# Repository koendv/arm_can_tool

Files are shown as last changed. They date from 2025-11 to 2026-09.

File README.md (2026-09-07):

# ARM CAN TOOL — Overview

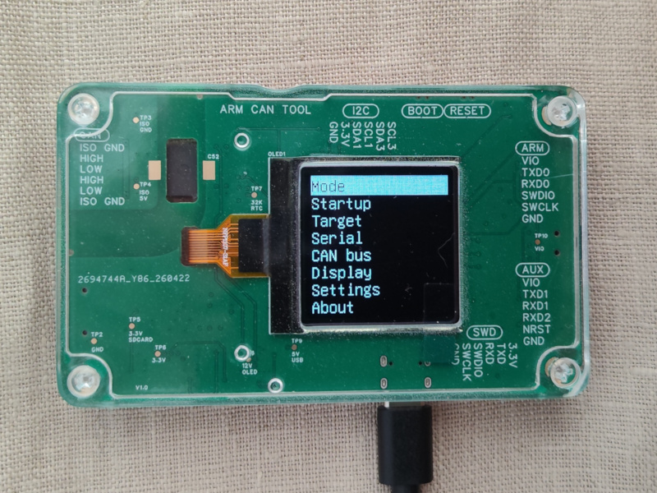
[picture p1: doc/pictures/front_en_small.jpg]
English
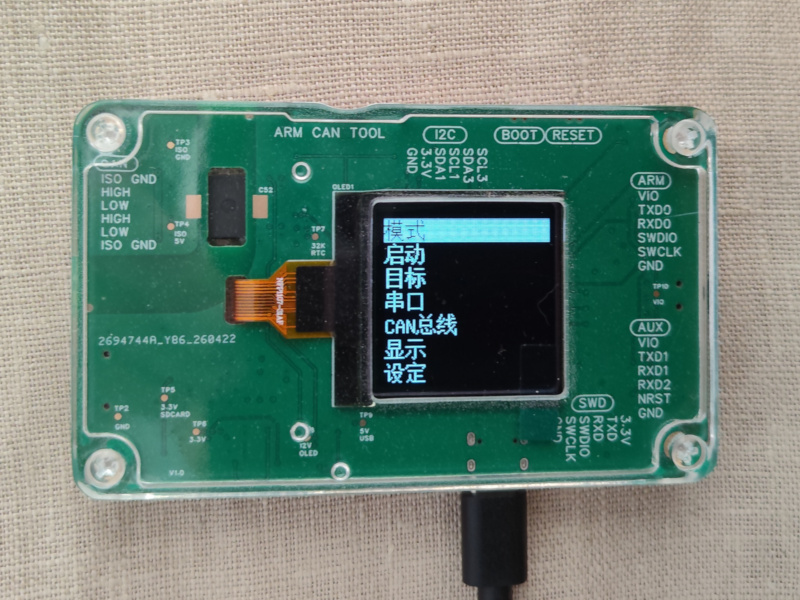
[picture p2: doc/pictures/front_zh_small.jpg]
Chinese
|||
|---|---|
|`English`|`Chinese`|

| Model | ARM CAN Tool |
|-|-|
| Hardware Version | V1.0 |
| Firmware Version | V1.4 |

- SWD/JTAG debug probe for ARM and RISC-V embedded systems
- Electrically isolated CAN 2.0A/B interface
- Debug output and CAN bus traffic merged into single USB serial log stream
- Standalone semihosting: target stdout, file I/O, and clock — no PC required
- ARM DWT program counter and exception trace
- Lua scripting for standalone use
- Automated logging to SD card
- User interface in English and simplified Chinese
- Documentation covers Linux host

---

## Quick Start

| Situation | Start here |
|---|---|
| Board has no firmware | [INSTALL](doc/INSTALL.md) |
| Board has firmware, want to use it | [TUTORIAL](doc/TUTORIAL.md) |
| Want to reproduce the board | [MANUFACTURING](doc/MANUFACTURING.md) |
| Want to sell the board | [COMMERCIAL](doc/COMMERCIAL.md) |
| Want to build or modify the firmware | [DEVELOPER](doc/DEVELOPER.md) |

---

## Document Map

This documentation is published as a set of Markdown files, and as an epub.

- [INSTALL](doc/INSTALL.md) — Install the UF2 bootloader and application firmware. Begin here if the board came from PCB assembly with no firmware.
- [TUTORIAL](doc/TUTORIAL.md) — A first session: wire a target, flash firmware, read the console, capture CAN frames, and log to SD card. Begin here if the board already has firmware installed.
- [OPERATION](doc/OPERATION.md) — How the device interface works: operating modes, OLED menu, serial ports, target power, and startup services.
- [DEBUG](doc/DEBUG.md) — Debug workflows using Black Magic Debug or CMSIS-DAP, plus memwatch, RTT, SWO, and MTB.
- [TARGETS](doc/TARGETS.md) — Supported targets.
- [CANBUS](doc/CANBUS.md) — The CAN bus interface: isolation, protocols, hardware filters, and logging.
- [SCRIPT](doc/SCRIPT.md) — Lua scripting: event model, deployment workflows, and flash sector layout.
- [LOGGING](doc/LOGGING.md) — SD card logging: file formats, retrieval, and combined log streams.
- [HARDWARE](doc/HARDWARE.md) — Hardware design, connectors, isolation, power, EMI, and repair.
- [SCHEMATIC](doc/SCHEMATIC.md) — PCB schematic.
- [AI](doc/AI.md) — How to use AI-assisted PCB design review and repair.
- [REMOTE](doc/REMOTE.md) — Console port use.
- [DEVELOPER](doc/DEVELOPER.md) — Build the firmware from source, software architecture, and internals.
- [MANUFACTURING](doc/MANUFACTURING.md) — Order PCBs, source components, assemble the enclosure, and install firmware.
- [LICENSE](LICENSE.md) — License terms for original work (CC0) and third-party components.
- [COMMERCIAL](doc/COMMERCIAL.md) — License terms, estimated cost, supply chain notes, and reseller information.
- [REFERENCE](doc/REFERENCE.md) — Static facts: connector pinouts, electrical parameters, and PCB parameters.
- [LUA REFERENCE](doc/LUA_REF.md) — Lua function reference.

---

## Specifications

| Parameter | Value |
|---|---|
| MCU | AT32F405, ARM Cortex-M4, 216 MHz |
| USB | USB 2.0 High Speed, 480 Mbit/s |
| Debug interfaces | SWD, JTAG |
| Target logic voltage range | 1.1 V – 3.6 V |
| Target power | 3.3 V, up to 100 mA |
| CAN interface | CAN 2.0A/B, up to 1,000,000 bit/s, electrically isolated |
| Storage | SD card, 16 MB SPI flash, 16 MB QSPI flash, EEPROM |
| Display | 1.5 inch OLED, 128×128, monochrome |
| Input | Multi-direction switch (up / down / press) |
| Firmware update | UF2 via USB mass storage |
| License | CC0 (Public Domain) |

---

## License

[CC0](https://creativecommons.org/publicdomain/zero/1.0/). Use, modify, and sell without restriction.

## Online Resources

| Resource | Location |
|---|---|
| Firmware source | [github arm_can_tool](https://github.com/koendv/arm_can_tool) |
| Bootloader source | [github at32f405-uf2boot](https://github.com/koendv/at32f405-uf2boot) |
| Hardware design | [oshwlab arm_can_tool](https://oshwlab.com/koendv/arm_can_tool) |

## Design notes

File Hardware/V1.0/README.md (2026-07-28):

# Manufacturing Instructions

## Quick Order Checklist

1. PCB: `Hardware/V1.0/4_GERBER/Gerber_PCB1_2026-04-13.zip`
2. BOM: `Hardware/V1.0/3_BOM/BOM_Board1_PCB1_2026-04-13.xlsx`
3. Pick & Place: `Hardware/V1.0/3_BOM/PickAndPlace_PCB1_2026-04-13.xlsx`
4. Enclosure STL: `Hardware/V1.0/5_3D/enclosure/`
5. Firmware: `Hardware/V1.0/7_FW/

## Assembly Notes

| component | note                                                   |
+-----------+--------------------------------------------------------|
| BT1       | No solder paste on middle pad of battery connector BT1 |
| OLED1     | DNS.                                                   |

## User responsibility

The PCB is shipped without pre-programmed firmware. The user is responsible for:

1. attaching OLED display (double-sided adhesive tape, FPC connector)
2. installing UF2 bootloader (one time, via DFU)
3. installing application firmware (routine, via USB copy)
4. 3D-printing the enclosure (SLA)

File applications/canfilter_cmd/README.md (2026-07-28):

# canfilter

**canfilter** is an RT-Thread MSH shell command for managing the bxCAN hardware acceptance filter. canfilter accepts human-readable CAN bus IDs and ID ranges and programs them into the canbus hardware filter configuration.

## Usage

```
canfilter [OPTIONS] [IDs/RANGES]
```

IDs: Single CAN IDs (0x100, 256)

RANGES: CAN ID ranges (0x100-0x1FF, 256-511)

| Option | Long form | Description |
| --- | --- | --- |
| -a | --allow-all | Allow all packets |
| -d | --dry-run | Print filter configuration without programming hardware |
| -v | --verbose | Enable verbose output (repeat up to three times) |
| -h | --help | Show help |

- Single IDs are interpreted as standard if <= 0x7FF, extended if <= 0x1FFFFFFF.
- Hex numbers are supported (prefix `0x`).
- Ranges are interpreted as extended if either bound is an extended ID.
- Repeating `-v` up to three times increases verbosity:
  - `-v` prints filter usage and programming result.
  - `-v -v` also prints a human-readable decode of each filter bank.
  - `-v -v -v` also dumps the raw hardware registers.

The filter takes effect on the next CAN bus start. To make the filter persistent across reboots, store settings using the menu or the rt-thread `settings` command.

## Examples

Allow a single standard ID:

```
canfilter 0x100
```

Program a standard ID range:

```
canfilter 0x100-0x1FF
```

Program mixed standard and extended IDs:

```
canfilter 0x100 0x200-0x2FF 0x1000 -v
```

Print filter configuration without programming hardware:

```
canfilter -d -v -v -v 0x101-0x1fe
```

Allow all traffic:

```
canfilter -a
```

## Source files

| File | Description |
| --- | --- |
| `canfilter_cmd.c` | MSH command, argument parsing, calls `can_set_filter()`  |
| `canfilter_bxcan_f0.c` | bxCAN filter builder: CIDR decomposition, bank packing  |
| `canfilter_bxcan_f0.h` | Public API for the filter builder |
| `canfilter.h` | Hardware filter struct definitions (`can_filter_t` etc.) |

## bxCAN filtering

bxCAN uses mask-based filtering. It has no native range support, so ranges are decomposed into a minimal set of (ID, mask) pairs using a CIDR aggregation algorithm — the same technique used for IP network prefix compression.

Each hardware filter bank holds either four standard IDs (16-bit list mode), two standard (ID, mask) pairs (16-bit mask mode), two extended IDs (32-bit list mode), or one extended (ID, mask) pair (32-bit mask mode). The builder packs entries as efficiently as possible.

The STM32F0/F1/F3 bxCAN peripheral has 14 filter banks. Filter usage is printed after every successful `canfilter` invocation. CIDR-aligned ranges use fewer banks:

```
canfilter -d 0x100-0x1FF
Filter usage: 1/14 (7%)

canfilter -d 0x101-0x1FE
Filter usage: 7/14 (50%)
```

The second range uses more banks because its boundaries are not aligned to a power-of-two block. If you run out of filter banks, consider adjusting your ranges to start and end on power-of-two boundaries.

## Notes

The core idea behind **canfilter** is that CAN bus hardware filters (ID + mask) are mathematically equivalent to IP network blocks (network + prefix). Because of this equivalence, CIDR aggregation — a mature algorithm for converting IP addresses and ranges into minimal sets of network blocks — can be applied directly to CAN identifiers.

The masks generated follow the same structure as IP network masks: a contiguous run of 1-bits from the most significant bit marking the portion of the CAN ID that must match, followed by 0-bits representing don't-care positions. A mask of all zeroes matches any CAN ID.

SEE ALSO

[canfilter](https://github.com/koendv/canfilter)

## License

Public domain — [CC0 1.0 Universal](https://creativecommons.org/publicdomain/zero/1.0/).

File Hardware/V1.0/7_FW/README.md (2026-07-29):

# Firmware for ARM CAN Tool V1.0

## Governing Principle

The AT32F405 processor uses two separate memory regions for firmware. The internal flash (256 kB) contains the UF2 bootloader, installed once via DFU. The QSPI flash (16 MB) contains the application firmware, updated by copying a UF2 file to a USB mass storage device.

## Prerequisites

- `dfu-util` installed (`sudo apt install dfu-util` on Debian-based systems)
- USB cable (data-capable)
- Ability to identify and press [RESET] and [BOOT0] buttons on the board

## File Overview

Download from [Releases](https://github.com/koendv/arm_can_tool/releases):

| File | Purpose |
|---|---|
| `cherryuf2_arm_can_tool.bin` | UF2 bootloader |
| `rtthread.uf2` | Application firmware |

---

## Installing the UF2 Bootloader (One Time Only)

**Governing Principle:**
The AT32F405 contains a factory DFU bootloader accessible by holding [BOOT0] during reset. The UF2 bootloader is written to internal flash using `dfu-util`.

**Prerequisites:**
- `dfu-util` installed
- Board connected via USB
- `cherryuf2_arm_can_tool.bin` downloaded from [at32f405-uf2boot Releases](https://github.com/koendv/at32f405-uf2boot/releases)

**Procedure:**
1. Press and hold [RESET] and [BOOT0] simultaneously.
2. Release [RESET] after one second.
3. Release [BOOT0] after one further second.

The board is now in DFU mode.

**Verification:**
```bash
$ lsusb | grep Artery
Bus 003 Device 012: ID 2e3c:df11 Artery-Tech DFU in FS Mode
```

**Procedure (continued):**
4. Write the bootloader binary:
```bash
dfu-util -a 0 -d 2e3c:df11 --dfuse-address 0x08000000 \
         -D cherryuf2_arm_can_tool.bin
```

**Expected output:**
```
Erase       [=========================] 100%        23692 bytes
Erase    done.
Download    [=========================] 100%        23692 bytes
Download done.
File downloaded successfully
```

**Verification:** The bootloader requires installation only once. Normal boot (without [BOOT0] held) starts the application.

⚠️ **Warning: Linux USB Access**

**If ignored:** `dfu-util` reports "No DFU capable USB device found"

**Correct practice:** Add udev rule:
```bash
echo 'SUBSYSTEMS=="usb", ATTRS{idVendor}=="2e3c", ATTRS{idProduct}=="df11", TAG+="uaccess", MODE="0664", GROUP="plugdev"' | sudo tee /etc/udev/rules.d/99-at32.rules
sudo udevadm control -R
```

**Complete precautions:** See [HARDWARE.md#usb-dfu-setup]

---

## Installing the Application Firmware (Routine)

**Governing Principle:**
The UF2 bootloader presents the QSPI flash as a USB mass storage device. The application firmware installs by copying a UF2 file to this device.

**Prerequisites:**
- UF2 bootloader installed (see previous section)
- Board connected via USB
- `rtthread.uf2` downloaded from [Releases](https://github.com/koendv/arm_can_tool/releases)

**Procedure:**
1. Press and hold [RESET] and the multi-direction switch simultaneously.
2. Release [RESET] after one second.
3. Release the multi-direction switch after one further second.

The green LED illuminates. A USB mass storage device named `CherryUF2` appears.

**Verification:**
```bash
$ ls /media/$USER/CherryUF2/
CURRENT.UF2
```

**Procedure (continued):**
4. Copy the application firmware:
```bash
cp rtthread.uf2 /media/$USER/CherryUF2/CURRENT.UF2
```

**Expected behavior:**
- LED blinks during programming
- Board resets automatically when complete
- OLED display shows the main menu

**Verification:** The serial console (SWD connector, 115200 baud) displays:
```
I/MAIN: ready
```

---

## Troubleshooting

| Observed Result | Possible Cause | Corrective Action |
|---|---|---|
| `CherryUF2` drive does not appear | UF2 bootloader not installed | Install bootloader (see previous section) |
| `dfu-util` reports no device | Missing udev rule or driver | Apply udev rule (Linux) or use Zadig (Windows) |
| Copy operation fails | Loose USB connection | Use different cable or USB port |
| OLED remains blank after reset | Application firmware corrupt | Re-enter UF2 mode and copy `rtthread.uf2` again |

---

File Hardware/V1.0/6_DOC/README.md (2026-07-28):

# PCB Analysis YAML — AI Assistant Guide

Upload `pcb_analysis.yaml` to an AI chatbot and have a technical conversation about your board — design review, signal integrity, power, EMC, BOM, firmware bring-up. The AI gets full context in one file.

Component datasheets are in `6_DOC/datasheets/`.

---

## Quick Start

1. Open [claude.ai](https://claude.ai) (or any capable AI chatbot)
2. Upload `pcb_analysis.yaml` as an attachment
3. Start broad: *"Assess this PCB. Project description is at https://github.com/koendv/arm_can_tool"*

The AI now has full context and you can drill down from there.

---

## Example Prompts

> *"What items in the design checklist still require action before I send to fab?"*

> *"What are the main functional blocks of this board and how are they connected?"*

> *"Which nets need controlled impedance routing, and what trace width should I use?"*

> *"Are there any assembly notes I need to communicate to the fab?"*

> *"I've attached the datasheets for U5 (SD8931) and its alternate (DS3231MZ). Compare and assess what would need to change to swap them."* (Note: the DS3231MZ datasheet is in English, the SD8931 in Chinese — the AI handles both.)

> *"I've attached the CA-IS2062VW datasheet. Check the schematic for U3 against the reference application circuit."*

> *"Assume CAN bus transceiver creepage is 9mm, clearance is 7mm, and PCB has CTI≥175V. Assess according to IEC 60664-1."*

---

## Tips for Better Conversations

**Be specific about the subsystem.** The AI can focus better when you name a block:
> *"Focus on the I2C bus. Which devices share I2C1, and are the pull-up resistors sized correctly?"*

**Ask for a checklist.**
> *"Create a pre-fab checklist based on the open items in this design."*

**Use the embedded datasheets.** Every component in the YAML includes a datasheet URL. Ask the AI to fetch and cross-reference them:
> *"Check the datasheet for U3 and verify the decoupling capacitors match the recommended application circuit."*

**Attach additional documents sparingly.** You can upload datasheets or reference manual sections alongside the YAML. Avoid uploading an entire MCU reference manual — extract and upload only the relevant section, for example the QSPI/XIP chapter when working on flash memory bring-up.

**Use alternate parts for cost reduction.** The YAML includes schematic-documented alternates with LCSC part numbers. Two levels of search:

Focused — uses only designer-validated alternates already in the schematic:
> *"Using the alternate parts listed in the schematic, consider replacing parts with Chinese domestic alternatives. Give BOM savings."*

Open — broader search for any cheaper compatible part on LCSC:
> *"Search LCSC for cheaper Chinese domestic alternatives to any part in the BOM. Include the schematic's documented alternates and any other compatible parts you find. Give BOM savings."*

The focused query is safer and faster. The open query may find additional savings but results need engineering review before production.

**Iterate.** The AI retains the YAML context for the whole conversation. You can ask follow-up questions without re-uploading.

---

## Generating pcb_analysis.yaml

To regenerate this file for this board, or create one for a different EasyEDA Pro project:

1. Export BOM, netlist, and pick & place files from EasyEDA Pro
2. Run [easyeda_parser](https://github.com/koendv/easyeda_parser)
3. Upload the schematic PDF and the parser output
4. Merge into `pcb_analysis.yaml`

---

*Project: `arm_can_tool` · Author: koendv · License: [CC0 Public Domain](https://creativecommons.org/publicdomain/zero/1.0/)*

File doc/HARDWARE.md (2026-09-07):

# ARM CAN TOOL — Hardware Reference

> Workflow is not: Given specifications, design hardware.

> Workflow is: Given product concept and manufacturing process, extract full performance.

> If the solution is complex, backtrack to when it was simple.

**Hardware Revision:** v1.0

**Intended Readers:** Electronics engineers evaluating the design, planning a board modification, or selecting components for production.

---

## Prerequisites

**Knowledge:**

- Basic electronics measurement (multimeter use)
- SMD soldering and rework
- I2C and SPI interfaces

**Equipment:**

- Multimeter
- USB-C cable
- Terminal emulator (Linux: minicom; Windows: PuTTY)
- Oscilloscope or frequency counter (crystal verification)

---

## Design Principles

### Hardware Policy

Hardware has to be right the first time. Software we can always update later.

### Second Source Components

Single-source components are a supply chain risk. Where possible, components have a second source.

| Component | Primary | Second Source |
| --- | --- | --- |
| AT32F405 MCU | Artery Technology | None ⚠️ |
| CA-IS2062VW CAN transceiver | Chipanalog | CA-IS3062VW (drop-in), NSIP9042V-DSWR (pin-compatible) |
| SH1107 128×128 OLED display | Zhongjingyuan (中景园) | None. Alternative requires connector and/or driver change. |

Monitor stock before committing to a production run.

### Economy Assembly

Design targets JLCPCB Economy PCBA throughout.

- All components are SMD. No through-hole parts, no headers, no press-fit connectors.
- Board leaves SMT assembly 100% soldered. Manual steps after assembly: attach OLED display (plug-in FPC), close enclosure.
- All connectors are JST GH 1.25 mm pitch, 6-pin.
- OLED uses a plug-in FPC connector. Reason: JLCPCB economy assembly does not include hot-bar soldering.
- All components are either stocked by JLCPCB, available for consignment or both.
- No conformal coating, no selective soldering, no unusual PCB finishes.
- PCB stackup JLC04161H-7628 (4-layer) is a standard JLCPCB offering. Standard stackup avoids surcharges and provides consistent impedance control across repeat orders.

### Simple Solutions Preferred

If a simple approach solves 90% of use cases, do not choose a complex approach to solve 95%.

### Accept Hardware Limitations

The cost and complexity of upgrading or supplementing a component are often underestimated. Accept the limitation instead, and extract full performance from what is fitted. Example: the AT32F405 supports CAN 2.0 but not CAN FD. Alternatives — a more capable MCU (STM32U595) or an external CAN FD controller (MCP2518FD) — increase cost or complexity. Instead, accept CAN 2.0 and use the controller to full capacity: use AT32 HAL instead of rt-thread, use hardware filtering instead of software filtering. No CPU load. Lean and cheap.

### PCB Layout

A well-routed board and a poorly-routed board cost the same to manufacture.

### Repairability

Component placement provides practical rework access — sufficient clearance to drag a soldering iron across the pins of every SOIC and LQFP package. The processor area accommodates an LQFP-64 10×10 mm body without moving other components, permitting a processor swap on a future board spin.

LQFP-64 package selection:

| Package | Assessment |
| --- | --- |
| LQFP-48 | Insufficient pin count |
| LQFP-64 | Sufficient pins, hand-solderable, hand-reworkable |
| LQFP-100 and above | Excess pins, higher cost, reduced reworkability |

### Debug Interface

The debug interface supports up to four bidirectional pins, each with individual level translation and direction control. This accommodates SWD, JTAG, and manufacturer-proprietary debug protocols without hardware changes.

A SWD-only design could connect SPI MOSI and MISO directly to the target SWDIO. This was considered and rejected. Four GPIOs are used, with voltage translation and individual direction control, to permit programming of devices using proprietary protocols.

All four signal pins and their four direction control pins are on GPIO port A (PA0–PA7). A single register write updates all eight pins simultaneously. See [bit-banging](DEVELOPER.md#gpio-and-bit-banging).

---

## Design Files

| Resource | Location |
| --- | --- |
| Schematics and Gerbers | [Design files](https://github.com/koendv/arm_can_tool/tree/main/Hardware) |
| EasyEDA / OSHWLab project | [oshwlab.com/koendv/arm_can_tool](https://oshwlab.com/koendv/arm_can_tool) |

Designed using [EasyEDA Pro](https://pro.easyeda.com/). All design files published under CC0.

---

## Block Diagram

Block diagram

*System block diagram.*

The board contains two SPI flash chips. The 16 MB QSPI flash stores firmware and is executed in place (XIP) at 108 MHz. The 16 MB SPI flash stores data such as log files and Lua scripts. The QSPI flash is written by the bootloader. The SPI flash is managed by the rt-thread filesystem.

---

## Processor

The [AT32F405](https://www.arterychip.com/en/product/AT32F405.jsp) is an ARM Cortex-M4 microcontroller manufactured by Artery Technology (雅特力).

| Parameter | Value |
| --- | ----- |
| Core | ARM Cortex-M4 |
| Clock | 216 MHz |
| RAM | 102 kB (parity check disabled) / 96 kB (parity check enabled) |
| Internal flash | 256 kB (6 wait states at 216 MHz; prefetch buffers enabled) |
| USB | High Speed (480 Mbit/s) and Full Speed, internal PHY |
| QSPI | Four-wire, up to 108 MHz |
| Package | LQFP-64, 7×7 mm body |

> The AT32F405 has 102 kB RAM when RAM parity check is disabled (the default). If the bootloader reports `96k ram`, the processor option bits require a reset.

### Processor Evaluation

The AT32F405 satisfies the combined ARM debug and CAN 2.0 probe use case: USB High-Speed with integrated PHY, Cortex-M4 at 216 MHz, and LQFP-64 package. CAN FD is not supported.

CAN FD support would require:

- Transceiver change to NSIP9042-DSWR
- Common mode choke change to ACT1210D-510-2P-TL00
- Processor with CAN FD capability

No current AT32 device offers both USB High-Speed and CAN FD. The AT32F456/F457 add CAN FD but revert to Full-Speed USB, making them unsuitable for this application. A pin-compatible AT32F405 variant with CAN FD would close this gap, but no such part currently exists.

### Processor Replacement

If the AT32F405 becomes unavailable or a CAN FD variant is required, the replacement must satisfy:

- USB High-Speed (not Full-Speed) with integrated PHY
- CAN FD
- LQFP-64 package preferred
- rt-thread BSP available (official or community)

Candidate devices include Nuvoton M3334SIGAE (community rt-thread BSP: [github.com/wosayttn/sdk-bsp-numaker-m3334ki](https://github.com/wosayttn/sdk-bsp-numaker-m3334ki)), STM32U595RJT6.

A PCB respin is required for a different processor. The current board layout has sufficient clearance around the processor footprint to accommodate an LQFP-64 10×10 mm body without moving other components. A 10×10 mm body increases pin pitch, which may permit HASL PCB finish in place of ENIG, reducing cost.

---

## Storage

| Device | Interface | Capacity | Purpose |
| --- | --- | --- | --- |
| W25Q128JVSIQ | QSPI, 108 MHz | 16 MB | Firmware storage, XIP execution |
| W25Q128JVSIQ | SPI | 16 MB | Filesystem (log files, scripts). May be partitioned for target firmware image storage. |
| SD card | SPI | User supplied | Removable log and script storage |
| 24C64 EEPROM | I2C | 64 kbit (8 kB) | Device settings |
| SD8931 | I2C | 70 bytes | Unused |

---

## Connectors and Pinouts

All connectors are JST GH 1.25 mm pitch, 6-pin.

For a quick-reference pinout table, see [REFERENCE.md](REFERENCE.md).

**ARM Connector**: Provides the debug interface to the target. In SWD mode, pins 2 and 3 carry serial0 (target console). In JTAG mode, pins 2 and 3 carry TDI and TDO.

⚠️ **Warning: serial0 and JTAG pin contention.**
In JTAG mode, the UART peripheral and the JTAG driver both attempt to drive pins 2 and 3 simultaneously. This causes electrical contention and possible damage. Disable serial0 before switching to JTAG mode: `Serial → Serial Enable → serial0 → Off`.

Pinout: see [REFERENCE.md](REFERENCE.md#arm-pinout).

**AUX Connector**: Provides serial1, serial2 (SWO), and the target reset signal.

Pinout: see [REFERENCE.md](REFERENCE.md#aux-pinout).

**SWD Connector (Probe Self-Debug)**: The debug interface of the AT32F405 itself — for debugging the probe firmware, not the target. Console: 115200 baud, 8N1.

Pinout: see [REFERENCE.md](REFERENCE.md#probe-swd-pinout).

**CAN Bus Connector**: Carries the isolated CAN signals. CAN_HIGH and CAN_LOW are duplicated on two pin pairs for daisy-chain wiring.

Pinout: see [REFERENCE.md](REFERENCE.md#can-bus-pinout).

> No internal terminating resistors. If the probe is the last device on the bus and termination is required, connect 120 Ω across CAN_HIGH and CAN_LOW at the connector.

### CAN Bus Adapter Cable

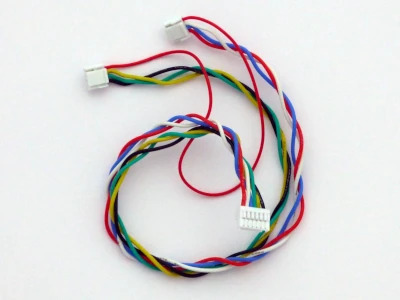
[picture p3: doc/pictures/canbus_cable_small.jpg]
CAN bus cable


*CAN bus adapter cable.*

The CAN bus connector is 6-pin GH1.25. An adapter cable is required to connect to a standard 4-Pin GH1.25 CAN bus.

| Option | Notes |
| --- | ----- |
| [LCSC custom cables](https://www.lcsc.com/customcables) | Suitable for production quantities. |
| AliExpress "GH1.25 Connectors and Pre-Crimped Silicone Cables" | Suitable for individual users. |

Wiring diagram: [canbus_cable.pdf](pictures/canbus_cable.pdf)

**I2C Connector.** May be used as two independent I2C buses, or as one I2C bus (I2C1) with two GPIO pins (PC0, PC1), e.g. as I2C ALERT and RESET inputs.

Pinout: see [REFERENCE.md](REFERENCE.md#i2c-pinout).

I2C1 is the internal bus, carrying the SD8931 RTC (0x68) and the 24C64 EEPROM (0x50). I2C1 is always active.

> **I2C1 caution:** External devices connected to I2C1 share the bus with the internal RTC and EEPROM. An address conflict or a device that stalls the bus will cause settings save and RTC operations to fail. Use I2C3 for external devices.

I2C3 is available for external devices. When I2C3 is not needed, PC0 and PC1 are available as general-purpose GPIO. PC1 (I2C3\_SDA) doubles as the external trigger input. When external trigger is enabled, I2C3 is not available. PC0 (I2C3\_SCL) is available as a general-purpose GPIO output; suggested use is a device RESET line.

The first four pins (GND, 3.3V, I2C1\_SDA, I2C1\_SCL) are in the same order as the SparkFun QWIIC connector standard. A QWIIC adapter cable connects straight through on pins 1–4 without rewiring.

---

## Voltage Translators and Target Power

The probe operates at 3.3V internally. ARM and AUX connector signals are translated to the target logic voltage by SN74AVC4T774 level translators. The VIO pin must be connected to the target logic supply for the translators to operate correctly.

The SN74AVC4T774 accepts logic voltages from 1.1V to 3.6V on the VIO side. 100 kΩ pull-ups to VIO are provided on the SWD and JTAG pins, as required by the ARM Debug Interface Architecture.

### VIO Connection Options

| Option | Condition | Method |
| --- | --- | --- |
| Connect VIO to target VCC | Always preferred | Wire VIO to target logic supply |
| Connect VIO to probe 3.3V | Only if target logic voltage is 3.3V | Enable **3.3V Power** in **Target** menu, or use `mon tpwr ena` in GDB |

⚠️ **Warning: VIO contention.**

**Consequence:** If **3.3V Power** is enabled and the target also drives VIO from its own supply, both sources contend on the VIO line. This may damage the target, the probe, or both.

**Correct practice:** Enable **3.3V Power** only when the target has no independent logic supply on VIO.

A load switch on the 3.3V power output limits inrush current when the target is connected. The probe can supply approximately 100 mA to the target. This is a guideline, not a guaranteed specification.

**Enabling target power from GDB:**

```
$ arm-none-eabi-gdb
(gdb) target extended-remote /dev/ttyACM1
(gdb) monitor tpwr ena
```

Expected output:

```
Enabling target power
```

```
(gdb) monitor tpwr dis
```

Expected output:

```
Disabling target power
```

**Enabling target power from menu:**

`Target → 3.3V Power → On`

### Level Translator Substitution

The SN74AVC4T774 is pin-compatible with several other level translator families and may be substituted to achieve a different target voltage range.

> **74AXC4T77 pull-down note.**
> The SN74AXC4T774 has internal weak pull-downs on its inputs. Together with the external pull-ups, these form a voltage divider. Avoid.

---

## Target Reset

The target reset circuit separates the reset output (driven by the probe) from the reset input (which may be driven by the target or its own reset button). The probe can detect whether the target is held in reset independently of whether the probe asserted it.

| Signal | Direction | Description |
| --- | --- | --- |
| T_RST_OUT | Output | Driven low by the probe to reset the target |
| T_RST_IN | Input | Low when the target is in reset, from any source |

Some processors require reset to be asserted during SWD or JTAG connection.

**Manual reset:** Press the target reset button briefly while initiating the debugger connection.

**Automated reset via NRST pin:** Connect AUX connector pin 5 (NRST) to the target reset line, then configure the debugger.

Black Magic Debug:
```
(gdb) monitor connect_rst enable
```

OpenOCD:
```
reset_config srst_only srst_push_pull connect_assert_srst
```

**Reset target at any time from GDB:**
```
(gdb) monitor reset
```

---

## Real-Time Clock

The fitted RTC is the [Wave](https://www.whwave.com.cn) SD8931, operated in DS3231-compatible mode. Register-compatible with the DS3231 at addresses 0x00–0x12. I2C address: 0x68.

**Battery:** CR1220. Without battery, RTC loses its setting when USB power is removed.

The SD8931 and DS3231M are pin-compatible if the RST pin is not used.

### SD8931 vs DS3231M

| Parameter | DS3231M | SD8931 |
| --- | --- | --- |
| Timekeeping accuracy | ±5 ppm, −45°C to +85°C | ±2 ppm (0–40°C) / ±3.5 ppm (−40–85°C) |
| Supply voltage (VDD) | 2.3V – 5.5V | 2.5V – 5.5V |
| Timekeeping voltage (VBAT min) | 2.3V | 1.5V |
| Operating temperature | −45°C to +85°C | −40°C to +105°C |
| I2C speed | 400 kHz | 400 kHz |
| Oscillator type | Internal MEMS resonator | Internal crystal + digital temp compensation |
| Temperature sensor | 10-bit, ±3°C | 9-bit, accuracy unspecified |
| VDD standby current | 130 µA typ | 0.5–0.6 µA typ |
| VBAT timekeeping current | 2–3 µA typ | 0.5 µA typ |
| User SRAM | No | 70 bytes (0x6C–0xB1) |
| Battery voltage ADC | No | Yes — 9-bit VBAT measurement |
| Sub-second register | No | Yes — 10-bit, 1/1024s resolution |
| Unique chip ID | No | Yes — 8 bytes, factory set |

On the same battery, a SD8931 lasts longer than a DS3231M.

---

## CAN Bus Isolation

The CAN bus interface is galvanically isolated from the probe ground using the CA-IS2062VW isolated CAN transceiver. This device integrates the isolation barrier and an isolated 5V power supply. No external isolated supply is required.

Clearance and creepage distances are given in good faith. This design is not certified for safety or regulatory compliance. Do not use for safety or regulatory compliance.

| Parameter | CA-IS2062VW | FR4 PCB |
| --- | --- | --- |
| CTI | ≥ 600 V | ≥ 175 V |
| Clearance | 8 mm | 7 mm |
| Creepage | 8 mm | 9 mm |

PCB clearance is 8.0 mm without the OLED flex cable installed. With the flex cable routed through the isolation barrier slot, effective clearance may be reduced to 7.0 mm.

⚠️ **Warning: isolation limitations.**

**Consequence:** Standard FR4 (CTI ≥ 175 V) is not rated for certified high-voltage isolation applications. Flux residue may create leakage paths in the presence of humidity or condensation. No conformal coating is applied.

**Correct practice:** Use this design only in clean, controlled environments. Do not use in the presence of moisture, condensation, dust, oils, salts, or airborne chemicals.

The isolated CAN bus interface is also available as a [dedicated separate board](https://oshwlab.com/koendv/canbus_module).

---

## CAN Bus Transceiver

The CA-IS2062VW and CA-IS3062VW are interchangeable for this design. Use whichever is available at time of ordering.

The NSIP9042V-DSWR (Novosense) is pin-compatible and adds CAN FD support at 5 Mbit/s. Noted here for engineers evaluating a CAN FD upgrade path.

All three devices share the SOW/SOIC-16 wide-body package (10.30 × 7.50 mm) and identical pinout.

### Electrical Comparison

| Parameter | CA-IS2062VW | CA-IS3062VW | NSIP9042V-DSWR |
| --- | --- | --- | --- |
| VCC/VDD range | 4.5–5.5 V | 4.5–5.5 V | 4.5–5.25 V |
| VCCL/VDDL range | 2.375–5.5 V | 2.375–5.5 V | 1.8–5.5 V |
| Max data rate | 1 Mbps | 1 Mbps | 5 Mbps (CAN FD) |
| Isolation voltage (UL1577) | 5000 VRMS | 5000 VRMS | 5000 VRMS |
| CMTI (typ) | ±150 kV/µs | ±150 kV/µs | ±150 kV/µs |
| Bus fault protection | ±58 V | ±58 V | ±58 V |
| Bus pin ESD (HBM) | ±6 kV | ±6 kV | ±8 kV |
| TXD dominant timeout | 2–8 ms | 2–8 ms | 0.8–5 ms |
| Operating temperature | −40 to 125 °C | −40 to 125 °C | −40 to 125 °C |

### CA-IS2062VW vs CA-IS3062VW

The CA-IS3062VW adds explicit under-voltage lockout (UVLO) with documented behaviour for the dual-supply case (VCC powered, VCCL unpowered → CANH/CANL normal, RXD high-Z). The CA-IS2062VW datasheet does not define this behaviour. All other specifications are identical. Both are acceptable for this design.

---

## CAN Bus Y-Capacitor

The PCB provides unpopulated pads for a Y-rated capacitor across the CAN bus isolation boundary. A Y-capacitor provides a low-impedance path for high-frequency common-mode noise, which can restore CAN signal integrity when EMI is the root cause of communication problems.

⚠️ **Warning: Y-capacitor reduces isolation.**

**Consequence:** With the Y-capacitor populated, the two ground domains are coupled at high frequencies. DC and low-frequency isolation remain intact. High-frequency isolation is no longer complete.

**Correct practice:** The Y-capacitor is a diagnostic tool only. Remove before returning to normal isolated operation.

**Suitable parts:**

| Part | Value | LCSC |
| ---- | ----- | ---- |
| TRX TMY1102M | 1 nF, 400 VAC | C2685703 |
| TRX TMY1222M | 2.2 nF, 400 VAC | C2685704 |

**Diagnostic procedure:**

1. If the CAN bus exhibits bit errors, frame loss, or instability, solder a 1 nF Y-capacitor.
2. If the problem resolves, EMI is confirmed as the root cause.
3. If 1 nF is insufficient, try 2.2 nF. Larger values increasingly compromise high-frequency isolation.
4. Investigate and implement a permanent EMI mitigation strategy.
5. Remove the Y-capacitor.

---

## Power Supply

The ARM CAN Tool is powered from the USB-C connector. The USB power rail connects directly to the CAN bus transceiver and the switching power supply.

⚠️ **Warning: absolute maximum input voltage.**
Both the CAN bus transceiver and the switching power supply have an absolute maximum rating of 6.0 V. Exceeding this will permanently damage both components. Nominal supply: 5.0 V. Do not exceed 6.0 V under any condition.

| Parameter | Value |
| --- | ----- |
| Nominal input voltage | 5.0 V |
| Operating range | 4.5 V – 5.5 V |
| Absolute maximum | 6.0 V |
| Connector | USB-C |

### Internal Power Rails

| Rail | Nominal | Reference | Description |
| ---- | --- | --- | --- |
| 5V USB | 5.0 V | GND | From USB connector |
| 3.3V | 3.3 V | GND | Main probe supply |
| 12V OLED | 12.1 V typical | GND | OLED panel supply |
| 3.3V SD | 3.3 V | GND | SD card supply. Switched by firmware. |
| VIO | 1.1 V – 3.6 V | GND | Target logic voltage |
| ISO 5V | 5.1 V | ISO GND | Isolated CAN transceiver supply |

---

## PCB Design Notes

### Component Placement

All components are on the component side of the board. The display side carries only the OLED display and silkscreen legends — connector pin names and labels.

All connectors, switches, the LED, and the SD card slot are placed at PCB edges, accessible through the enclosure walls without disassembly.

Connector legends are printed on the PCB silkscreen. The display-side enclosure is 3D-printed in transparent SLA resin so the silkscreen is readable through the enclosure wall.

### High-Speed Signal Integrity

**USB 2.0 High Speed (480 Mbit/s):** USB-C connector pins are centered on the MCU USB pins. Traces between MCU and USB-C connector are straight, 17 mm long, 10 mil trace, 6 mil space, no vias, no bends.

**QSPI Flash (108 MHz):** All four QSPI data lines, clock, and chip select are length-matched and impedance-controlled.

**Return current paths:** For SPI2_MISO and AUX_SWO traces on the bottom layer, the VCC plane beneath the traces is replaced with a ground plane to provide a low-impedance return current path.

Check trace/space with JLC [impedance calculator](https://jlcpcb.com/pcb-impedance-calculator).

Check Gerbers with JLC [DFM Design for Manufacturing](https://jlcdfm.com/).

### SD Card Hot Insertion

The SD card connector supports hot insertion. SD cards may present up to 10 µF of bulk capacitance at insertion. A load switch limits inrush current.

### JLCPCB Order Number Placement

The JLCPCB order number position is specified in the design to prevent placement within the CAN bus isolation barrier. Silkscreen ink within the barrier reduces the maximum allowable isolation voltage. See [COMMERCIAL.md](COMMERCIAL.md) for ordering instructions.

### Stackup

PCB stackup: JLC04161H-7628 (4-layer).

---

## OLED Display Selection

The SH1107 controller driving a 128×128 monochrome OLED was selected on the following criteria, in order:

1. Monochrome 1bpp — small frame buffer (2 kB); color requires too much RAM.
2. SPI interface — more reliable than I2C: does not stall, even when display is unplugged
3. Fastest available controller for the frame size

| Parameter | Value |
| --- | ----- |
| Driver | SH1107 |
| Resolution | 128×128 |
| Interface | 4-wire SPI |
| Logic supply (VDD) | 3.3 V |
| Display supply (VCC) | 12 V |
| VCC current | 32 mA max |
| Connector | 12-pin FPC, plug-in type |
| Manufacturer | Zhongjingyuan (中景园) |
| Taobao (item) | [item.taobao.com/item.htm?id=676644812043](https://item.taobao.com/item.htm?id=676644812043) |
| Taobao (store) | [oled-zjy.taobao.com](https://oled-zjy.taobao.com) |

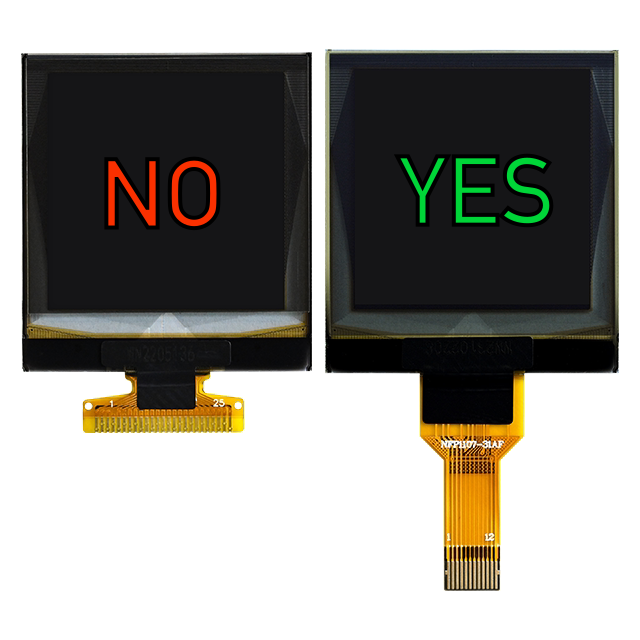
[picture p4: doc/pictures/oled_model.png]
OLED FPC


⚠️ **Two variants exist with different connectors.** The correct variant uses a 12-pin plug-in FPC connector (插接式裸屏). A second variant uses a 25-pin soldering FPC connector and is not compatible with this PCB.

### Alternative OLED: SH1108 160×128

A SH1108 controller driving a 160×128 display is a possible alternative.

SH1108 160×128 OLED:

- [swicn](https://swicn.com/products/1-92-inch-pmoled-display-128x160-resolution-sh1108-driver-parallel-serial-i2c-interface)
- [alibaba](https://www.alibaba.com/product-detail/1-92-Inch-PMOLED-Display-128x160_1601765833765.html)

**Software change required** (`mui_app.c`):

```c
// Current:
u8g2_Setup_sh1107_128x128_f(...)

// Alternative:
u8g2_Setup_sh1108_128x160_f(...)
```

Menu layouts would need to be reviewed and adapted for the additional space.

**Hardware change required:** The SH1108 uses a 31-pin, 0.3 mm pitch FPC connector.

---

## EMI Considerations

The QSPI flash interface operates at 108 MHz, which falls at the upper end of the FM radio band. Radiated emissions from the QSPI traces are the primary EMI source.

Placing an FM radio antenna 1–2 cm above the component side of the board, tuned to 108 MHz, will detect interference when the probe is connected to USB. At a distance of 10–30 cm the effect is not detectable. In most applications EMI shielding is not required.

### Shielding Options

Three approaches in order of increasing complexity.

**Option 1 — Copper foil inside the enclosure:**
Line the inside of the component-side enclosure with 3M 1181 adhesive copper foil (0.066 mm thick, conductive adhesive). Strips have to overlap. The foil must make electrical contact with the PCB ground plane.

**Option 2 — Conductive paint inside the enclosure:**
Apply conductive spray paint to the inside of the component-side enclosure. Suitable products: Kontakt Chemie EMI 35, MG Chemicals 842AR.

**Option 3 — PCB shield cans:**
Solder EMI shielding clips to the PCB (e.g. LCSC C238199, ICSRC6508SFR) and attach shield cans.

⚠️ **Warning: shield grounding and isolation.**
Three of the four screw mounting pads are connected to probe GND; one is connected to isolated CAN GND. Shielding that contacts both ground domains will short-circuit the isolation barrier. Shielding must contact only probe GND pads.

### Verified Shielding Configuration

- Material: 0.06 mm adhesive copper foil
- Position: 5 mm above the PCB ground plane
- Insulation: Kapton sheet between foil and components

> Adding this shielding reduces the CAN bus isolation clearance from 7 mm to 5 mm.

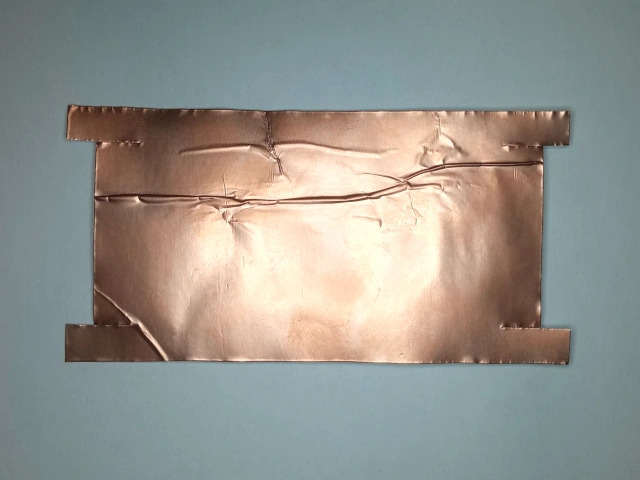
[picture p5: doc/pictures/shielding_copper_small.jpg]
Copper foil
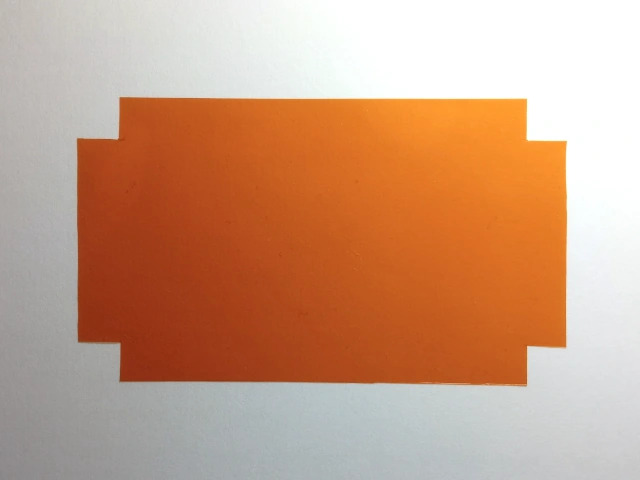
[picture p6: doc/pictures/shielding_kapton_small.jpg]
Kapton layer
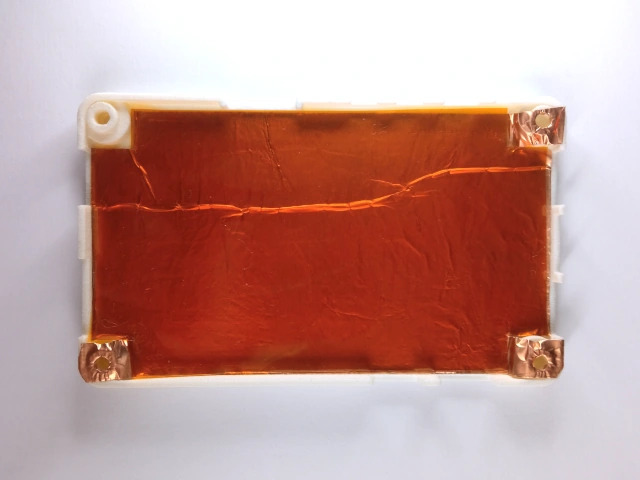
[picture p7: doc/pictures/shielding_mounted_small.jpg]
Assembled
|  |  |  |
|---|---|---|
| Copper foil | Kapton insulation | Assembled shielding |

---

## Hardware Extension

The I2C connector is the recommended interface for adding external hardware. It provides both I2C buses and, optionally, two GPIO pins (PC0, PC1).

| Resource | Description |
| --- | --- |
| I2C1 | Internal bus carrying RTC and EEPROM. Available for external devices — see I2C1 caution above. |
| I2C3 | Independent I2C bus with no internal devices. Preferred for external peripherals. |
| PC1 | I2C3_SDA. Available as GPIO when I2C3 not in use. Doubles as external trigger input. |
| PC0 | I2C3_SCL. Available as GPIO when I2C3 not in use. Suggested use: device RESET output. |
| PCB area | Space between the USB connector and the switching power supply is available for a battery charger IC. |
| GPIO PB1 | One free GPIO pin, available as a SPI chip select for an additional SPI device. |

---

## Designed for Repair

Component placement provides practical rework access — sufficient clearance to drag a soldering iron across the pins of every SOIC and LQFP package. The processor area accommodates an LQFP-64 10×10 mm body without moving other components.

### Rework Procedure — SOIC and LQFP Components

Applies to voltage level translators, the CAN bus transceiver, and the processor.

**Prerequisites:**

- Soldering iron with fine tip
- Soldering microscope
- Scalpel or sharp cutter
- Copper braid (solder wick)
- Flux
- Isopropyl alcohol
- Kapton tape

**Procedure:**

1. Cover adjacent components with Kapton tape, leaving only the component to be replaced exposed.
2. Under the microscope, use a scalpel to cut through each pin between the component body and the pad.
3. Remove the component body.
4. Apply flux. Unsolder the remaining pin stubs one by one.
5. Remove excess solder with copper braid.
6. Clean with isopropyl alcohol.
7. Apply flux and solder the replacement component in place.

**Verification:** Inspect all joints under the microscope. No solder bridges between adjacent pins.

### Rework Procedure — QFN and Small Components

For components without accessible pins — such as the 4×33 Ω resistor arrays and the H5VU25U ESD protection devices — hot air rework is required.

### OLED Removal

Apply heat to adhesive before removing OLED from PCB. Hot air gun or hair dryer.

---

## Hardware Tests

Post-assembly verification procedure for a newly assembled board.

### Power Supplies

All power rails must be within specification before firmware installation or target connection.

**Prerequisites:** Board assembled and connected to USB. Multimeter.

Measure each rail at the test pads. The test pads are on the side of the board that has no components.

| Rail | Test Points | Expected Range | Notes |
| ---- | --- | --- | ----- |
| 5V USB | TP (5V), GND | 4.75 – 5.25 V | From USB |
| 3.3V | TP (3.3V), GND | 3.3 V | Main supply |
| 12V OLED | TP (12V), GND | 11.7 – 12.4 V | 12.1 V typical |
| 3.3V SD | TP (VSD), GND | 3.3 V | Active only when SD card is inserted |
| VIO | TP (VIO), GND | 1.1 – 3.6 V | Target voltage or 3.3V from probe |
| ISO 5V | TP (ISO 5V), ISO GND | 4.5 – 5.5 V | Measure relative to ISO GND, not GND |
| ISO GND | GND | open circuit | Measure resistance |

⚠️ **Warning: ISO 5V measurement reference.**
The ISO 5V rail is referenced to isolated CAN GND. Connect the multimeter negative lead to the ISO GND test pad. Measuring with reference to probe GND will give an incorrect reading.

**Verification:** All rails within expected ranges. If any rail is out of range, do not proceed to firmware installation.

### CAN Bus Isolation

**Procedure:**

1. Ensure the board is disconnected from USB with no cables attached.
2. Measure resistance between the GND test pad and the ISO GND test pad.

**Verification:** Open circuit (infinite resistance). Any measurable resistance indicates a solder bridge or contamination across the isolation barrier.

### Console

**Procedure:**

1. Install firmware. See [INSTALL.md](INSTALL.md).
2. Connect a terminal emulator to SWD connector pins 2 (CONSOLE TXD) and 3 (CONSOLE RXD) at 115200 baud, 8N1.
3. Power the board.

Expected boot output with SD card inserted: See [boot log](REFERENCE.md#boot-log)

**Verification:** When typing "Enter", the `msh />` prompt appears. No error messages in the boot log.

### Crystals

Do not measure oscillator frequency by placing an oscilloscope probe directly on the crystal pins — probe capacitance alters the oscillator frequency. Firmware commands route the clock to an output pin for measurement.

**12 MHz crystal (HSE):**

```
msh />clkout_12m
```

A 1 MHz square wave appears on pin PB13 (system clock divided by 12). Measure at the resistor connected to PB13.

**Verification:** Frequency is 1.000 MHz ± tolerance.

**32.768 kHz crystal (LSE):**

```
msh />clkout_32k
```

**Verification:** Frequency is 32.768 kHz ± tolerance.

### Real-Time Clock

**Procedure:**

1. Insert a CR1220 battery.
2. Set the time:

```
msh />ds3231 date 2025 07 14 12 07 00
```

3. Reboot.
4. Verify:

```
msh />date
```

Expected output:

```
local time: Mon Jul 14 12:08:49 2025
timestamps: 1752466129
timezone: UTC+08:00:00
```

**Verification:** Displayed time matches the time set, accounting for elapsed seconds.

### I2C Bus

```
msh />i2c_scan
```

Expected output:

```
    00 01 02 03 04 05 06 07 08 09 0A 0B 0C 0D 0E 0F
00:                         -- -- -- -- -- -- -- --
10: -- -- -- -- -- -- -- -- -- -- -- -- -- -- -- --
20: -- -- -- -- -- -- -- -- -- -- -- -- -- -- -- --
30: -- -- -- -- -- -- -- -- -- -- -- -- -- -- -- --
40: -- -- -- -- -- -- -- -- -- -- -- -- -- -- -- --
50: 50 -- -- -- -- -- -- -- -- -- -- -- -- -- -- --
60: -- -- -- -- -- -- -- -- 68 -- -- -- -- -- -- --
70: -- -- -- -- -- -- -- -- -- -- -- -- -- -- --
```

**Verification:** Address 0x50 (24C64 EEPROM) and 0x68 (SD8931 RTC) present. No other addresses.

To verify I2C3:

```
msh />i2c_scan i2c3
```

**Verification:** Connected device appears at its expected address.

### SPI Flash

⚠️ **Warning: flash benchmark erases all data.**
The `fal bench` command erases the entire 16 MB SPI flash. Run only on a newly assembled board before any data is stored.

```
msh />fal bench 4096 yes
```

Expected output:

```
Erasing 16777216 bytes data, waiting...
Erase benchmark success, total time: 39.097S.
Writing 16777216 bytes data, waiting...
Write benchmark success, total time: 157.395S.
Reading 16777216 bytes data, waiting...
Read benchmark success, total time: 17.782S.
```

**Verification:** All three operations complete without error. Read ~1 MB/s. Write ~0.1 MB/s.

### SD Card

**Procedure:**

1. Insert an SD card, FAT32 or exFAT format.

Expected console output:

```
I/SD: sdcard mount
I/SD: sd card mounted on /sdcard
```

2. Remove the SD card.

Expected console output:

```
I/SD: sdcard unmount
```

**Verification:** Mount and unmount events logged correctly.

### Target Reset

```
msh />trst high
```

Expected output:

```
trst_out high
trst_in low
```

```
msh />trst low
```

Expected output:

```
trst_out low
trst_in high
```

**Verification:** `trst_in` is the inverse of `trst_out` in both states.

### CAN Bus

Without power applied, measure resistance between CAN_HIGH and CAN_LOW.
Resistance between CAN_HIGH and CAN_LOW should be 60 ohms.

With power applied, but without traffic, CAN_HIGH and CAN_LOW should be about the same voltage (2.5V).

With traffic, CAN_HIGH should be above 2.5V (towards 3.5V) while CAN_LOW should be below 2.5V (towards 1.5V).

---

## Drop Test

An enclosure was printed in SLA 8100 hard transparent resin. The OLED was attached with double-sided adhesive tape. The tool was intentionally dropped from a table to a hard tile floor.

Tested: all corners (body diagonal) and display face down.

**Results:** No visible damage. The device remained fully functional throughout. The transparent enclosure was used to inspect for internal damage without disassembly.

When using plain double-sided adhesive tape, the OLED may detach on a face-down impact.

When using 3M VHB (Very High Bond) sticker, 30 mm × 30 mm: No issues.

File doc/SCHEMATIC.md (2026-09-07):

# ARM CAN TOOL — Schematic

<!--
Schematic bitmaps documented in tools/mkepub.sh
-->

Hardware revision v1.0. CC0 Public Domain.

Full hardware project: [oshwlab.com/koendv/arm_can_tool](https://oshwlab.com/koendv/arm_can_tool)

## Processor and Power

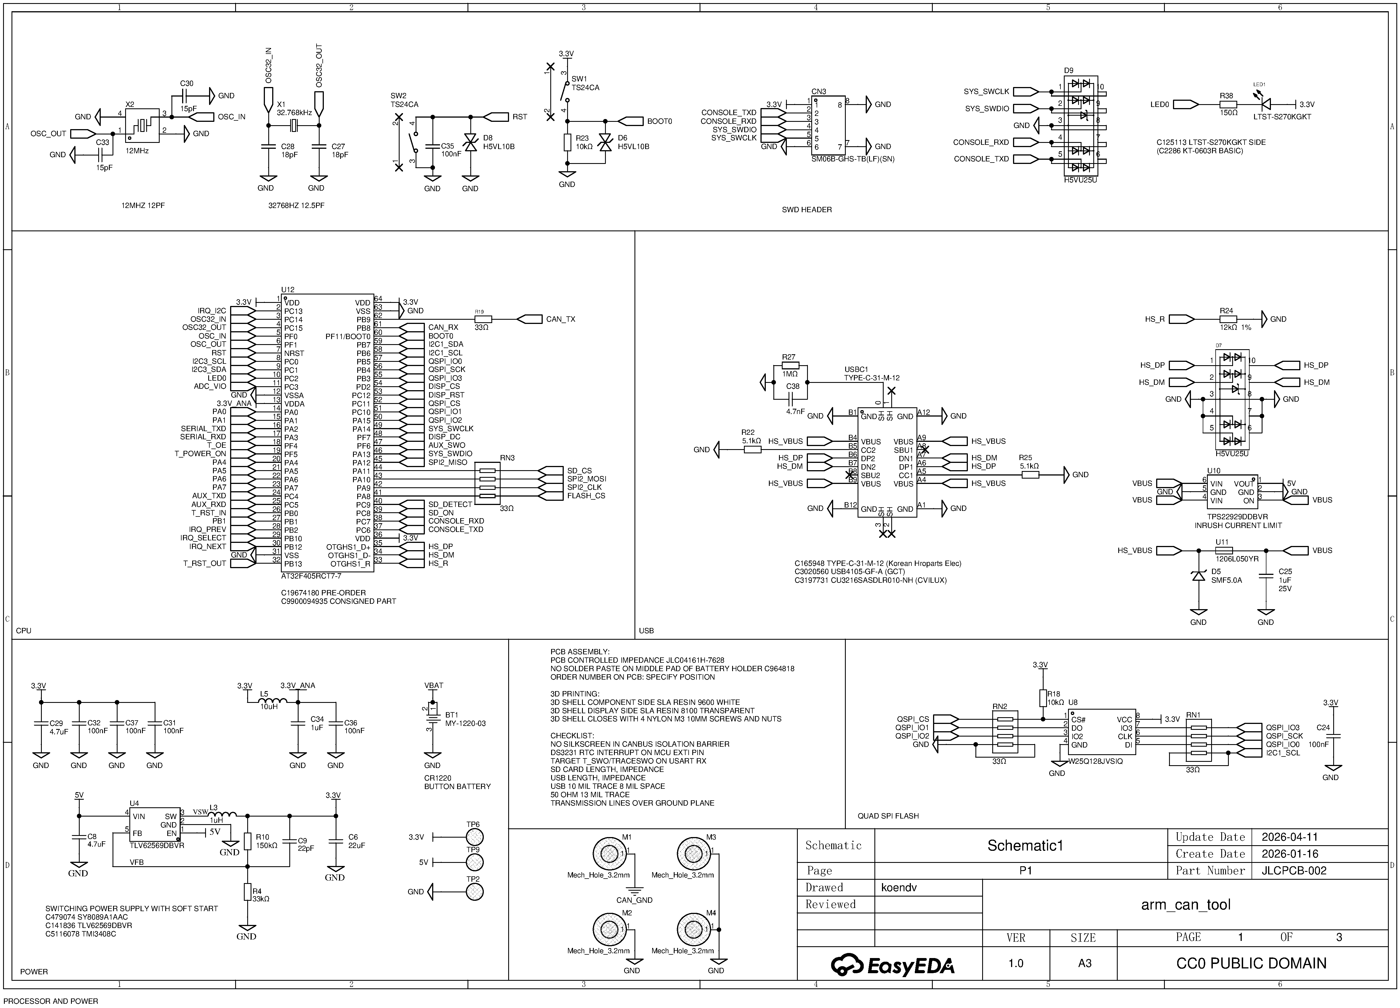
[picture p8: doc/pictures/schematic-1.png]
Processor and Power


## I2C and SPI

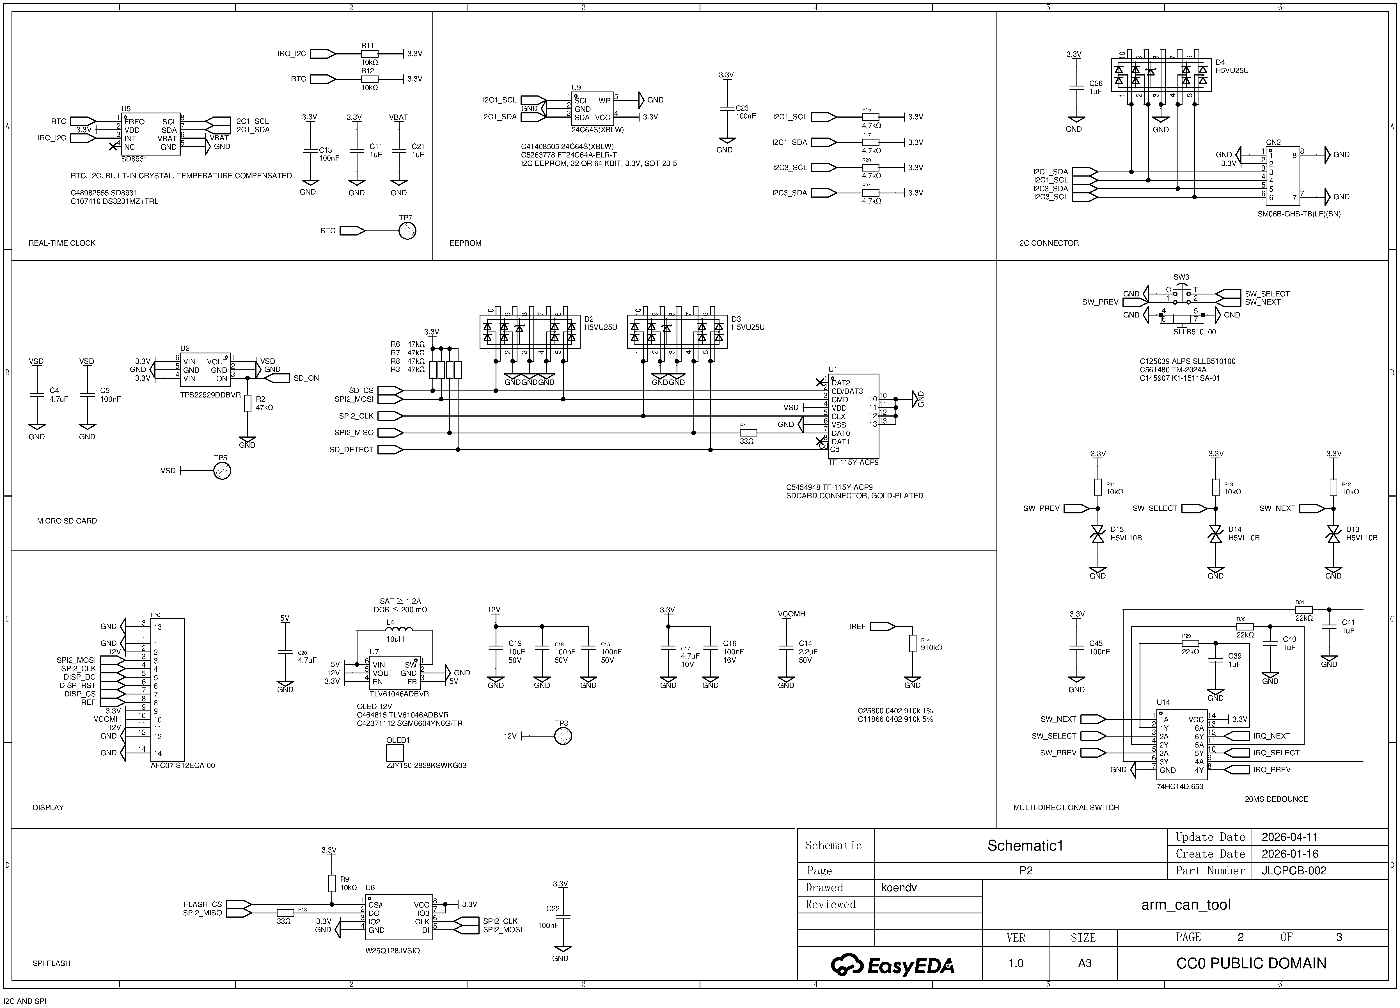
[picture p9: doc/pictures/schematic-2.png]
I2C and SPI


## Target and CAN Bus

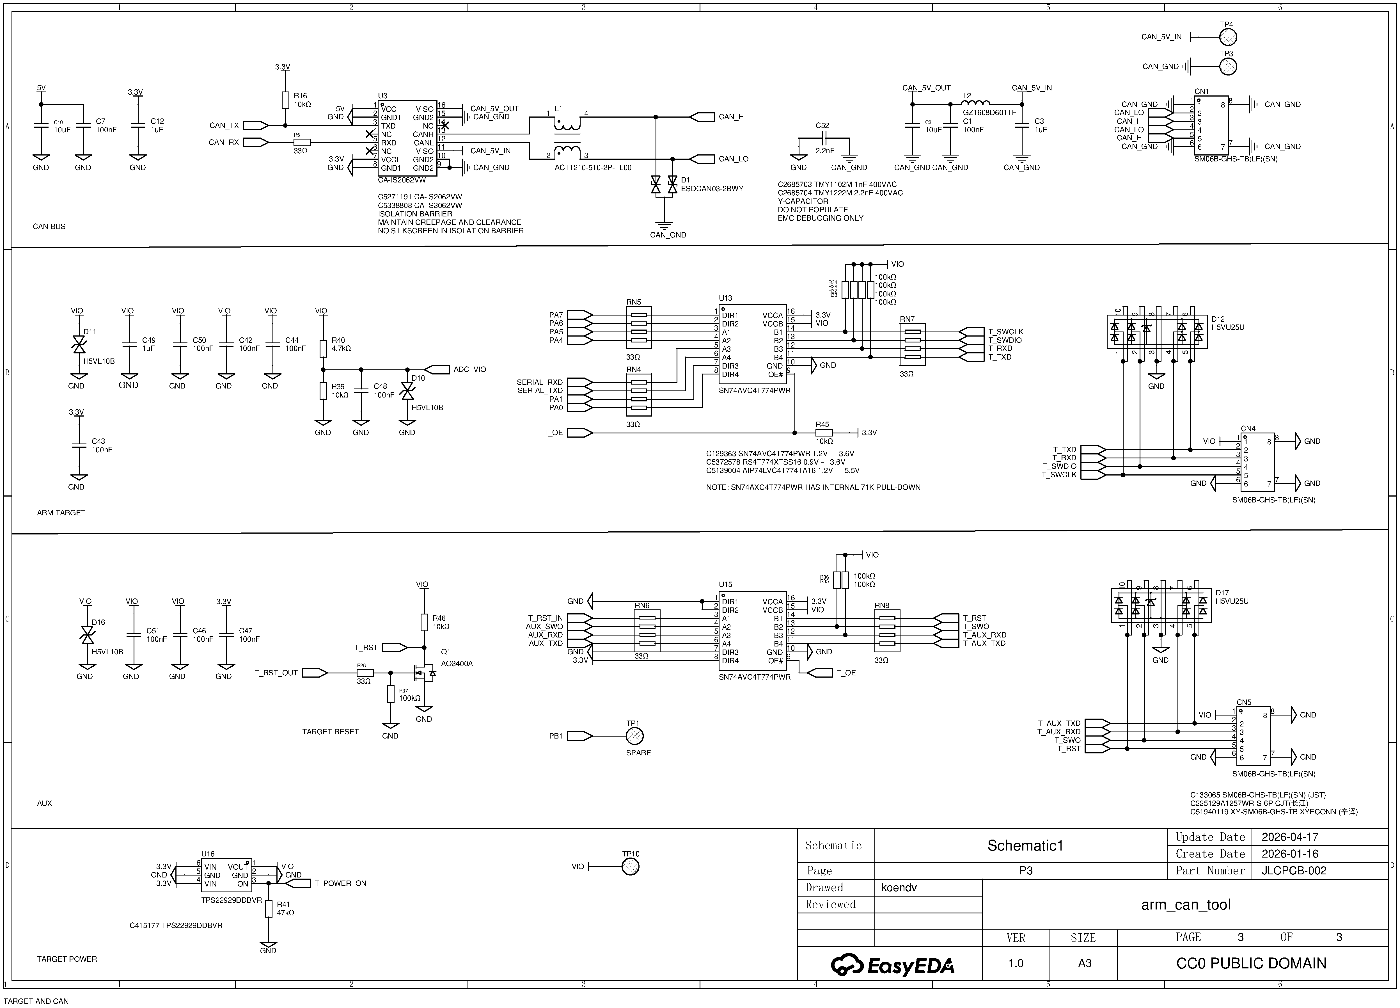
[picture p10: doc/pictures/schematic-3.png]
Target and CAN Bus


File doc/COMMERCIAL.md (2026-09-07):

# ARM CAN TOOL — Commercial Information

**Hardware revision:** v1.0

---

## Product Summary

|English|Chinese|
|---|---|
|English|简体中文|

ARM CAN Tool is a debug probe for ARM and RISC-V embedded systems. Combines SWD/JTAG debugging with electrically isolated CAN 2.0 interface. Targets firmware developers working with STM32 and other embedded processors on CAN bus systems — see [TARGETS](TARGETS.md) for the full list.

- Combines isolated CAN bus monitoring with full debug probe in one device.
- Hardware design is CC0. No IP risk on hardware. No upstream licensor for hardware.
- Ship bootloader preloaded (MIT, permissive). Do not ship firmware preloaded (GPLv3, license obligation).
- Firmware updates via USB mass storage. No tools required. Reduces support burden.
- OLED display with menu. No host software required to configure device.
- Supports unattended remote deployment.
- Manufactured via JLCPCB and standard Chinese supply chain.

---

## Unit Cost

Costs based on orders placed in 2025. Excludes shipping and taxes.

| Item | Qty 2 (USD) | Qty 5 (USD) |
| ---- | --- | --- |
| PCB assembly (board only) | 57.50 | 30.60 |
| Processor (AT32F405) | 1.75 | 1.75 |
| OLED display | 3.50 | 3.50 |
| Enclosure (3D printed) | 4.50 | 4.50 |
| 3M VHB sticker | 0.10 | 0.10 |
| Screws and nuts | 0.10 | 0.10 |
| **Total per unit** | **67.45** | **40.55** |

PCB assembly cost as of 07/2025: USD 115 for 2 units, USD 153 for 5 units. JLCPCB Economy assembly. Excludes shipping and tax.

At quantity 5, unit cost is approximately USD 40 (2025).

---

## Supply Chain

⚠️ **Warning — single-source components:** Processor (AT32F405) and OLED display have single sources. Monitor availability before committing to production run.

See MANUFACTURING for component sourcing details.

---

## License

Hardware design is CC0. Manufacture, modify, and sell without restriction.

Bootloader is MIT, permissive. Preload bootloader.

Firmware includes GPLv3 components. Do not preload firmware - shipping firmware preloaded triggers license obligations. See [LICENSE.md](../LICENSE.md) for details.

---

## Reseller Procedure

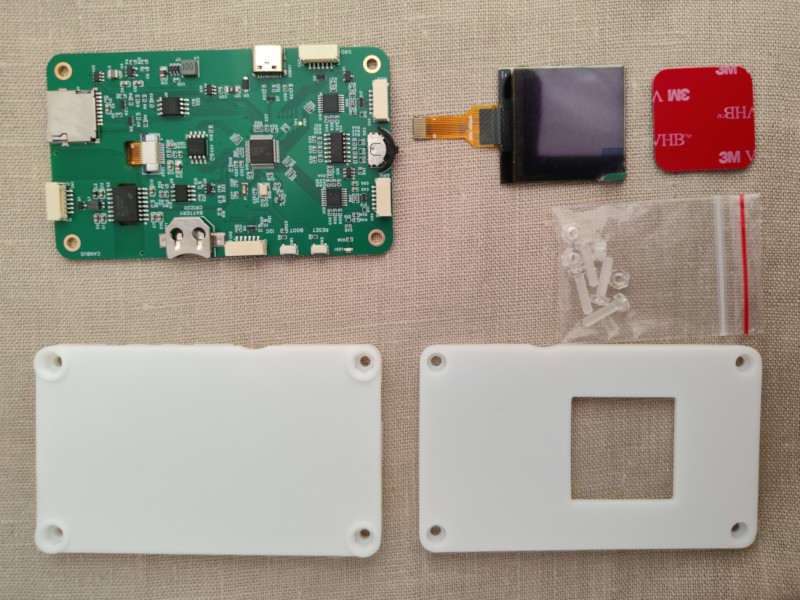
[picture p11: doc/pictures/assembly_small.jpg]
Assembly


1. Order assembled PCBs from JLCPCB.
2. Order OLED displays separately. OLED is not included in PCB assembly order.
3. Order 3D printed enclosures from JLC3DP.
4. Preload bootloader. Doubles as production test - verifies power supply, USB, MCU.
5. Pack PCB, OLED, enclosure, 3M sticker, screws and nuts.
6. Ship.

Verification: All components present in package before shipping.

Buyer assembles device. Customer installs firmware.

---

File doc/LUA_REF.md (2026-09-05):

# ARM CAN TOOL — Lua Library Reference

---

## `bmd` — Black Magic Debug (SWD target control)

> `nil, err` if not attached or on error · `true` on success

### Connection

| Function | Returns | Description |
|---|---|---|
| `bmd.attach()` | `true, err` | SWD scan and attach to first target |
| `bmd.reset()` | `true, err` | Reset the attached target |
| `bmd.target_running()` | `boolean` | True if target is currently executing |

### Halt / Resume

| Function | Returns | Description |
|---|---|---|
| `bmd.halt_request()` | `true, err` | Request target halt |
| `bmd.halt_poll()` | `true, reason, watch` | Poll halt status; `reason`=int, `watch`=addr |
| `bmd.halt_resume()` | `true, err` | Resume target execution |

### Flash

| Function | Returns | Description |
|---|---|---|
| `bmd.flash_mass_erase()` | `true, err` | Erase entire target flash |
| `bmd.flash_erase(addr, len)` | `true, err` | Erase flash region |
| `bmd.flash_write(addr, data)` | `true, err` | Write binary string to flash (erase first) |
| `bmd.flash_complete()` | `true, err` | Flush pending flash write buffers |

### Memory

| Function | Returns | Description |
|---|---|---|
| `bmd.mem32_read(addr, len)` | `data, err` | Read `len` bytes from target RAM |
| `bmd.mem32_write(addr, data)` | `true, err` | Write binary string to target RAM |

### Registers

| Function | Returns | Description |
|---|---|---|
| `bmd.regs_read()` | `blob, err` | Read all registers as binary blob |
| `bmd.regs_write(blob)` | `true, err` | Write all registers from binary blob |
| `bmd.reg_read(reg)` | `bytes, err` | Read single register by index (4 or 8 bytes) |
| `bmd.reg_write(reg, data)` | `true, err` | Write single register by index |

### Breakpoints / Watchpoints

| Function | Returns | Description |
|---|---|---|
| `bmd.breakwatch_set(t, a, l)` | `true, err` | Set breakpoint or watchpoint |
| `bmd.breakwatch_clear(t, a, l)` | `true, err` | Clear breakpoint or watchpoint |

---

## `can` — AT32F405 CAN1 Peripheral

> Errors return `nil` or `nil, err`

### Functions

| Function | Returns | Description |
|---|---|---|
| `can.init(enable)` | `true, err` |Initialise CAN; `true` = bus active, `false` = frozen |
| `can.speed(freq_hz)` | `true, err` | Set CAN bitrate e.g. `500000` |
| `can.transmit(id, data, id_t, frame_t)` | `mailbox (0–2)` or `nil` | Queue frame; `data` ≤ 8 bytes; `nil` = no mailbox |
| `can.receive()` | `id, data, id_t, frame_t, ts` | Pop frame from RX ring; `nil` if empty |
| `can.tx_state()` | `s0, ts0, s1, ts1, s2, ts2` | Status + µs timestamp per TX mailbox |

### Constants

| Constant | Value | Description |
|---|---|---|
| `ID_STD` | `0` | Standard 11-bit ID |
| `ID_EXT` | `1` | Extended 29-bit ID |
| `FRAME_DATA` | `0` | Data frame |
| `FRAME_RTR` | `1` | Remote request frame |
| `TX_MAILBOX0` | `0` | Mailbox 0 |
| `TX_MAILBOX1` | `1` | Mailbox 1 |
| `TX_MAILBOX2` | `2` | Mailbox 2 |
| `TX_FAILED` | `0` | Transmission failed |
| `TX_OK` | `1` | Transmission successful |
| `TX_PENDING` | `2` | Transmission pending |
| `TX_NO_EMPTY` | `4` | No mailbox free |

---

## `flash` — Lua Flash Storage (2 KB sectors, XIP)

> Errors return `nil, err`

### Read / Execute

| Function | Returns | Description |
|---|---|---|
| `flash.exec(sector [, ...])` | `chunk returns, err` | Load + execute bytecode; extra args = varargs |
| `flash.load(sector)` | `function, err` | Load bytecode as function, do not execute |
| `flash.autoexec()` | *(nothing)* | Execute sector 0; errors logged, not raised |

### Write

| Function | Returns | Description |
|---|---|---|
| `flash.write(func, sector [, name])` | `true, byte_size, n_sectors` | Dump + write bytecode; erases sectors first |
| `flash.receive()` | `true` | Begin serial bytecode receive to flash (CDC1) |

### Erase / List

| Function | Returns | Description |
|---|---|---|
| `flash.erase(sector)` | `true, err` | Erase single sector |
| `flash.eraseall()` | `true, err` | Erase entire LFS region |
| `flash.list()` | *(prints to CDC1)* | Print sector index, size, name; free space |

---

## `dap` — CMSIS-DAP Raw HID Layer

| Function | Returns | Description |
|---|---|---|
| `dap.init()` | *(nothing)* | Initialise DAP layer |
| `dap.process_request(req)` | `response string` | `req` must be 64 bytes; returns response bytes |

---

## `sys` — System Utilities (memory · I/O · files · EEPROM · events)

> Errors return `nil, err`

### Memory

| Function | Returns | Description |
|---|---|---|
| `sys.mem_total()` | `bytes` | Total Lua heap size |
| `sys.mem_used()` | `bytes` | Current heap usage |
| `sys.mem_free()` | `bytes` | Free heap bytes |
| `sys.mem_max_used()` | `bytes` | High-water mark since boot |

### I/O

| Function | Returns | Description |
|---|---|---|
| `sys.write(s)` | *(nothing)* | Write string to CDC0 |
| `sys.log(s)` | *(nothing)* | INFO log via RTdbg (debug console) |

### Files (SD Card)

| Function | Returns | Description |
|---|---|---|
| `sys.load(filename)` | `true, err` | Load + exec Lua source or bytecode from SD |
| `sys.dump(func, filename)` | `true, err` | Print bytecode as xxd heredoc |

### EEPROM (24C64)

| Function | Returns | Description |
|---|---|---|
| `sys.eeprom_write(addr, data)` | `bytes_written` | Write binary string to EEPROM |
| `sys.eeprom_read(addr, len)` | `string, err` | Read bytes from EEPROM |

### Serial

| Function | Returns | Description |
|---|---|---|
| `sys.serial0_receive(count)` | `string` | Read up to `count` bytes from serial0 |
| `sys.serial1_receive(count)` | `string` | Read up to `count` bytes from serial1 |
| `sys.serial0_write(s)` | *(nothing)* | Write string to serial0 |
| `sys.serial1_write(s)` | *(nothing)* | Write string to serial1 |

### Timer

Use the timer to avoid busy waiting.

| Function | Returns | Description |
|---|---|---|
| `sys.timer_oneshot(delay_ms)` | `true, err` | Send `EVENT_TIMER` once, after `delay_ms` |
| `sys.timer_periodic(period_ms)` | `true, err` | Send `EVENT_TIMER` every `period_ms` |
| `sys.timer_cancel()` | *(nothing)* | Stop timer |

### Event Constants

| Constant | Description |
|---|---|
| `EVENT_CAN1_TX_DONE` | CAN1 frame transmitted |
| `EVENT_CAN1_RX0_INDIC` | CAN1 frame received |
| `EVENT_CAN1_BUS_OFF` | CAN1 bus-off condition |
| `EVENT_CAN1_RX_OVERFLOW` | CAN1 RX ring overflow |
| `EVENT_CAN1_TX_OVERFLOW` | CAN1 TX overflow |
| `EVENT_GSUSB_BULK_OUT` | GS_USB bulk-out packet |
| `EVENT_GSUSB_STOP` | GS_USB interface stopped |
| `EVENT_GSUSB_START` | GS_USB interface started |
| `EVENT_GSUSB_TX_DONE` | GS_USB frame transmitted |
| `EVENT_CDC0_DTR` | CDC0 DTR line changed |
| `EVENT_CDC1_DTR` | CDC1 DTR line changed |
| `EVENT_CDC0_RX` | CDC0 data received |
| `EVENT_CDC1_RX` | CDC1 data received |
| `EVENT_SERIAL0_RX` | UART0 data received |
| `EVENT_SERIAL1_RX` | UART1 data received |
| `EVENT_SERIAL2_RX` | UART2 data received |
| `EVENT_TARGET_HALT_REQUEST` | Debug target halt requested |
| `EVENT_TARGET_HALTED` | Debug target halted |
| `EVENT_TIMER` | Lua timer expired |

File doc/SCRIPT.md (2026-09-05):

# ARM CAN TOOL — Lua Scripting

> Add a feature once, support forever.

Scripting automates repetitive tasks.

Lua scripting is event-driven and runs from flash.

- *event driven:* When an event occurs, Lua briefly runs the registered event handler, then returns to sleep until the next event. Avoid busy waiting.
- *run from flash:* The Lua bytecode for the event handlers runs from processor internal flash. Store user functions in flash, avoid using ram.
- *runs untethered:* Once stored in flash and autoexec is enabled, event handlers execute with no PC connected.

RAM and CPU are scarce resources - allocate them wisely.

Adding features increases resource usage. For long-lived products, aim for no more than 50% RAM, CPU and flash use at first release.

## Lua Shell

Set Mode -> Lua Script. Reboot.

Connect a terminal emulator to CDC serial 1 (`/dev/ttyBmpLua`). Prompt is `lua>`. CDC serial 0 (`/dev/ttyBmpUser`) is available for script I/O.

The shell is single-line expressions only. Line length maximum 80 characters. Command history is 128 characters. Lua integers and floats are 32-bit.

Object-method syntax is not available. Use `string.upper(s)`, not `s:upper()`.

Implicit string-to-number conversion is disabled. `"10" + 5` produces a runtime error. Use `tonumber()` for explicit conversion.

Tab completion lists the first 8 candidates, globals and first level of table members only.

A line beginning with `=` is shorthand for `return`:

```
lua> =1+1
2
lua> =sys.mem_free()
24840
```

## Lua Libraries

Lua libraries are ro-tables (read only tables) and stored in 16 Mbyte QSPI flash. The ro-tables are limited to c functions and integer constants. Float constants and strings in libraries are zero-argument functions.

| Library | Description |Note|
|---|---|---|
| bmd | Black Magic Debug | target memory, target flash, registers, breakpoints, halt/resume |
| dap | CMSIS-DAP |  |
| can | CAN bus | transmit, receive, speed |
| sys | System functions | memory info, I/O, events |
| flash | Internal flash | store and execute user functions |
| base | Standard Lua library | `_VERSION()` is a zero-argument function |
| coroutine | Standard Lua library | |
| math | Standard Lua library | Float constants are zero-argument functions. (`math.pi()`, `math.huge()`, etc.)  |
| string | Standard Lua library | |
| table | Standard Lua library | |
| utf8 | Standard Lua library | `utf8.charpattern()` is a zero-argument function. |

What is not used does not get fixed.

## Lua System Library

| Function | Description |
|---|---|
| `sys.mem_total()` | Returns total heap memory size in bytes. |
| `sys.mem_used()` | Returns currently used heap memory in bytes. |
| `sys.mem_free()` | Returns free heap memory in bytes. |
| `sys.mem_max_used()` | Returns peak (maximum) heap memory used in bytes. |
| `sys.write(string)` | Write a string to usb serial port. |
| `sys.log(string)` | Log a message to the system logger. |
| `sys.load(filename)` | Load and execute Lua bytecode or source from SD card file. Returns true on success or (nil, error_string) on failure. |
| `sys.dump(func, filename)` | Compile function to bytecode and output as hex dump to serial terminal. Output can be piped to `xxd -r` to recreate the binary. Returns true or (nil, error_string). |
| `sys.eeprom_write(address, string)` | Write data to settings EEPROM at specified address. Returns bytes written or (nil, error_string) on failure. |
| `sys.eeprom_read(address, length)` | Read data from settings EEPROM at specified address and length. Returns string or (nil, error_string) on failure. |
| `sys.serial0_receive(count)` | Read up to `count` bytes from serial0; returns empty string if no data available. |
| `sys.serial1_receive(count)` | Read up to `count` bytes from serial1 |
| `sys.serial0_write(string)` | Write a string to serial0 |
| `sys.serial1_write(string)` | Write a string to serial1 |
| `sys.timer_oneshot(delay_ms)` | Send `sys.EVENT_TIMER` once, after `delay_ms`. Returns true or (nil, error_string). |
| `sys.timer_periodic(period_ms)` | Send `sys.EVENT_TIMER` every `period_ms`. Returns true or (nil, error_string). |
| `sys.timer_cancel()` | Stop the timer. |

**Event Constants**: The library also defines event flag constants (e.g., `sys.EVENT_CAN1_TX_DONE`, `sys.EVENT_CDC1_RX`, `sys.EVENT_TARGET_HALTED`) used with event handlers. See [events](LUA_REF.md#event-constants).

The difference between `print()` and `sys.write()` is that `print()` writes to the Lua console `/dev/ttyBmpLua`. `sys.write()` writes to the user serial `/dev/ttyBmpUser`, and from there to SD card if logging is set.

## Lua Flash Store

Lua compiles user functions to bytecode. Bytecode is stored in ram or flash.

The AT32F405 has 256 kbyte internal flash. The upper 128 kbyte of internal flash is used to store Lua user functions, in 64 sectors of 2 kbyte each. Sector 0 is the autoexec function. A function whose bytecode exceeds 2 kB occupies consecutive sectors automatically. The user is responsible for sector allocation. Leave a gap of one or more sectors between functions to allow for growth.

## Lua Flash Library

| Function | Description |
|---|---|
| `flash.exec(sector [, args...])` | Load and execute bytecode from flash sector. Extra arguments are passed to bytecode as varargs (`...`). Returns execution results. |
| `flash.load(sector)` | Load bytecode from sector and return the chunk as a callable Lua function, without executing it. Calling the returned chunk runs the stored code's top level — which may itself return a function, depending on how the script was written. Uses XIP mode to keep instructions in flash. |
| `flash.autoexec()` | Internal function that loads and executes bytecode from sector 0 automatically. Logs success or error to system console. |
| `flash.write(func, sector [, name])` | Write a Lua function's compiled bytecode to flash at specified sector. Returns success flag, bytecode size (bytes), and number of sectors used. |
| `flash.erase(sector)` | Erase a single flash sector. Returns success flag. |
| `flash.eraseall()` | Erase all LFS sectors. Returns success flag. |
| `flash.list()` | Display all LFS sectors, their sizes, function names, and free space. |
| `flash.receive()` | Receive bytecode from serial port and write to flash. |

The difference between `flash.exec(0)` and `flash.autoexec()` is that `autoexec()` logs errors to the system console, `exec()` logs errors to usb serial. Lua autoexec may occur before usb startup.

The difference between `sys.load()` and `flash.load()` is that `sys.load()` loads source from file; `flash.load()` loads bytecode from flash.

## Compiling User Functions

Clear all stored functions:

```
lua> flash.eraseall()
lua> flash.list()
64/64 free
```

Compile a user function at the lua prompt:

```
lua> function hello() print("hello, world!") end
lua> hello()
hello, world!
```

Display the bytecode:

```
lua> sys.dump(hello, "hello")
xxd -r << 'EOF' > hello
00000000: 1b4c 7561 5500 1993 0d0a 1a0a 0488 a9ff  .LuaU...........
(output truncated)
EOF
```

Store the function in processor flash:

```
lua> flash.write(hello, 1, "hello")
lua> flash.list()
0x01     92  hello
63/64 free
```

Execute the function from flash:

```
lua> flash.exec(1)
hello, world!
```

**Verification:** Turn arm can tool off and on. `flash.exec(1)` prints "hello, world!".

## Compiling from File

Change arm can tool mode to "Mass Storage". In the usb filesystem, create the following file:

```
$ more mem.lua
function show_memory()
    print("ram: " .. tostring(sys.mem_used()) .. "/" .. tostring(sys.mem_total()) .. " bytes")
end
```

Carefully eject the usb file system.

Change arm can tool mode back to "Lua Script". At the lua prompt, type:

```
lua> sys.load("/sdcard/mem.lua")
lua> show_memory()
ram: 17688/32768 bytes
lua> flash.write(show_memory, 2, "show_memory")
lua> flash.list()
0x01     92  hello
0x02    189  show_memory
62/64 free
lua> flash.exec(2)
ram: 14120/32768 bytes
```

## Cross-Compiling

Go to `arm_can_tool/tools/lua32`.

On the PC, create a file:

```
$ more hello.lua
print("hello, world!")
```

Write executable statements at the top level of the file, not wrapped in `function ... end`.
`flash.exec(sector)` and `flash.load(sector)()` load the bytecode as a chunk and call the chunk once; only the chunk's top-level statements run on that call.

A file written as `function hello() ... end` or `return function() ... end` just builds a closure and hands it back without running it.
`flash.exec()` then silently discards that returned function, producing no output and no error.

Compile:

```
$ luac32 -s -o hello.luac hello.lua
```
`luac32` is luac, same lua version as embedded, compiled with LUA_32BITS.

At the lua prompt, type:

```
lua> flash.receive()
Waiting for data
```

Close the terminal.

On the PC, type:

```
$ lfs_send.py -p /dev/ttyBmpLua -s 3 hello.luac
  hello.luac: 96 bytes, 1 sector(s), base sector 3, name 'hello'
Sending 1 sector(s) via /dev/ttyBmpLua
  sector   3 [last] 2058 framed bytes ... ACK
Transfer complete.
```

**Consequence of not closing the terminal**: the ACK is sent to the terminal, and not to `lfs_send.py`. Transfer does not complete.

Open the lua console `/dev/ttyBmpLua` again. At the lua prompt, type:

```
lua> flash.list()
0x01     92  hello
0x02    195  show_memory
0x03     96  hello
61/64 free
lua> flash.exec(3)
hello, world!
```

⚠️ **Warning — 32-bit bytecode required.** 64-bit `luac` produces incompatible bytecode. Error message when using 64-bit `luac`: `luac: bad binary format (version mismatch)`

### Cross-Compiling a Function with Arguments

`flash.exec(sector, args...)` passes any arguments after the sector number into the chunk as varargs (...). Example: function to add two numbers.

On PC:

```
$ more add.lua
local a, b = ...
print(a + b)
$ luac32 -s -o add.luac add.lua
```

On arm can tool:

```
lua> flash.receive()
Waiting for data
```
Exit terminal.
On PC:

```
$ lfs_send.py -p /dev/ttyBmpLua -s 4 add.luac
```

On arm can tool:

```
lua> flash.list()
0x01     92  hello
0x02    195  show_memory
0x03     96  hello
0x04     88  add
60/64 free
lua> flash.exec(4, 2, 3)
5
```

### Trading RAM For CPU

`flash.exec(sector)` and `flash.load(sector)` re-parse the chunk's bytecode on every call, allocating a fresh `Proto`, constants, and closure in RAM. RAM usage spikes during the call and is freed by garbage collection afterward. Default for infrequently-called handlers — no RAM held between calls.

For a frequently-called handler, the repeated parse-and-allocate is the dominant cost. Load the chunk once, keep a reference to the resulting function, and call the function directly on later calls:

On PC:

```
$ more add2.lua
return function(a, b)
    return a + b
end
$ luac32 -s -o add2.luac add2.lua
```

On arm can tool:

```
lua> flash.receive()
Waiting for data
```

On PC:

```
$ lfs_send.py -p /dev/ttyBmpLua -s 5 add2.luac
```

Calling the chunk once returns the inner function:

```
lua> add2=flash.exec(5)
lua> =add2(1, 1)
2
lua> =add2(2, 3)
5
```

CPU cost per call is lower. RAM usage is higher — the function is held in RAM between calls.

## Lua Events

Lua reacts to hardware or serial activity autonomously, using event handlers.
An event handler is a Lua function that is executed when an event occurs.
Examples of events are:

- CAN bus frame received
- CAN bus off
- target program halts

Lua wakes up when an event occurs. The corresponding event handler is executed. Then Lua goes back to sleep.
There is no polling loop to write.

### Registering Event Handlers

Event handlers are registered once, at boot, from flash sector 0, by defining a global table named `event_handler`.

Pattern: `event_handler[sys.EVENT_X] = flash.load(N)`

The index of `event_handler` is an integer constant in the `sys` library (`sys.EVENT_CAN1_RX0_INDIC`, `sys.EVENT_CDC1_RX`, etc.)
The value of `event_handler` is a function taking no arguments and returning nothing.

To use event handlers:

- Store a script in flash sector 0 that sets `event_handler` table.
- Set Startup menu → lua autoexec → on
- Store settings: Settings → Store.
- Reset arm can tool.

**Registering event handlers only happens once, at boot, from sector 0.**

Setting or changing `event_handler` from the interactive shell after boot does not change event handlers.

An event handler stored in flash is written the same way as any other cross-compiled script: statements at the top level, not wrapped in `function ... end`.

### Demo: CAN Bus Logging

Three pieces:

- an event handler that prints received CAN frames
- an event handler that reports a bus-off condition.
- autoexec script that registers the two event handlers, and a function to switch logging on and off.

**Sector 0 — autoexec.**

On PC:

```
$ more autoexec.lua
can_logging = true

function toggle()
    can_logging = not can_logging
    print(can_logging and "on" or "off")
end

event_handler = {}
event_handler[sys.EVENT_CAN1_RX0_INDIC] = flash.load(1)
event_handler[sys.EVENT_CAN1_BUS_OFF]   = flash.load(2)
```

```
$ luac32 -s -o autoexec.luac autoexec.lua
```

**Sector 1 — CAN frame handler.**

Runs on `EVENT_CAN1_RX0_INDIC`.
Drains the receive ring buffer unconditionally, even when logging is off.

On PC:

```
$ more can_log.lua
while true do
    local id, data, id_type, frame_type, ts = can.receive()
    if not id then break end
    if can_logging then
        local hex = string.format(string.rep("%02X ", #data), string.byte(data, 1, #data))
        sys.write(string.format("CAN %s id=0x%X dlc=%d frame=%s ts=%d\r\n",
            id_type == can.ID_EXT and "ext" or "std", id, #data, hex, ts))
    end
end
```

```
$ luac32 -s -o can_log.luac can_log.lua
```

**Sector 2 — bus-off handler.**

Runs on `EVENT_CAN1_BUS_OFF`.

On PC:

```
$ more can_busoff.lua
sys.write("CAN1 bus off\r\n")
```

```
$ luac32 -s -o can_busoff.luac can_busoff.lua
```

On arm can tool:

```
lua> flash.eraseall()
lua> flash.receive()
Waiting for data
```

On PC:

```
$  ./lfs_send.py -p /dev/ttyBmpLua -s 0 autoexec.luac -s 1 can_log.luac -s 2 can_busoff.luac
  autoexec.luac: 348 bytes, 1 sector(s), base sector 0, name 'autoexec'
  can_log.luac: 279 bytes, 1 sector(s), base sector 1, name 'can_log'
  can_busoff.luac: 95 bytes, 1 sector(s), base sector 2, name 'can_busoff'
Sending 3 sector(s) via /dev/ttyBmpLua
  sector   0 [cont] 2058 framed bytes ... ACK
  sector   1 [cont] 2058 framed bytes ... ACK
  sector   2 [last] 2058 framed bytes ... ACK
Transfer complete.
```

Note sending multiple sectors in one command.

On arm can tool:

```
lua> flash.list()
0x00    348  autoexec
0x01    381  can_log
0x02    107  can_busoff
61/64 free
```

Enable `lua autoexec`:

- Startup → CAN bus
- Startup → lua autoexec
- Settings → Store
- reboot

Console boot log:

```
I/LUA: heap 32 kbyte
I/LUA: autoexec
I/LUA: 2 event handlers
```

Connect to user terminal /dev/ttyBmpUser.

CAN traffic on the bus prints one line per frame.

```
CAN std id=0x0 dlc=4 frame=12 34 56 78  ts=17492945
CAN std id=0x0 dlc=4 frame=12 34 56 78  ts=15137684
```

Connect to lua console /dev/ttyBmpLua.

Switch logging on/off:

```
lua> toggle()
off
lua> toggle()
on
```

---

### Demo: Heartbeat

The demo consists of two pieces:

- an autoexec script that starts a one-second periodic timer
- an event handler that prints a line when the timer fires

On PC:

```
$ more autoexec.lua heartbeat.lua
::::::::::::::
autoexec.lua
::::::::::::::
event_handler = {}
event_handler[sys.EVENT_TIMER] = flash.load(1)

heartbeat_count = 0
sys.timer_periodic(1000)

::::::::::::::
heartbeat.lua
::::::::::::::
heartbeat_count = heartbeat_count + 1
sys.write(string.format("heartbeat %d\r\n", heartbeat_count))
$ luac32 -s -o autoexec.luac autoexec.lua
$ luac32 -s -o heartbeat.luac heartbeat.lua
```

On arm can tool:

- Mode -> Lua Script -> OK
- Connect to /dev/ttyBmpLua:

```
lua> flash.eraseall()
lua> flash.receive()
Waiting for data
```

Disconnect from /dev/ttyBmpLua.
On PC:

```
$ lfs_send.py -p /dev/ttyBmpLua -s 0 autoexec.luac -s 1 heartbeat.luac
  autoexec.luac: 212 bytes, 1 sector(s), base sector 0, name 'autoexec'
  heartbeat.luac: 175 bytes, 1 sector(s), base sector 1, name 'heartbeat'
Sending 2 sector(s) via /dev/ttyBmpLua
  sector   0 [cont] 2058 framed bytes ... ACK
  sector   1 [last] 2059 framed bytes ... ACK
Transfer complete.
```

- Connect to /dev/ttyBmpLua:

```
lua> flash.list()
0x00    212  autoexec
0x01    175  heartbeat
62/64 free
```

On arm can tool:

- Startup → lua autoexec
- Settings → Store
- reboot

Connect to /dev/ttyBmpUser:

```
heartbeat 1
heartbeat 2
heartbeat 3
heartbeat 4
heartbeat 5
...
```
**Verification:** prints one line per second.

Connect to /dev/ttyBmpLua:

```
lua> sys.timer_periodic(2000)
```

**Verification:** prints one line per two seconds. The timer is reconfigured, the event handler is unchanged.

```
lua> sys.timer_cancel()
```

**Verification:** heartbeat lines stop.

## Standalone Logging

Once logging is enabled and settings stored, the tool continues logging with
no PC attached. ARM CAN Tool needs only power, not a live usb connection.

- Startup → logging → on
- Settings → Store
- Disconnect USB from PC; connect USB to a USB charger
- Logging continues, writing to the SD card

**Verification:** Reconnect to a PC after 5 minutes unattached. Set Mode -> Mass Storage. `xxxxxxxx.log` contains CAN bus log.

---

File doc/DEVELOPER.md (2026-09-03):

# ARM CAN TOOL — Developer Guide

> Correctness takes precedence over architectural purity.



## Prerequisites

**Knowledge:**

- Embedded systems firmware development
- ARM Cortex-M architecture
- rt-thread or equivalent RTOS
- Linux command line

**Tools:**

- Docker
- Git

---

## Building from Source

[`tools/docker/Dockerfile`](../tools/docker/Dockerfile) is the single source of truth for building from source. The Dockerfile states toolchain, rt-thread and rt-thread package versions.

Github actions runs the same Dockerfile in CI.

On a host that matches the linux used in the Dockerfile, the commands can be run directly instead of inside a container. In order, the Dockerfile:

- installs the linux packages listed in the `tools` stage, plus the `arm-none-eabi-gcc` xpack toolchain
- clones `RT-Thread/env` and `RT-Thread/packages`
- clones `RT-Thread/rt-thread` and sets `RTT_ROOT` to it
- places the arm can tool repo at `$RTT_ROOT/bsp/at32/arm_can_tool`
- patches rt-thread using `./tools/install_pkgs.sh`
- compiles firmware to uf2 using `scons`
- builds the uf2 bootloader from [koendv/at32f405-uf2boot](https://github.com/koendv/at32f405-uf2boot)

To build:

```bash
docker build --target build -t arm_can_tool -f tools/docker/Dockerfile .
id=$(docker create arm_can_tool)
docker cp "$id":/output ./arm_can_tool_firmware
docker rm "$id"
```

In `./arm_can_tool_firmware/`:

- `cherryuf2_arm_can_tool.bin`, `cherryuf2_arm_can_tool.elf`: bootloader
- `rtthread.uf2`, `rtthread.elf`: firmware
- `arm_can_tool.epub`: manual
- `MANIFEST.txt` — URL and commit of every git repository used in the build

If, after modifying a menu, an UTF8 character does not display, run:
```
./tools/update_unifont.sh
```
and recompile. `update_unifont.sh` ensures the font contains all characters used.

**Verification:** all characters display correctly.

### Flashing

UF2 bootloader button sequence

**Manual:** Enter UF2 bootloader mode (hold multi-direction switch and press [RESET]), then copy:

```bash
cp rtthread.uf2 /media/$USER/CherryUF2/CURRENT.UF2
```

**Automated:** With the board already in UF2 bootloader mode:

```bash
scons --flash
```

Expected output:

```
flash_action(["flash"], ["rtthread.uf2"])
Flashed rtthread.uf2 -> /media/koen/CherryUF2/CURRENT.UF2
scons: done building targets.
```

`scons --flash` compiles if needed, then copies `rtthread.uf2` to the `CherryUF2` mount point. The board must be in UF2 bootloader mode before running this command.

---

## devcontainer

An alternative to a native Linux install: build once, then bind-mount the source tree into the container for every edit-compile cycle. Runs as a non-root user matching the host UID/GID, so files created in the mounted tree stay owned by the host user.

### docker build

Once:

```bash
docker build --target build -t arm_can_tool-tools \
  --build-arg USER_UID=$(id -u) --build-arg USER_GID=$(id -g) \
  -f tools/docker/Dockerfile .
```

### docker run

For every session:

```bash
docker run -it --rm \
  -v ~/src/rt-thread:/work/rt-thread \
  -e RTT_ROOT=/work/rt-thread \
  -w /work/rt-thread/bsp/at32/arm_can_tool \
  arm_can_tool-tools bash
```

Then `scons` inside. No `docker cp` needed, build output is in the mounted source tree on the host. `exit` to end the session; the container is removed (`--rm`), the host tree is untouched.

---

## Firmware Installation

For complete firmware installation and recovery procedures, see [INSTALL](INSTALL.md).

### Bootloader Console Output

The bootloader prints one of two messages on the console (115200 baud) at boot.

| Output | Meaning |
| --- | --- |
| `app` | Multi-direction switch not pressed. Bootloader starts the application. |
| `dfu` | Multi-direction switch pressed. Bootloader waits for a UF2 file. |

### RAM Size

The AT32F405 has 102 kB RAM when the RAM parity check option bit is disabled (factory default). If RAM parity check is enabled, available RAM is 96 kB. The firmware is compiled for 102 kB. If the bootloader prints `96k ram`, reset the processor option bits to restore factory defaults.

### Recovery — Mass Erase

If internal flash is corrupted, reinstall the bootloader with a full mass erase:

```bash
sudo dfu-util -a 0 -d 2e3c:df11 \
              --dfuse-address 0x08000000::mass-erase:force \
              -D cherryuf2_arm_can_tool.bin
```

---

## Software Architecture

> Build one layer on top of existing, known-good software. Focus on improvements and useful new features.

Software block diagram

*Software block diagram.*

The firmware integrates two independent debug probe implementations alongside CAN bus, UI, logging, and scripting subsystems, all running under rt-thread.

### Debug Interfaces

| Component | Role | Host connection |
| --- | ---- | --- |
| [Black Magic Debug](https://github.com/blackmagic-debug/blackmagic) | GDB server | GDB connects directly |
| [free-dap](https://github.com/ataradov/free-dap) | CMSIS-DAP v2 | GDB connects via OpenOCD, pyOCD, or probe-rs |

The two debug interfaces are mutually exclusive at runtime. Mode selection determines which is active.

### Software Components

| Component | Role |
| --- | ---- |
| [rt-thread](https://github.com/RT-Thread/rt-thread) | Real-time operating system |
| [Black Magic Debug](https://github.com/blackmagic-debug/blackmagic) | GDB server |
| [free-dap](https://github.com/ataradov/free-dap) | CMSIS-DAP implementation |
| [CherryUSB](https://github.com/cherry-embedded/CherryUSB) | USB protocol stack |
| [u8g2](https://github.com/olikraus/u8g2) / [MUI](https://github.com/olikraus/u8g2/wiki/muimanual) | Display graphics and menu system |
| [Lua 5.5](https://github.com/lua/lua) | Scripting language |

### Code Formatting

Code in the `applications` directory and its subdirectories is formatted with `clang-format -i`. Code outside `applications` is from third-party projects — leave as is.

### AT32 Workbench

[AT32 Workbench](https://arterytek.com/en/support/tools.jsp) is a graphical tool from Artery (雅特力) for configuring clocks, pins, and peripherals and generating hardware initialisation source code.

The ARM CAN Tool hardware configuration is saved in `arm_can_tool_WorkBench.ATWP`.

**Procedure:**

1. Launch AT32 Workbench.
2. Select `Project → Open Project`.
3. Navigate to `AT32_Work_Bench/` and select `arm_can_tool_WorkBench.ATWP`.
4. Click `Open`.

Verification: The Workbench window displays the AT32F405 pinout with peripheral assignments and a clock tree showing 216 MHz.

Selecting `Project → Generate Code` produces initialisation code in `AT32_Work_Bench/project/`:

- `at32f402_405_int.c` — interrupt vector table
- `at32f402_405_wk_config.c` — clock configuration
- `wk_*.c` — peripheral initialisation

These generated files are integrated into the BSP at `arm_can_tool/board/src/`.

### USB Stack

[CherryUSB](https://github.com/cherry-embedded/CherryUSB) manages the USB endpoints. The USB configuration is mode-dependent and is reconfigured at each boot.

The DWC2-AT USB controller uses a static FIFO configuration. CDC0 and CDC1 have asymmetric TX FIFO allocations reflecting their different traffic patterns.

| Endpoint | TX FIFO | Assignment | Rationale |
| --- | --- | --- | --- |
| EP0 | 64 bytes | Control | Standard control endpoint |
| EP1 | 512 bytes | GS-USB IN, MSC IN | Bulk transfer |
| EP2 | 1024 bytes | CDC0 IN (log output) | Continuous streaming: RTT, SWO, serial console, memwatch |
| EP3 | 512 bytes | CDC1 IN (GDB / CMSIS-DAP) | Response traffic only. Firmware download travels USB OUT through shared RX FIFO. |
| RX (shared) | 1024 bytes | All OUT endpoints | Shared receive FIFO |

CDC0 TX FIFO size is twice CDC1 TX FIFO size, for CDC0 to absorb bursts of continuous log output without stalling.

Within the application, CDC0 and CDC1 are treated differently:

- CDC1 feeds characters from PC to the gdb server. CDC1 is a rt-thread character device.
- CDC0 writes logs and target output to PC. CDC0 is double-buffered for throughput.

### Event-Driven Design

The firmware is designed around one rule: threads must not busy-wait. When a thread has nothing to do, it must sleep. The system LED enforces this discipline — a continuously lit LED indicates a thread is busy-waiting.

All modes have a thread that blocks on `rt_event_recv()` and wakes only when an event occurs or a timeout expires.

Three justified exceptions exist.

**Exception 1 — Target state polling.** SWD provides no interrupt from target to probe. The GDB server polls the target over SWD to detect breakpoints, traps, and faults. This is implemented as a timeout on `rt_event_recv()` rather than a busy loop. The polling interval is configurable via **Target → polling ms**.

**Exception 2 — Target flash write sequences.** Flash write drivers poll target registers and insert delays. These sequences are processor-family-specific, inherited from upstream Black Magic Debug, and have not been rewritten to be event-driven. Correctness takes precedence over architectural purity.

**Exception 3 — SWO buffer flush.** SWO interrupts when the uart buffer is half full or full. When the gdb server polls the target, the gdb server also checks for undecoded SWO data. The idle-timeout check avoids data, smaller than half the dma buffer, staying undecoded e.g. when the target halts.

Outside these three exceptions, the firmware contains no polling loops.

### UI

[u8g2](https://github.com/olikraus/u8g2/wiki) provides the graphics layer. [MUI](https://github.com/olikraus/u8g2/wiki/muimanual) provides the menu system. The display is updated only when content changes. The multi-direction switch is debounced in hardware and software and generates one interrupt per press — no polling required.

---

## GPIO and Bit-Banging

GPIO bit-banging uses:

- direct GPIO register access
- all SWD/JTAG pins updated in one write
- firmware executing from zero-wait-state RAM
- interrupts disabled

### Zero-Wait-State RAM Execution

The hot SWD and JTAG bit-banging routines are copied to RAM at boot and executed from RAM. Execution from RAM has no wait states.

From [boot log](REFERENCE.md#boot-log):

```
I/SWD: ramfunc 3700 byte
```

### Port A Pin Assignment

| Pin | JTAG function | JTAG dir | SWD function | SWD dir |
| --- | --- | --- | --- | --- |
| PA0 | TDI_DIR | OUT | TXD_DIR | OUT |
| PA1 | TDO_DIR | OUT | RXD_DIR | OUT |
| PA2 | TDI | OUT | TXD | OUT |
| PA3 | TDO | IN | RXD | IN |
| PA4 | TMS | OUT | SWDIO | IN/OUT |
| PA5 | TCK | OUT | SWCLK | OUT |
| PA6 | TMS_DIR | OUT | SWDIO_DIR | OUT |
| PA7 | TCK_DIR | OUT | SWCLK_DIR | OUT |

One GPIO register write updates all 8 pins.

---

## Flash Write Performance

Both debug interfaces run on the same hardware with the same GPIO optimisations, allowing direct performance comparison. Measurements use MicroPython firmware as the test payload (large binary, widely available). Programming time includes erase and write phases. Speed as reported by `arm-none-eabi-gdb`. Speed set using `mon freq 10000000` / `mon adapter speed 10000`.

**STM32F412:**

| kB/s | SWD | JTAG |
| ---- | --- | ---- |
| Black Magic Debug | 16 | 15 |
| OpenOCD / free-dap | 16 | 10 |

These speeds are target-family dependent. The Black Magic Debug GDB server was originally designed for USB Full Speed (12 Mbit/s) on a 72 MHz processor. On USB High Speed (480 Mbit/s), the character-at-a-time USB polling model (`gdb_if_getchar()`) is a bottleneck. The arm_can_tool firmware has been rewritten to use an event-driven model based on `rt_event_recv()`, which reduces CPU load significantly. Further optimisation opportunities remain.

### UF2 Bootloader Write Speed

The UF2 bootloader programs the application firmware into QSPI flash at over 65 kB/s. No further optimisation planned.

---

## Speed Test

> What gets measured gets managed

The `speedtest` command measures SWD/JTAG throughput. `speedtest` backs up target RAM, times repeated writes of a test pattern, verifies the write, then restores the original contents.

```
(gdb) monitor speedtest
16 times writing 1024 bytes to 0x20000000
16384 bytes in 228 ms = 70.17 kB/s
```

### Command Syntax

```
(gdb) mon speedtest [COUNT [SIZE [ADDRESS]]]
```

| Argument | Description |
|---|---|
| COUNT | Number of writes. Default: 16 |
| SIZE | Bytes per write, up to 4096. Default: 1024 |
| ADDRESS | Target RAM address. Default: target RAM start |

Example, non-default size:

```
(gdb) monitor speedtest 16 1023
16 times writing 1023 bytes to 0x20000000
16368 bytes in 896 ms = 17.83 kB/s
```

If the test takes too long, gdb complains the debugger is unresponsive. This can be ignored; the test continues.

```
(gdb) monitor speedtest 512 1024
512 times writing 1024 bytes to 0x20000000
Ignoring packet error, continuing...
524288 bytes in 7323 ms = 69.91 kB/s
```

The measured speed may differ from the speed reported by GDB.

```
(gdb) load
...
Transfer rate: 13 KB/sec, 962 bytes/write.
(gdb)
```

For target RAM, the dominant factor is the time needed to transfer the data over the debug interface. For target flash, the dominant factor is the time needed to erase and program the flash.

---

## Single Wire Output

SWO uses AT32 HAL.
uart7 writes to a circular RX buffer (SWO_DMA_BUFSIZE, 2k), interrupts when half full or full.
SWO then does zero-copy decoding directly from the DMA buffer.
SWO uart idle interrupts easily flood the system and are not configured.
To avoid data, smaller than half the buffer size, sitting undecoded in the buffer _forever_, the DMA pointer is read when the gdb event loop goes into idle timeout.

SWO decoding and bit-banged GPIO are the two subsystems where the rt-thread abstraction layer introduced unacceptable overhead, requiring direct hardware register or HAL access.

---

## DWT Trace

`swo_dwt_itm_decode.c` replaces `swo_itm_decode.c`: command-line compatible with the original `mon swo`, but adding `top` and `graph`.

`monitor dwt` (`cortexm_dwt()` in `cortexm.c`) configures target `DWT_CTRL` and `ITM_TCR` to generate DWT packets.

`monitor swo` (`swo_itm_decode()` in `swo_dwt_itm_decode.c`) decodes both ITM software packets and DWT hardware packets (PC sample, exception trace, data trace, local and global timestamp) from the SWO byte stream, using the DMA path described above.

Three output formats: `log`, `top` and `graph`.

- `log` outputs DWT trace to USB CDC as a text stream. The text is suitable for parsing using traditional unix tools (`grep -e "^PC:" dwt.log|sort|uniq -c|sort -rn|head`) or python scripts.

- `top` sorts the PC samples in up to 4096 buckets and outputs the top 25 periodically. (DWT_TOP_MAX_BUCKETS, DWT_TOP_N). Suitable for unattended capture of PC traces to SD card.

- `graph` outputs the same data as `top`, but formatted for ansi terminal. Suitable for seeing firmware status at a glance.

- the accepted tradeoff: no symbol resolution, hex addresses only.

ARMv7-M (M3/M4/M7) and ARMv8-M (M23/M33/...) define DWT trace as implementation-dependent. DWT is absent on ARMv6-M (Cortex-M0/M0+/M1).

`mon dwt status` prints an error message if DWT is absent.

For a full PC trace (ETM, Embedded Trace Macrocell), see [Orbuculum](https://github.com/orbcode/orbuculum).

---

## MTB Trace

`monitor mtb` (`cortexm_mtb()` in `cortexm_mtb.c`) reads the CoreSight Micro Trace Buffer. Reference: ARM DDI 0486B.

On attach, `adi.c` walks the Arm CoreSight ROM. If MTB is present, MTB base address is stored in `ap->mtb_base`. SRAM base is read from the MTB BASE register on first use and stored in `ap->mtb_sram`. `cortexm_mtb_fixup()` overrides `ap->mtb_base` and/or `ap->mtb_sram` for chips where the ROM table or BASE register is wrong (LPC84x).

`monitor mtb status` and `monitor mtb dump` only read. `mon mtb size` writes: stops tracing, writes all ones to register MTB POSITION to measure maximum buffer size (DDI 0486B, B.1), then restores POSITION and tracing. On restore failure, tracing is left off.

MTB could be extended to sample the trace buffer while the target is running, and provide a display of most active addresses, similar to "mon swo top".

---

## Semihosting

In gdb server mode semihosting calls are executed locally, on arm can tool.
Contrary to upstream, there is no [gdb file i/o](https://www.sourceware.org/gdb/current/onlinedocs/gdb.html/File_002dI_002fO-Remote-Protocol-Extension.html): no F-packets, no waiting on gdb.
Every syscall completes synchronously inside `semihosting_request()` and the target is resumed immediately.
All changes are confined to `semihosting.c`.

Semihosting file i/o maps to rt-thread's POSIX file layer.
The file descriptor table is global to the probe.
An ownership mask `semihosting_opened_fds` records which fds semihosting opened; target access to other fd is rejected.

The semihosting implementation limits itself to syscalls that can be executed immediately. SYS_READC returns -1 and SYS_READ on stdin returns EOF.

Semihosting logs to the console. If logging every syscall is needed, set `DBG_LVL` to `DBG_DBG` in `semihosting.c`.

**Verification** After changes to semihosting, run `tools/Arduino/SemihostingTest.ino`.

---

## Display and UI

The display subsystem consumes no CPU when display content does not change.

u8g2 was originally written for a 16 MHz 8-bit processor. On the 32-bit AT32F405 at 216 MHz, display update performance is not a constraint.

The display is square - a single menu layout for all four orientations (0°, 90°, 180°, 270°).

---

## Font System

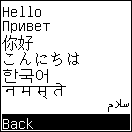
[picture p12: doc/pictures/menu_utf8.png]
UTF8 Font Demo


All font processing — glyph selection, subsetting, RTL reordering — occurs at build time on the host PC. The MCU performs no font processing at runtime. The compiled firmware contains only the glyphs used.

In this text "glyph" means a Unicode code point. Limited to ASCII, "character" and "glyph" are the same.

### Updating the Font

After editing any menu source file and introducing new characters, regenerate `unifont.h`:

```bash
cd arm_can_tool
./tools/update_unifont.sh
```

### Manual Font Generation

The following documents what `update_unifont.sh` performs.

**Step 1 — Devanagari shaping.** `hbpp.py` reads `mui_form_*.c` and produces `mui_hb_strings.h` containing pre-shaped Devanagari strings.

```bash
tools/hbpp/hbpp.py font/unifont-17.0.04.otf 16 \
    applications/mui_form_en.c \
    applications/mui_hb_strings.h
```

**Step 2 — Arabic reshaping and bidi reordering.**

For right-to-left languages such as Arabic, `u8g2-rtl-strings.py` performs Arabic reshaping and bidi reordering at build time. No runtime processing is required.

`u8g2-rtl-strings.py` reads `mui_form_*.c` and produces `u8g2_rtl_strings.h` containing pre-shaped right-to-left strings.

```bash
tools/u8g2-rtl-strings/u8g2-rtl-strings.py \
    applications/mui_form_en.c > applications/u8g2_rtl_strings.h
```

**Step 3 — Concatenate source files.**

```bash
cat applications/mui_app.c \
    applications/mui_form_en.c \
    applications/mui_form_zh.c \
    applications/u8g2_rtl_strings.h \
    applications/mui_hb_strings.h > /tmp/all_utf8.c
```

**Step 4 — Build bdfconv.**

```bash
make -C packages/u8g2-official-latest/tools/font/bdfconv
```

**Step 5 — Generate font header.** `bdfconv` scans the concatenated file for all characters used, adds the full Latin alphabet (glyphs 32–127), and produces `unifont.h`.

```bash
packages/u8g2-official-latest/tools/font/bdfconv/bdfconv \
    -v -f 1 -m '32-127' \
    -u /tmp/all_utf8.c \
    -n u8g2_font_unifont \
    -o applications/unifont.h \
    font/unifont-17.0.04.bdf
```

### Font Files

An overview of the font files:

- `unifont-*.otf`: Font file, source of glyph metrics. Used in [harfbuzz](https://github.com/harfbuzz/harfbuzz) `hbpp.py` text rewriting and reshaping (Devanagari). Produces `mui_hb_strings.h`
- `unifont-*.bdf`: Font file, source of glyph bitmaps. Used in `bdfconv` to extract only the glyphs used in the menu sources. Produces `unifont.h`.
- `unifont.h`: C header with the bitmaps of all glyphs used in the menu system. Used in `u8g2_SetFont()`.

### TTF and OTF Fonts

Convert to BDF format first using `otf2bdf`:

```bash
otf2bdf -r 72 -p 32 'Font Awesome 6 Free-Solid-900.otf' > fontawesome.bdf
```

---

## Screenshot

The `printscreen` shell command outputs the current OLED display content as a PBM image over the console serial port. Used to capture menu screenshots for documentation.

**Procedure:**

1. Connect a terminal emulator to the SWD console port.
2. Navigate to the screen to capture.
3. At the `msh />` prompt, run `printscreen`.
4. Copy the PBM output into a text file `input.pbm`.
5. Convert to PNG:

```bash
convert input.pbm -rotate 90 \
        -bordercolor white -border 1 \
        -bordercolor black -border 1 \
        output.png
```

---

## Resource Usage

| Resource | Total | Used | % |
| --- | ----- | ---- | - |
| RAM | 102 kB | 65 kB | 63% |
| Internal flash | 256 kB | 31 kB | 12% |
| External QSPI flash | 16 MB | 893 kB | 5% |

RAM is the most constrained resource.

---

## CAN Bus

The CAN bus interface does not use the rt-thread CAN bus device:

- CAN filters are written directly to bxcan filter registers. `canfilter_bxcan_f0.c` is a port to C of `canfilter_bxcan.cpp` from [koendv/canfilter](https://github.com/koendv/canfilter).
- Bit timing is set using HAL. `can_calc_bittiming.c` is a port of the Linux kernel's `can_calc_bittiming()` for bxcan at 108 MHz.
- `canbus_event.c` uses HAL drivers for CAN bus receive and transmit.

### CAN Bus Receive Hook

`bool can_rx_consumed(can_stored_frame_t *stored_frame);`

A weak function `can_rx_consumed()` is called for every CAN bus frame received. Override with a strong `can_rx_consumed()` to add higher-level CAN bus decoding, e.g. J1939.

Returns `true` if the frame was consumed by protocol decoder: frame is not delivered to slcan, gs_usb, or Lua.
Return  `false` if frame was not consumed by protocol decoder: frame is delivered as normal.

Use `cdc0_write()` to write protocol decoder output. Decoder output is written to usb cdc0, and to sdcard if `Startup->logging` is set.

## Lua Scripting Engine

### Design Principles

Two principles drive the Lua implementation.

**Event-driven execution.** Lua is implemented as an event-driven system: the Lua thread blocks on `rt_event_recv()` until an event fires, runs the registered handler briefly, then returns to sleep.

**Frugal RAM use.** Standard Lua libraries are stored in QSPI flash as read-only tables (rotables). User functions are stored as bytecode in internal flash and executed in place.

### Event Loop

The Lua event loop is in `script_engine.c`. The loop blocks on `rt_event_recv()` with three timeout modes:

| Condition | Timeout |
| --- | --- |
| No target running, no flash receive in progress | 1 second |
| Target running | Polling interval (configurable, default 50 ms) |
| `flash.receive()` active | 30 seconds — aborts on timeout |

On each wake, the loop polls RTT and memwatch if a target is running, dispatches `EVENT_TARGET_HALTED` if the target has just stopped, then calls registered Lua handlers for each pending event bit.

Incremental garbage collection is called after all event handlers have run, and the system is idle.
Running garbage collection after event handlers reduces the need to run garbage collection during an event handler.

Example — in Lua scripting mode, a CAN frame arriving while a receive-event handler is registered:

- CAN bus packet passes hardware filter and generates a CAN RX interrupt.
- CAN1_RX0_IRQHandler() stores the CAN bus packet in a ring buffer and sets EVENT_CAN1_RX0_INDIC. (canbus_event.c)
- lua_task() wakes up in rt_event_recv() (script_engine.c)
- run_event_handler() calls Lua event handler for EVENT_CAN1_RX0_INDIC (script_engine.c)
- can.receive() returns CAN bus packet from ring buffer or nil if ring buffer empty. Does not wait. (can_log.lua)
- sys.write() logs packet (can_log.lua)
- event handler returns when ring buffer drained (can_log.lua)
- lua_task() sleeps on rt_event_recv() (script_engine.c)

### Autoexec

At boot, if **Startup → lua autoexec** is enabled, `lfs_run_autoexec` executes the bytecode stored in flash sector 0. Typically the bytecode registers event handlers.

If sector 0 is empty or invalid, the error is logged and scripting mode continues without event handlers.

### Flash Transfer via lfs_send.py

`lfs_send.py` transfers pre-compiled bytecode to internal flash over CDC1 using an HDLC-framed protocol with CRC-32 verification. On the device side, use `flash.receive()`.

**Protocol summary:**

- One HDLC frame per 2 kB flash sector.
- Frame payload: version(1) + command(1) + sector(2) + data(2048) + CRC-32(4) = 2056 bytes.
- HDLC framing: `0x7E` flag, `0x7D` escape, escaped byte XOR `0x20`.
- Device responds ACK (`0x06`) or NAK (`0x15`) per frame.
- Continuation bit in command byte: set if more frames follow, clear on last frame.
- 30-second timeout per frame on the device side.

### Deviations from Standard Lua

#### `LUA_32BITS`

Lua integers and floats are 32-bit. This affects `math.maxinteger`, float precision, and `math.random`.

#### `LUA_NOCVTS2N`

Standard Lua implicitly coerces strings to numbers in arithmetic (e.g. `"10" + 5`). This is disabled. The string metatable and its heap allocation are eliminated entirely. Use `tonumber()` for explicit conversion.

#### Constants as Zero-Argument Functions

The rotable implementation cannot store string or float constants. Float and string constants are exposed as zero-argument functions.

#### String Method Syntax Not Available

The string metatable `__index` field is not set. `s:method()` syntax is not available.

```lua
-- Not available:
("hello"):upper()

-- Use instead:
string.upper("hello")
```

### Platform Configuration

Platform-specific settings are in `luaconf_platform.h`:

- Lua output (`print`, error messages) routes to CDC1.
- `require` searches `/sdcard/lua/` and `/flash/lua/` for modules.

### `LUAI_MAXCCALLS` and `LUAI_MAXSTACK`

The rt-thread c stack for the Lua task is limited to `LUA_STACK_SIZE` (8 kbyte).
`LUAI_MAXCCALLS` is lowered from Lua's default of 200 to 20 to bound worst-case *c stack* use.
Real event handlers nest little, so 20 leaves margin while still failing fast on runaway recursion.
Lua's own *value stack* is separate from the rt-thread c stack, and allocated from the Lua heap.
`LUAI_MAXSTACK`, the size of Lua's *value stack*, is derived from `LUAI_MAXCCALLS` to keep the two consistent.

### Memory Strategy: Rotable

All libraries are opened as rotables. A rotable wraps a `const rotable_Reg[]` array in flash as a Lua userdata. The heap cost is one pointer plus the userdata header — typically 8–12 bytes per library, regardless of how many functions it contains.

### Tab Completion

Tab completion is in `lua_completion.c`. The completion system operates on two levels: global names in `_G`, and members of a table or rotable one level deep using `.` or `:`.

### microrl

Lua shell uses the microrl command-line editing library.

Standard microrl splits a command line in c-style arguments (argc, argv). This is not used in arm can tool.

Microrl is patched to pass the raw command line instead.
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

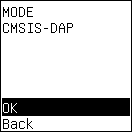
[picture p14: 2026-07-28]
doc/pictures/menu_mode_cmsisdap.png

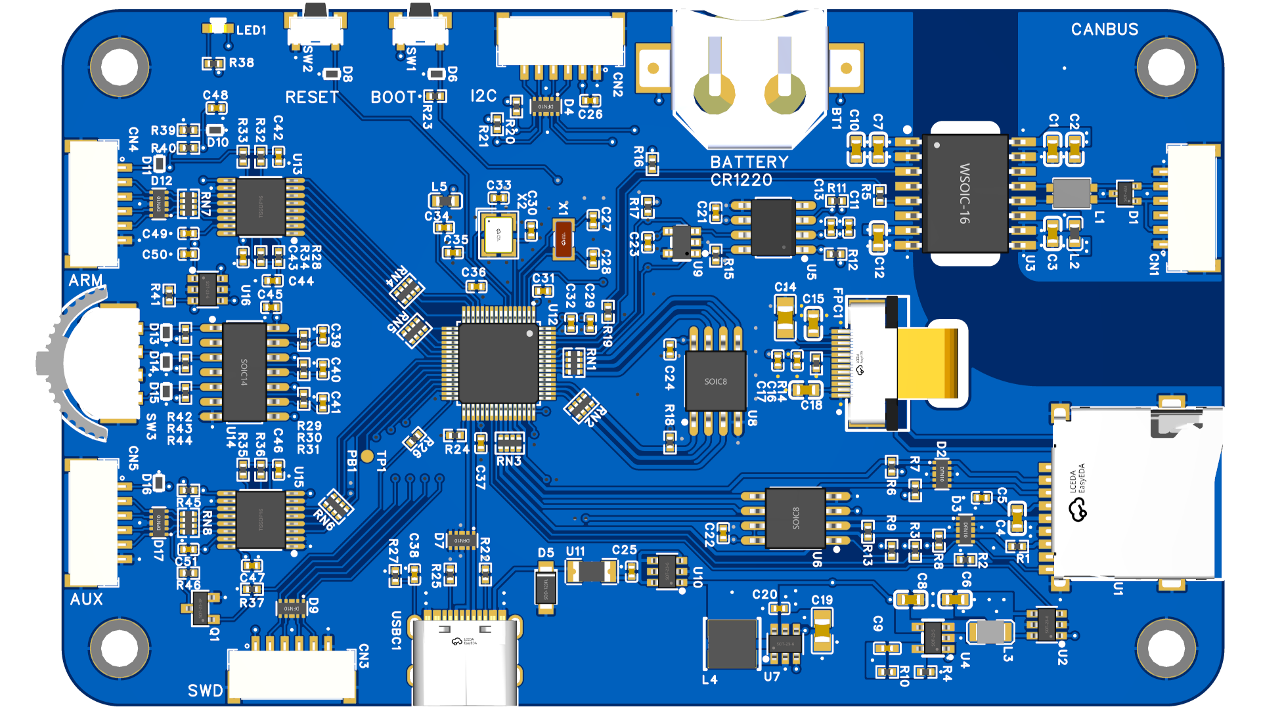
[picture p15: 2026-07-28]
doc/pictures/3d_pcb_back.png

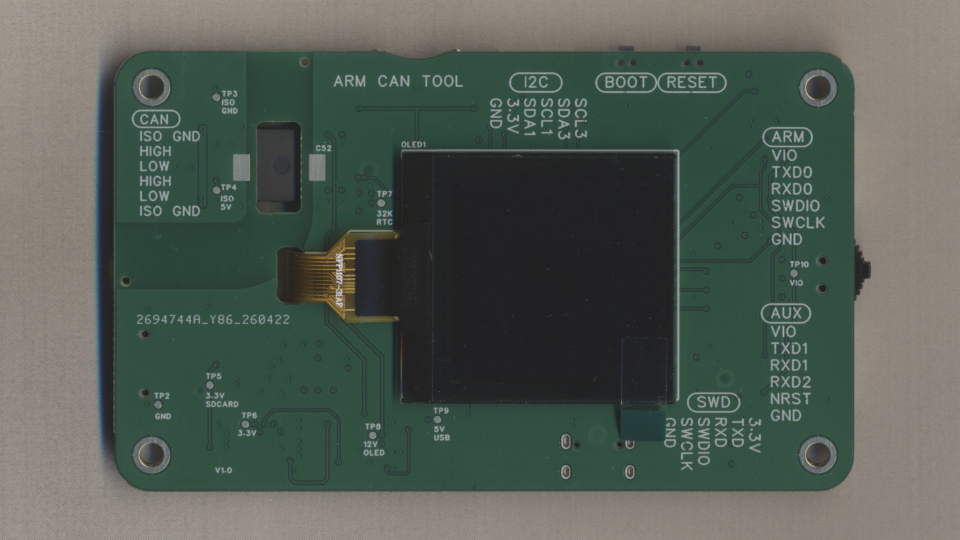
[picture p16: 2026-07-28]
doc/pictures/pcb_display_small.jpg

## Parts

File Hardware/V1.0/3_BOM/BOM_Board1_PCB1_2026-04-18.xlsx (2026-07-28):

No. | Designator | Quantity | Manufacturer | Manufacturer Part | Comment | Footprint | Mounting Style | Supplier Part
1 | BT1 | 1 | MYOUNG(美阳) | MY-1220-03 | MY-1220-03 | BAT-SMD_MY-1220-03 | SMT | C964818
2 | C1,C7,C15,C18 | 4 | YAGEO(国巨) | CC0603KRX7R9BB104 | 100nF | C0603 | SMT | C14663
3 | C2,C10 | 2 | SAMSUNG(三星) | CL10A106MA8NRNC | 10uF | C0603 | SMT | C96446
4 | C3,C12 | 2 | SAMSUNG(三星) | CL10A105KB8NNNC | 1uF | C0603 | SMT | C15849
5 | C4,C8 | 2 | SAMSUNG(三星) | CL10A475KO8NNNC | 4.7uF | C0603 | SMT | C19666
6 | C5,C13,C16,C22,C23,C24,C31,C32,C35,C36,C37,C42,C43,C44,C45,C46,C47,C48,C50,C51 | 20 | SAMSUNG(三星) | CL05B104KO5NNNC | 100nF | C0402 | SMT | C1525
7 | C6 | 1 | SAMSUNG(三星) | CL10A226MQ8NRNC | 22uF | C0603 | SMT | C59461
8 | C9 | 1 | FH(风华) | 0402CG220J500NT | 22pF | C0402 | SMT | C1555
9 | C11,C21,C25,C26,C34,C39,C40,C41,C49 | 9 | SAMSUNG(三星) | CL05A105KA5NQNC | 1uF | C0402 | SMT | C52923
10 | C14 | 1 | SAMSUNG(三星) | CL21A225KBQNNNE | 2.2uF | C0805 | SMT | C377773
11 | C17,C20,C29 | 3 | SAMSUNG(三星) | CL05A475MP5NRNC | 4.7uF | C0402 | SMT | C23733
12 | C19 | 1 | muRata(村田) | GRM21BR61H106KE43L | 10uF | C0805 | SMT | C440198
13 | C27,C28 | 2 | FH(风华) | 0402CG180J500NT | 18pF | C0402 | SMT | C1549
14 | C30,C33 | 2 | FH(风华) | 0402CG150J500NT | 15pF | C0402 | SMT | C1548
15 | C38 | 1 | FH(风华) | 0402B472K500NT | 4.7nF | C0402 | SMT | C1538
16 | CN1,CN2,CN3,CN4,CN5 | 5 | JST | SM06B-GHS-TB(LF)(SN) | SM06B-GHS-TB(LF)(SN) | CONN-TH_SM06B-GHS-TB-LF-SN | SMT | C133065
17 | D1 | 1 | ST(意法半导体) | ESDCAN03-2BWY | ESDCAN03-2BWY | SOT-323-3_L2.0-W1.3-P1.30-LS2.1-BR | SMT | C1973833
18 | D2,D3,D4,D7,D9,D12,D17 | 7 | 宏迦橙 | H5VU25U | H5VU25U | DFN2510-10_L2.5-W1.0-P0.50-BL | SMT | C7420374
19 | D5 | 1 | R+O(宏嘉诚) | SMF5.0A | SMF5.0A | SOD-123FL_L2.7-W1.8-LS3.8-RD | SMT | C19077497
20 | D6,D8,D10,D11,D13,D14,D15,D16 | 8 | 宏迦橙 | H5VL10B | H5VL10B | SOD-882_L1.0-W0.6-BI | SMT | C7420372
21 | FPC1 | 1 | JS(钜硕电子) | AFC07-S12ECA-00 | AFC07-S12ECA-00 | FPC-SMD_12P-P0.50_AFC07-S12ECA-00 | SMT | C262585
22 | L1 | 1 | TDK | ACT1210-510-2P-TL00 | ACT1210-510-2P-TL00 | FILTER-SMD_4P-L3.2-W2.5-BL_ACT1210 | SMT | C95572
23 | L2 | 1 | Sunlord(顺络) | GZ1608D601TF | GZ1608D601TF | L0603 | SMT | C1002
24 | L3 | 1 | TDK | TFM252012ALM-1R0MTAA | 1uH | IND-SMD_L2.5-W2.0-A | SMT | C433057
25 | L4 | 1 | cjiang(长江微电) | FTC404020S100MGCA | 10uH | IND-SMD_L4.1-W4.1_FTC404020S | SMT | C39676074
26 | L5 | 1 | Sunlord(顺络) | SDFL1608S100KTF | 10uH | L0603 | SMT | C1035
27 | LED1 | 1 | LITEON(光宝) | LTST-S270KGKT | LTST-S270KGKT | LED-SMD_L1.7-W0.6-RD | SMT | C125113
28 | OLED1 | 1 | Zhengzhou Zhongjingyuan(中景园) | ZJY150-2828KSWKG03 | ZJY150-2828KSWKG03 | OLED-ZJY150-2828KSWKG03 | SMT | https://item.taobao.com/item.htm?id=756962244579
29 | Q1 | 1 | AOS | AO3400A | AO3400A | SOT-23-3_L2.9-W1.3-P1.90-LS2.4-BR | SMT | C20917
30 | R1,R5,R13,R19,R26 | 5 | UNI-ROYAL(厚声) | 0402WGF330JTCE | 33Ω | R0402 | SMT | C25105
31 | R2,R3,R6,R7,R8,R41 | 6 | UNI-ROYAL(厚声) | 0402WGF4702TCE | 47kΩ | R0402 | SMT | C25792
32 | R4 | 1 | UNI-ROYAL(厚声) | 0402WGF3302TCE | 33kΩ | R0402 | SMT | C25779
33 | R9,R11,R12,R16,R18,R23,R39,R42,R43,R44,R45,R46 | 12 | UNI-ROYAL(厚声) | 0402WGF1002TCE | 10kΩ | R0402 | SMT | C25744
34 | R10 | 1 | UNI-ROYAL(厚声) | 0402WGF1503TCE | 150kΩ | R0402 | SMT | C25755
35 | R14 | 1 | UNI-ROYAL(厚声) | 0402WGF9103TCE | 910kΩ | R0402 | SMT | C25800
36 | R15,R17,R20,R21,R40 | 5 | UNI-ROYAL(厚声) | 0402WGF4701TCE | 4.7kΩ | R0402 | SMT | C25900
37 | R22,R25 | 2 | UNI-ROYAL(厚声) | 0402WGF5101TCE | 5.1kΩ | R0402 | SMT | C25905
38 | R24 | 1 | UNI-ROYAL(厚声) | 0402WGF1202TCE | 12kΩ | R0402 | SMT | C25752
39 | R27 | 1 | UNI-ROYAL(厚声) | 0402WGF1004TCE | 1MΩ | R0402 | SMT | C26083
40 | R28,R32,R33,R34,R35,R36,R37 | 7 | UNI-ROYAL(厚声) | 0402WGF1003TCE | 100kΩ | R0402 | SMT | C25741
41 | R29,R30,R31 | 3 | UNI-ROYAL(厚声) | 0402WGF2202TCE | 22kΩ | R0402 | SMT | C25768
42 | R38 | 1 | UNI-ROYAL(厚声) | 0402WGF1500TCE | 150Ω | R0402 | SMT | C25082
43 | RN1,RN2,RN3,RN4,RN5,RN6,RN7,RN8 | 8 | YAGEO(国巨) | YC124-FR-0733RL | 33Ω | RES-ARRAY-SMD_0402-8P-L2.0-W1.0-BL | SMT | C136851
44 | SW1,SW2 | 2 | SHOU HAN(首韩) | TS24CA | TS24CA | SW-SMD_TS24CA | SMT | C393942
45 | SW3 | 1 | ALPSALPINE(阿尔卑斯阿尔派) | SLLB510100 | SLLB510100 | SW-SMD_SLLB510100 | SMT | C125039
46 | U1 | 1 | XUNPU(讯普) | TF-115Y-ACP9 | TF-115Y-ACP9 | SIM-SMD_TF-115Y-BCP9 | SMT | C5454948
47 | U2,U10,U16 | 3 | TI(德州仪器) | TPS22929DDBVR | TPS22929DDBVR | SOT-23-6_L2.9-W1.6-P0.95-LS2.8-BL | SMT | C415177
48 | U3 | 1 | Chipanalog(川土微) | CA-IS2062VW | CA-IS2062VW | CA-IS305XW | SMT | C5271191
49 | U4 | 1 | TI(德州仪器) | TLV62569DBVR | TLV62569DBVR | SOT-23-5_L3.0-W1.7-P0.95-LS2.8-BR | SMT | C141836
50 | U5 | 1 | WAVE(兴威帆电子) | SD8931 | SD8931 | SOP-8_L4.9-W3.9-P1.27-LS6.0-BL-1 | SMT | C48982555
51 | U6,U8 | 2 | WINBOND(华邦) | W25Q128JVSIQ | W25Q128JVSIQ | SOIC-8_L5.3-W5.3-P1.27-LS8.0-BL | SMT | C97521
52 | U7 | 1 | TI(德州仪器) | TLV61046ADBVR | TLV61046ADBVR | SOT-23-6_L2.9-W1.6-P0.95-LS2.8-BL | SMT | C464815
53 | U9 | 1 | XBLW(芯伯乐) | 24C64S(XBLW) | 24C64S(XBLW) | SOT-23-5_L2.9-W1.6-P0.95-LS2.8-BR | SMT | C41408505
54 | U11 | 1 | Littelfuse(美国力特) | 1206L050YR | 1206L050YR | F1206 | SMT | C163512
55 | U12 | 1 | Artery(雅特力) | AT32F405RCT7-7 | AT32F405RCT7-7 | LQFP-64_L7.0-W7.0-P0.40-LS9.0-TL | SMT | C9900094935
56 | U13,U15 | 2 | TI(德州仪器) | SN74AVC4T774PWR | SN74AVC4T774PWR | TSSOP-16_L5.0-W4.4-P0.65-LS6.4-BL | SMT | C129363
57 | U14 | 1 | Nexperia(安世) | 74HC14D,653 | 74HC14D,653 | SOIC-14_L8.7-W3.9-P1.27-LS6.0-BL | SMT | C5605
58 | USBC1 | 1 | 韩国韩荣 | TYPE-C-31-M-12 | TYPE-C-31-M-12 | USB-C_SMD-TYPE-C-31-M-12 | DIP | C165948
59 | X1 | 1 | EPSON(爱普生) | Q13FC1350000400 | 32.768kHz | FC-135R_L3.2-W1.5 | SMT | C32346
60 | X2 | 1 | CJ(江苏长电/长晶) | CJ13-120001210B20 | 12MHz | CRYSTAL-SMD_4P-L3.2-W2.5-BL | SMT | C2875246

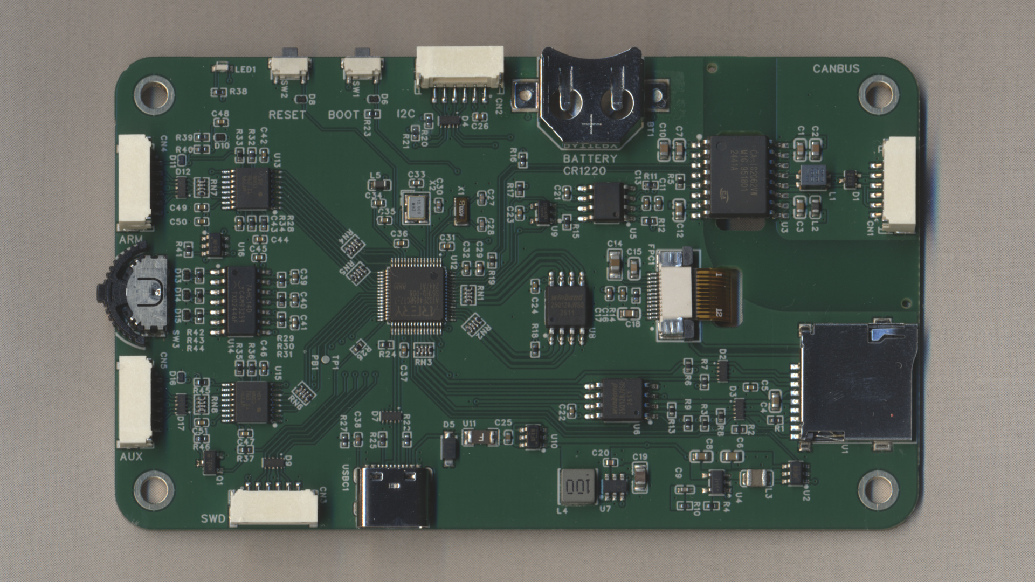
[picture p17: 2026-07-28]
doc/pictures/pcb_component_big.jpg

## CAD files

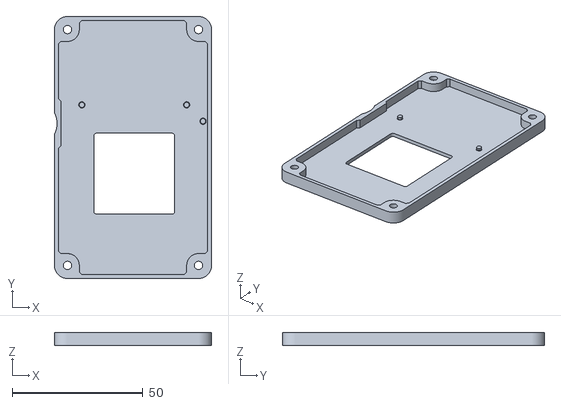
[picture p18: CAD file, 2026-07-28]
Hardware/V1.0/5_3D/enclosure/3DShell_3DShell_PCB1_B.stl
60.0 x 100.0 x 5.00

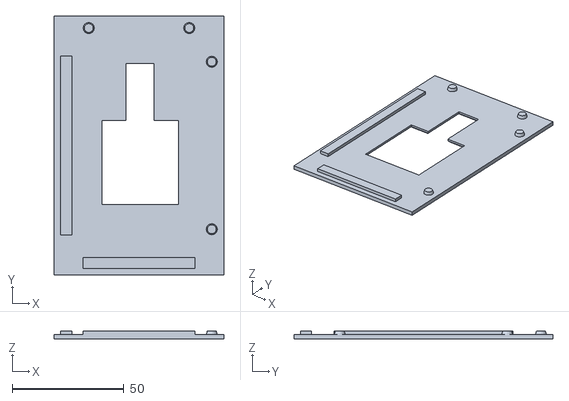
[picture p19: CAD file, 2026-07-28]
Hardware/V1.0/5_3D/fixture/fixture.stl
76.0 x 116.0 x 3.60

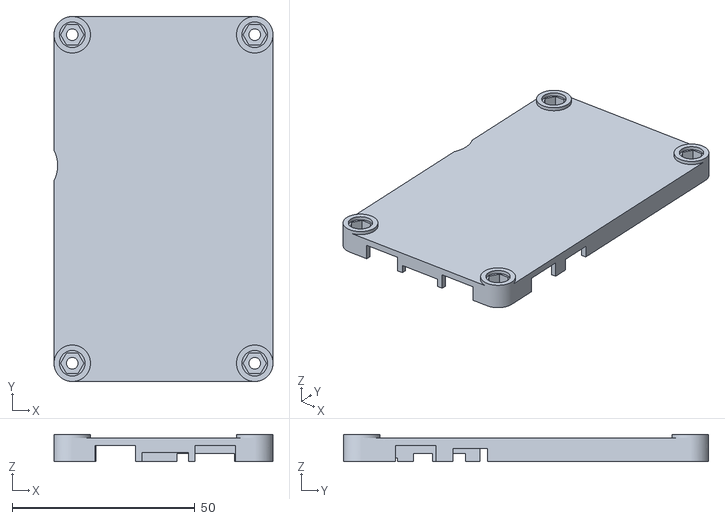
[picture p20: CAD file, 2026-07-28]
Hardware/V1.0/5_3D/enclosure/3DShell_3DShell_PCB1_T.stl
60.0 x 100.0 x 7.40

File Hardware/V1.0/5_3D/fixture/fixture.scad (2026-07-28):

/* 
 PCB Assembly Fixture for gluing ZJY154-2828KSWKG03 OLED to ARM CAN TOOL PCB.
 
 This fixture 
  1. HOLDS the 60x100mm PCB securely in place via press-fit bumps
  2. POSITIONS the OLED display accurately for gluing

 Written in OpenSCAD https://openscad.org
 */

eps = 0.01;
$fn = 16;

pcb_length = 100.0;        // X dimension (mm)
pcb_width = 60.0;          // Y dimension (mm)
pcb_thickness = 1.6;       // Z dimension (mm)
pcb_clearance = 0.2;       // Overall clearance for PCB fit (mm)

oled_width = 37.3;         // X dimension (mm)
oled_height = 33.9;        // Y dimension (mm)
oled_tolerance = 0.2;      // Manufacturing tolerance (±mm)
oled_clearance = 0.2;      // Clearance for OLED placement 
oled_chamfer = 1.0;        // For easy insertion
oled_center_y = 42.45;     // Center Y position (from PCB bottom edge at 0)
oled_center_x = 30.48;     // Center X position (from PCB left edge at 0)

cable_width = 12.0;        // Width of flat cable (X direction when extended)
cable_length = 25.0;       // Length of cable relief (Y direction)
cable_clearance = 0.6;     // Clearance for cable
cable_relief_width = cable_width + cable_clearance;
cable_relief_length = cable_length + cable_clearance;

border = 8.0;
base_thickness = 2.0;
bump_radius = 2.5;

module base_plate()
{
    translate([-border, -border, 0])
    cube([pcb_width+2*border, pcb_length+2*border, base_thickness]);
}

module bump() {
    // tapered bump for easy insertion
    translate([0, 0, base_thickness - eps])
    cylinder(h=pcb_thickness, r1=bump_radius, r2=bump_radius*0.8);
}

module bumps(){
    bump_positions = [
        [pcb_width+bump_radius+pcb_clearance/2, pcb_length/8, 0],
        [pcb_width+bump_radius+pcb_clearance/2, pcb_length*7/8, 0],
        [pcb_width/8, pcb_length+bump_radius+pcb_clearance/2, 0],
        [pcb_width*7/8, pcb_length+bump_radius+pcb_clearance/2, 0],
    ];

    for (pos = bump_positions) {
        translate(pos) bump();
    }

    translate([-2*bump_radius-pcb_clearance/2, pcb_length/8-bump_radius, 0])
    cube([bump_radius*2, pcb_length*3/4+2*bump_radius, base_thickness+pcb_thickness]);

    translate([pcb_width/8-bump_radius, -2*bump_radius-pcb_clearance/2, 0])
    cube([pcb_width*3/4+2*bump_radius, bump_radius*2, base_thickness+pcb_thickness]);
}

module oled() {
    oled_cutout_width = oled_width + oled_tolerance + oled_clearance;
    oled_cutout_height = oled_height + oled_tolerance + oled_clearance;

    translate([oled_center_x,oled_center_y,0])
    cube([oled_cutout_height, oled_cutout_width, 3*pcb_thickness], center = true);
    translate([oled_center_x,oled_center_y+oled_width/2+cable_relief_length/2-eps,0])
    cube([cable_relief_width, cable_relief_length, 3*pcb_thickness], center = true);
    
    /* chamfer for oled */
    translate([oled_center_x,oled_center_y,0])
    hull() {
        translate([0, 0, oled_chamfer+eps])
        cube([oled_cutout_height, oled_cutout_width, eps], center = true);
        
        translate([0, 0, -eps])
        cube([oled_cutout_height+2*oled_chamfer, oled_cutout_width+2*oled_chamfer, eps], center = true);
    }
    
    /* chamfer for cable */
    translate([oled_center_x,oled_center_y+oled_width/2+cable_relief_length/2-eps,0])
    hull() {
        translate([0, 0, oled_chamfer+eps])
        cube([cable_relief_width, cable_relief_length, eps], center = true);
        
        translate([0, 0, -eps])
        cube([cable_relief_width+2*oled_chamfer, cable_relief_length+2*oled_chamfer, eps], center = true);
    }
}

module fixture() {
    difference() {
        union() {
            base_plate();
            bumps();
        }
        oled();
    }
}

module drawing() {
    difference() {
        projection()
        base_plate();

        offset(r = -1)
        projection()
        base_plate();
    }

    projection(){
        
        bumps();
        oled();
    }
}

if (true) {
    fixture();
 } else {
    drawing();
}

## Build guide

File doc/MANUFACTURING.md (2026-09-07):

# ARM CAN TOOL — Manufacturing

**Hardware Revision:** v1.0

## PCB Assembly

The PCB is designed for JLCPCB Economy PCBA. All components are SMD. The board leaves assembly fully soldered — no post-assembly soldering is required.

The complete hardware design — schematic, PCB layout, BOM, and pick-and-place files — is published on OSHWLab: [oshwlab.com/koendv/arm_can_tool](https://oshwlab.com/koendv/arm_can_tool).

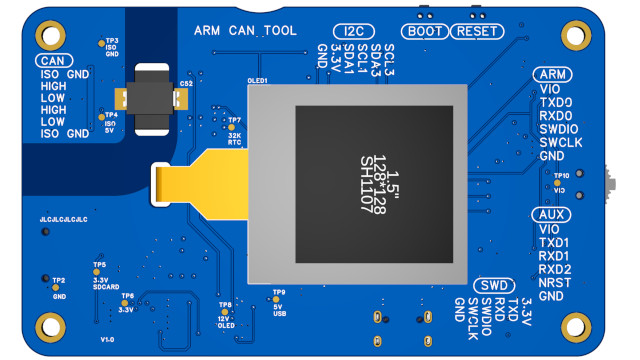
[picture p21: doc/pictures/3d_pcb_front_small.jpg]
PCB front


*PCB front.*

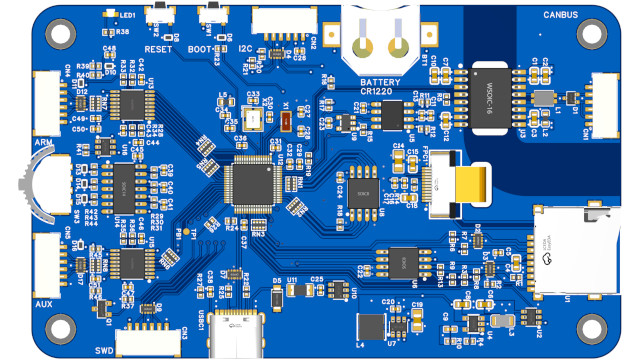
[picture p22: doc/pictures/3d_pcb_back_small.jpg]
PCB back


*PCB back.*

### JLCPCB Ordering Procedure

1. Open the OSHWLab project and export the manufacturing files (Gerbers, BOM, pick-and-place).
2. Upload to [jlcpcb.com](https://jlcpcb.com) and select the following options.

| Option | Value |
| --- | ----- |
| Stackup | JLC04161H-7628 |
| Mark on PCB | Order Number (Specify Position) |
| PCBA Qty | 2 or 5 |
| PCBA Remark | NO SOLDER PASTE ON MIDDLE PAD OF BATTERY HOLDER C964818 |

> **Order number position:** The PCB design places the JLCPCB order number outside the isolation barrier.

Silkscreen ink within the CAN bus isolation barrier reduces the maximum allowable isolation voltage. Do not place any text in the CAN bus isolation barrier.

> **No ultrasonic cleaning:** The SD8931 RTC contains an internal crystal. Ultrasonic cleaning will damage the crystal. Do not request ultrasonic board cleaning.

> **Component stock:** Before ordering, verify all components are in stock. If a component is out of stock, select a substitute and document the substitution in the schematic. For repeat orders, use the JLCPCB "repeat order" option to preserve previous component selections.

---

## Component Sourcing

Three components require attention:

- Processor
- OLED display
- CAN bus transceiver

Stock management:

- Maintain a personal parts library at JLCPCB sufficient for the assembly run.
- For out-of-stock JLCPCB components, use the LCSC "Notify Me" function to receive email notification when stock is restored.

Components for JLCPCB assembly are:

- [JLCPCB stock](https://jlcpcb.com/parts)
- [LCSC stock](https://www.lcsc.com/) (a JLCPCB sister company)
- JLCPCB [global sourcing](https://jlcpcb.com/help/article/how-to-use-jlcpcb-global-sourcing-parts-service) (Digikey, Mouser, ...)
- [consigned](https://jlcpcb.com/help/article/how-to-consign-parts-to-jlcpcb) - the customer supplies the component

### Processor — AT32F405

The AT32F405 is the probe MCU. LQFP-64, 7×7 mm body. Manufacturer part number: AT32F405RCT7-7.

Three sources:

| Source | Link |
| --- | ---- |
| LCSC (singles or full tray of 250) | [LCSC C19674180](https://www.lcsc.com/product-detail/C19674180.html) |
| JLCPCB (PCB assembly) | [JLCPCB C19674180](https://jlcpcb.com/partdetail/ARTERY-AT32F405RCT77/C19674180) |
| JLCPCB (consigned part) | [JLCPCB C9900094935](https://jlcpcb.com/partdetail/JLCPCBAssembly-AT32F405RCT77/C9900094935) |

The same part (AT32F405RCT7-7) has two different JLCPCB part numbers:

- C19674180 when JLCPCB supplies it from stock.
- C9900094935 when the customer consigns it.

**Consignment procedure (users outside China):**

- Purchase via a Chinese purchasing agent (e.g. [superbuy.com](https://superbuy.com)) from [taobao.com](https://taobao.com).
- Instruct purchasing agent to forward to the JLCPCB warehouse, using address in Chinese.
- Follow [JLCPCB consignment instructions](https://jlcpcb.com/help/article/how-to-consign-parts-to-jlcpcb) exactly.

Cost reference: USD 17.50 for 10 units (2025).

### CAN Bus Transceiver

| Part | Notes |
| ---- | ----- |
| [C5271191 CA-IS2062VW](https://jlcpcb.com/partdetail/Chipanalog-CAIS2062VW/C5271191) | CAN 2.0. Primary. Use if available. |
| [C5338808 CA-IS3062VW](https://jlcpcb.com/partdetail/Chipanalog-CAIS3062VW/C5338808) | CAN 2.0. Drop-in replacement. |
| [C49450889 NSIP9042-DSWR](https://jlcpcb.com/partdetail/NOVOSENSE-NSIP9042DSWR/C49450889) | CAN FD. Identical footprint and pinout. Datasheet-compatible; not yet tested in hardware. |

For full electrical comparison, see [HARDWARE.md#can-bus-transceiver](HARDWARE.md#can-bus-transceiver).

### OLED Display

| Parameter | Value |
| --- | ----- |
| Part number | ZJY150-2828KSWKG03 |
| Controller | SH1107 |
| Size | 1.5 inch, 128×128 pixels, monochrome |
| Interface | SPI |
| Connector | Plug-in FPC, 12 pins, 0.5 mm pitch, top connection |
| Datasheet | [ZJY150-2828KSWKG03.pdf](../Hardware/V1.0/6_DOC/datasheets/ZJY150-2828KSWKG03.pdf) |

⚠️ **Warning — two variants exist with incompatible connectors.** Order only the 12-pin plug-in FPC variant (插接式裸屏 排针默认不焊接推荐). The 25-pin soldering FPC variant is not compatible with this PCB.

| Variant | Connector | Compatible |
| --- | --- | --- |
| Plug-in FPC, 12 pins, 0.5 mm pitch | ✓ Correct | Yes |
| Soldering FPC, 25 pins, 0.65 mm pitch | ✗ Wrong | No |

OLED FPC

| Platform | Link |
| --- | ---- |
| Taobao (item) | [item.taobao.com/item.htm?id=676644812043](https://item.taobao.com/item.htm?id=676644812043) |
| Taobao (manufacturer store) | [oled-zjy.taobao.com](https://oled-zjy.taobao.com) |
| Alibaba | [product listing](https://www.alibaba.com/product-detail/1-5-inch-OLED-display-module_1601054555841.html) |
| AliExpress | [product listing](https://www.aliexpress.com/item/1005007579159330.html) |

Cost reference: USD 3.50 per unit (2025).

> The OLED display is not included in the PCB assembly order. It is installed manually in the final assembly step.

---

## Final Assembly

Assembly

The PCB arrives fully soldered from JLCPCB. Two manual steps are required: attaching the OLED display and closing the enclosure.

### Bill of Materials

| Item | Quantity |
| ---- | --- |
| Assembled PCB | 1 |
| OLED display (ZJY150-2828KSWKG03) | 1 |
| Enclosure — display side | 1 |
| Enclosure — component side | 1 |
| M3×10 nylon screws | 4 |
| M3 nylon nuts | 4 |
| 3M VHB sticker, 30×30×1 mm | 1 |
| Self-adhesive rubber feet, 6 mm diameter (optional) | 4 |

### Quality Verification

The side of the PCB without components has 1 mm test pads to measure power supplies and CAN bus isolation.

See [Hardware Tests](HARDWARE.md#hardware-tests) for post-assembly tests.

### OLED Installation

The OLED position is marked on the PCB. When the OLED is placed on the marked position, the flex cable reaches the FPC connector exactly, with the bend at the midpoint of the flexible section. A Kapton tape hinge facilitates accurate placement.

1. Clean the OLED bonding area on the PCB with IPA. Allow to dry before proceeding.
2. Place 3M VHB sticker on the display side of the PCB at the marked OLED position. Do not remove the adhesive liner yet.
3. Position the OLED display on the marked position.
4. Apply a strip of Kapton or masking tape along one edge of the OLED to create a hinge.
5. Flip the OLED up using the hinge. Remove the adhesive liner from the sticker.
6. Flip the OLED back down onto the PCB using the hinge.
7. Place PCB OLED-side down on a flat hard surface.
8. Apply pressure for 20 seconds.
9. Thread the OLED flex cable through the slot in the PCB.
10. Pull out the locking tab on the FPC connector. Insert the flex cable flat side down. Push the locking tab back in to secure.

3M VHB sticker cure time: 72 hours.

### Enclosure Assembly

1. Thread each M3 nylon nut onto its corresponding M3×10 screw.
2. Press each nut into the nut trap in the enclosure. The fit is tight — the nut should not fall out when the screw is removed.
3. Remove the screws. Place the PCB assembly into the component-side enclosure.
4. Place the display-side enclosure over the PCB.
5. Insert and tighten the four M3×10 screws.
6. Attach the four self-adhesive rubber feet to the base (optional).

Verification: The OLED display is visible through the display-side opening. All connectors are accessible at the enclosure edges.

### Assembly Fixture

For multi-unit production, a 3D-printable fixture accurately positions the OLED display during installation. OpenSCAD source files are in `tools/fixture/`.

---

## 3D Printed Enclosure

The enclosure consists of two parts — display side and component side — connected with four M3×10 nylon screws and nuts. The PCB is a structural element providing the enclosure with its stiffness.

Case dimensions: 60×100×14 mm.

### Generating STL Files

STL files are exported from EasyEDA Pro.

1. Open the EasyEDA Pro project and open the PCB.
2. Select **Export → 3D Shell File → STL → Export**.

EasyEDA exports a zip file named `3DShell_PCB1.zip` containing two STL files:

```
$ unzip 3DShell_PCB1.zip
  inflating: 3DShell_3DShell_PCB1_T.stl
  inflating: 3DShell_3DShell_PCB1_B.stl
```

`_B` (bottom) is the display-side enclosure. `_T` (top) is the component-side enclosure.

3. Repair the STL files before submitting for printing. EasyEDA exports may contain geometry errors that cause print failures. Upload each file to an online STL repair service such as [formware.co/onlinestlrepair](https://www.formware.co/onlinestlrepair).
4. Submit the repaired files to [jlc3dp.com](https://jlc3dp.com) or PCBWay for SLA printing.

### Material Selection

Two options:

- For lowest cost, print both halves in white 9600 resin (~USD 1.50, cheapest resin).
- For ease of use, print the display side in transparent 8100 resin and the component side in white 9600 resin — the transparent half allows reading connector pin labels. (~USD 4.50)

| Side | Colour | jlc3dp material | PCBWay material | Notes |
| ---- | --- | --- | --- | ----- |
| Display | Transparent | 8100 resin | UTR-8100 | Transparent allows reading connector labels on PCB silkscreen |
| Component | White | 9600 resin | UTR-8360 | Standard SLA resin |

> **High-temperature environments:** The standard resins (8100, 9600) begin to deform at 53°C–59°C. For high-temperature environments — such as a vehicle dashboard in direct sunlight — use heat-resistant materials: JLC Temp Resin (jlc3dp, 101°C) or Somos Perform (PCBWay, 122°C). Nylon is also suitable but has a coarser surface finish.

### Prototype Enclosure

For prototyping and fit verification, print the display-side enclosure in clear SLA resin (8100 resin). A transparent enclosure allows visual inspection of component clearances and connector alignment without disassembly.

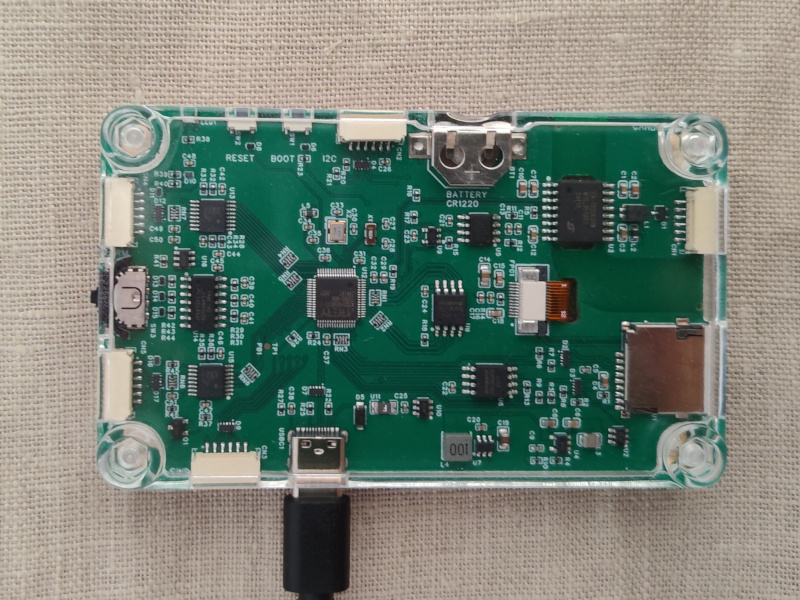
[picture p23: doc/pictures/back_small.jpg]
Clear prototype enclosure


*Prototype enclosure in clear SLA resin.*

### OLED Window (Optional)

A clear window may be installed over the OLED display opening to protect the display from dust and debris.

| Parameter | Value |
| --- | ----- |
| Material | PMMA (acrylic) or polycarbonate |
| Size | 50×50 mm |
| Thickness | 1 mm (2 mm presses against the display) |

Installation:

1. Locate the three positioning bumps on the inside of the display-side enclosure.
2. Place the window against all three bumps to centre it over the display.
3. Secure with OTA (optically transparent adhesive) or thin, non-spongy double-sided tape (2–3 mm wide, mobile phone repair type) applied to the enclosure, not to the display.

---

## Firmware Installation

The board leaves PCB assembly with no firmware installed. Firmware must be installed before the unit can be used or tested.

Install the UF2 bootloader and application firmware following the procedure in [INSTALL.md](INSTALL.md).

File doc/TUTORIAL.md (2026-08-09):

# ARM CAN TOOL — Tutorial: 5-Way Logging

Demonstrates simultaneous capture of five debug streams — serial console, RTT, SWO, CAN bus, and variable watchpoints — in a unified log, live over USB and recorded to SD card.

**Target firmware:** `tools/Arduino/FiveWay/` (STM32F412)

**Time estimate:** 15 minutes

**Host OS:** Linux (with udev rules from [INSTALL.md](INSTALL.md))

## Prerequisites

### Hardware

| Item | Description |
|---|---|
| ARM CAN Tool | Firmware v1.0+ |
| Target board | STM32F412 (WeAct CoreBoard used in examples) |
| Cables | JST GH 1.25 to DuPont 2.54, 6-pin |
| CAN transceiver | SN65HVD230 module or similar |
| SD card | FAT32 formatted |
| Termination resistor | 120 Ω (if CAN bus end node) |

### Host Software

| Tool | Installation |
|---|---|
| `arm-none-eabi-gdb` | [xPack GNU Arm Embedded GCC](https://github.com/xpack-dev-tools/arm-none-eabi-gcc-xpack) |
| `minicom` | `apt-get install minicom` |
| [Arduino IDE](https://www.arduino.cc) | With [STM32duino](https://github.com/stm32duino/Arduino_Core_STM32) core |

### Target Software

`tools/Arduino/FiveWay/` from the ARM CAN Tool repository. Compile using Arduino IDE or CLI.

Using the Arduino IDE:

- Select Tools->Board: `Generic STM32F4 series`, Tools->Part number `Generic F412RETx`.
- Enable **Optimize for Debugging** (Sketch → Optimize for Debugging).
- Compile and export: Sketch → Export Compiled Binary.

Or, using the Arduino cli:

```
arduino-cli compile -b STMicroelectronics:stm32:GenF4:pnum=GENERIC_F412RETX,opt=ogstd \
    --build-property "compiler.c.extra_flags=-g" \
    --build-property "compiler.cpp.extra_flags=-g" \
    --output-dir ~/Arduino/FiveWay/build \
    ~/Arduino/FiveWay
```

Choose IDE for ease of use; CLI for reproducible builds.

Note the .elf binary:

```
$  ls -l ~/Arduino/FiveWay/build/STMicroelectronics.stm32.GenF4/FiveWay.ino.elf
-rwxrwxr-x 1 koen koen 725832 Jun 28 17:28 /home/koen/Arduino/FiveWay/build/STMicroelectronics.stm32.GenF4/FiveWay.ino.elf
```

## Wiring

Wiring diagram

Connect between debugger and target:

- SWD serial wire debug
- RX/TX serial console
- SWO serial wire output
- NRST reset pin
- CAN bus

### ARM Connector → Target (SWD + Serial Console)

| ARM Connector (JST GH) | Target STM32F412 | Signal |
|---|---|---|
| Pin 1 (VIO) | 3.3V | Logic voltage |
| Pin 2 (TXD0) | PA10 (USART1_RX) | Target console TX |
| Pin 3 (RXD0) | PA9 (USART1_TX) | Target console RX |
| Pin 4 (SWDIO) | PA13 | SWD data |
| Pin 5 (SWCLK) | PA14 | SWD clock |
| Pin 6 (GND) | GND | Ground |

### AUX Connector → Target SWO

| AUX Connector | Target STM32F412 |
|---|---|
| Pin 4 (RXD2) | PB3 (SWO) |
| Pin 5 (NRST) | NRST |
| Pin 6 (GND) | GND |

### CAN Connector → CAN Transceiver

| CAN Connector | SN65HVD230 | Note |
|---|---|---|
| Pin 1 or 6 (ISO GND) | GND | Must connect |
| Pin 2 (CAN\_HIGH) | CAN\_H | |
| Pin 3 (CAN\_LOW) | CAN\_L | |
| Pin 4 (CAN\_HIGH) | CAN\_H | 120  Ω to Pin 5 |
| Pin 5 (CAN\_LOW) | CAN\_L |  |

⚠️ **CAN bus ground required.** Because the arm can tool CAN bus is electrically isolated, the arm can tool CAN bus needs its own ground connection. Connect ISO GND (Pin 1 or 6) to CAN bus ground.

⚠️ **No internal termination.** The probe has no internal 120 Ω resistors.

**Termination:** If ARM CAN Tool is the only node or end node, add 120 Ω across CAN_HIGH and CAN_LOW at the connector. The SN65HVD230 breakout module has its own onboard 120 Ω termination, giving two terminations on the bus.

**Verification:** With no power applied, resistance between CAN_HIGH and CAN_LOW is approximately 60 Ω (two 120 Ω terminations in parallel).

### CAN Transceiver →  Target

| SN65HVD230 | Target | Note |
|---|---|---|
| CAN RX | PB8 ||
| CAN TX | PB9 ||
| Pin 1 or 6 (ISO GND) | GND | Must connect |
| VCC | 3.3V ||

## Part 1: Tethered Mode — Live Logging to PC

Open two terminal windows:

| Terminal | Purpose | Command |
|---|---|---|
| Window 1 | GDB session | `arm-none-eabi-gdb` |
| Window 2 | Target console (unified log) | `minicom -D /dev/ttyBmpTarg` |

If udev rules are not installed, find device names: `ls /dev/ttyACM*`

### Enable CAN Bus with Logging

```
OLED: Startup → CAN bus → On
OLED: CAN bus → speed → 500000
OLED: CAN bus → logging → On
OLED: Settings → Store
```

The CAN bus is started up as soon as the ARM CAN Tool is switched on. CAN bus frames are logged to `/dev/ttyBmpTarg` in linux `candump` format.

### Set GDB Server Mode

```
OLED: Mode → GDB SERVER → OK
```

Probe saves settings and reboots.

### Connect GDB

```bash
arm-none-eabi-gdb
(gdb) target extended-remote /dev/ttyBmpGdb
```

### Scan and Attach

```bash
(gdb) monitor swd_scan
```

Verification:
```
Target voltage: 3.3V
Available Targets:
No. Att Driver
 1      STM32F412 M4
```

```bash
(gdb) attach 1
(gdb) file ~/Arduino/FiveWay/build/STMicroelectronics.stm32.GenF4/FiveWay.ino.elf
(gdb) load
Loading section .isr_vector, size 0x1c4 lma 0x8000000
Loading section .text, size 0x69dc lma 0x80001d0
Loading section .rodata, size 0xa64 lma 0x8006bac
Loading section .ARM, size 0x8 lma 0x8007610
Loading section .init_array, size 0x14 lma 0x8007618
Loading section .fini_array, size 0xc lma 0x800762c
Loading section .data, size 0x108 lma 0x8007638
Start address 0x08005778, load size 30516
Transfer rate: 10 KB/sec, 847 bytes/write.
```

The `load` gdb command writes the firmware `FiveWay.ino.elf` to the target `STM32F412`.

**Verification:**

```
(gdb) compare-sections
Section .isr_vector, range 0x8000000 -- 0x80001c4: matched.
Section .text, range 0x80001d0 -- 0x8006bac: matched.
Section .rodata, range 0x8006bac -- 0x8007610: matched.
Section .ARM, range 0x8007610 -- 0x8007618: matched.
Section .init_array, range 0x8007618 -- 0x800762c: matched.
Section .fini_array, range 0x800762c -- 0x8007638: matched.
Section .data, range 0x8007638 -- 0x8007740: matched.
```

The `compare-sections` gdb command reads the firmware back from target flash memory, calculates checksums, and compares with the checksums of the .elf binary.

### Find Variable Address for Watchpoint

```bash
(gdb) print &count
```

Verification:
```
$1 = (uint32_t *) 0x20000124 <count>
```

⚠️ **Use the address from GDB output, not the address above.** Compiler options or code changes will shift the address.

If GDB reports `No symbol "count" in current context`: the firmware was not compiled with debug symbols. Enable **Optimize for Debugging** in Arduino IDE (Sketch → Optimize for Debugging → Debug) and recompile.

If recompiling with debug symbols is not possible, the variable address can be found in the linker map file (`.map`) and used directly in the `mon memwatch` command.

### Configure Watchpoint

```bash
(gdb) mon memwatch count /d 0x20000124
```

⚠️ **Use the address from GDB output, not the address above.** Compiler options or code changes will shift the address.

### Enable RTT

```bash
(gdb) mon rtt enable
(gdb) mon rtt status
```

Verification: `rtt: on found: no`

After running program, and stopping with ctrl-c: `rtt: on found: yes`

### Configure SWO Decoding

SWO is _serial wire output_.

```
OLED: Serial → serial2 speed → 1000000
OLED: Serial → Serial Enable → serial2 → On
```

In `arm-none-eabi-gdb`:

```
(gdb) mon swo enable 1000000 decode
Channel mask: 11111111111111111111111111111111
```

The channel mask indicates all SWO channels are displayed.

### Run Target

```bash
(gdb) run
```

Verification: Target LED blinks.

### Observe Unified Log

Window 2 shows all five streams interleaved:

```
serial: 1
rtt: 1
count 1
swo: 1
(38.031027) can0 101#00000001
serial: 2
rtt: 2
count 2
swo: 2
(39.016001) can0 102#00000002
...
```

The CAN bus timestamps are seconds since ARM CAN Tool boot.

Verification:

| Stream | Expected output |
|---|---|
| Serial console | `serial: N` |
| RTT | `rtt: N` |
| SWO | `swo: N` |
| Watchpoint | `count N` |
| CAN bus | CAN packet in candump format |

Halt the target by typing ctrl-C in `arm-none-eabi-gdb`:

```
^C
Program received signal SIGINT, Interrupt.
(gdb) where
#0  getCurrentMillis ()
    at /home/koen/.arduino15/packages/STMicroelectronics/hardware/stm32/2.12.0/libraries/SrcWrapper/src/stm32/clock.c:51
#1  0x08005952 in delay (ms=1000)
    at /home/koen/.arduino15/packages/STMicroelectronics/hardware/stm32/2.12.0/cores/arduino/wiring_time.c:43
#2  0x0800048e in loop () at /home/koen/Arduino/FiveWay/FiveWay.ino:61
#3  0x08005772 in main ()
    at /home/koen/.arduino15/packages/STMicroelectronics/hardware/stm32/2.12.0/cores/arduino/main.cpp:58
```

Above output indicates the program was interrupted in `FiveWay.ino`, line 61, `delay(1000)`. Output may differ.

```
(gdb) mon rtt status
rtt: on found: yes ident: off halt: off channels: auto 0 1 3
max poll ms: 256 min poll ms: 8 max errs: 10
(gdb)
```

`rtt: on found: yes` indicates RTT is working fine.

In gdb server mode, list all available commands:

```
(gdb) mon help
```

Note some commands are only available after attaching to target.

### Filtering CAN Bus Addresses

Download [canfilter](https://github.com/koendv/canfilter).

Select CANBUS -> canfilter -> On

Filter CAN bus addresses 0x100 to 0x107:

```
$ canfilter -u 1209:8816 0x100-0x107 -v
usb device open success
Using bxCAN (F0/F1/F3) with 14 filter banks
bxcan std mask id 0x100 mask 0x7f8

Filter usage: 1/14 (7%)
usb programming success
```
Select Settings -> Store.

Push arm can tool reset button.

Note only CAN bus addresses 0x100 to 0x107 are logged.

To allow all CAN bus addresses:

```
$ canfilter -u 1209:8816 -a
```
Select Settings -> Store.

Select CANBUS -> canfilter -> Off.

Push arm can tool reset button.

## Part 2: Standalone Mode — Autonomous SD Card Logging

### Configure Startup Services

Navigate and enable each:

| Service | Menu path |
|---|---|
| Auto-attach | `Startup → debugger` |
| RTT | `Startup → rtt` |
| Watchpoint | `Startup → memwatch` |
| SD logging | `Startup → logging` |
| CAN bus | `Startup → CAN bus` |
| CAN logging | `CAN bus → logging` |

### Save Current Configuration

```
OLED: Settings → Store
```
Saves in EEPROM: GDB Server mode, CAN speed, watchpoint address, serial/SWO speeds, CAN filter settings, Startup.

### Insert SD Card

FAT32 or exFAT format required.

### Reboot

Press RESET or power cycle.

If target power is enabled (`Target → 3.3V Power`), the probe waits 5 seconds for power to settle before attempting to attach.

Verification: Target LED blinks

### Retrieve Logs

The log is flushed every 120 seconds (LOG\_SYNC\_SECONDS). Wait five minutes. Then:

```
OLED: Mode → MASS STORAGE → OK
```

SD card appears as USB mass storage. Example:

```
koen@nuc:/media/koen/DF2B-4229$ ls
6a41d61c.log  rtthread.log
```

Two log files:

- `rtthread.log`: rt-thread console log
- `6a41d61c.log`: unified debug log - serial console, rtt, swo, watchpoint, CAN bus. Filename is number of seconds since January 1, 1970, in hex.

⚠️ **Probe will not debug while in Mass Storage mode.** Return to GDB Server mode via `Mode → GDB SERVER → OK` when done.

Verification: log file contains all five interleaved streams, identical in format to tethered output.

**Log rotation:** When log file reaches ~4 MB (LOG_SIZE_MAX), probe creates new log file and continues.

## Troubleshooting

### Probe Console

The probe runs rt-thread OS. The rt-thread console is available on the SWD connector (TXD/RXD pins) at 115200 baud, independent of target output. Use it to diagnose probe-side and target startup issues.

Mode gdb server, Startup->debugger->on, Startup->RTT->on, Startup->SWO->on. Expected output at boot:

```
102k ram
app

 \ | /
- RT -     Thread Operating System
 / | \     5.3.0 build Jul 20 2026 09:39:27
 2006 - 2024 Copyright by RT-Thread team
[u8g2] Attach device to spi22
I/SWD: ramfunc 3700 byte
I/EEPROM: settings 404 byte
I/SFUD: rom mount to '/'
I/SFUD: Found a flash chip. Size is 16777216 bytes.
I/SFUD: norflash0 flash device initialized successfully.
I/SFUD: Probe SPI flash norflash0 by SPI device spi20 success.
I/SFUD: spi flash mount to /flash
I/SD: sd card mount to /sdcard
I/USB: init
I/LED: init
I/CAN: speed 500000
I/CAN: event init
I/CAN: init
I/GSUSB: init
I/GSUSB: waiting
I/UART: uart2 speed 115200
I/UART: uart3 speed 115200
I/SWO: uart7 speed 1000000
I/STARTUP: attached
I/STARTUP: rtt
I/STARTUP: target running
I/SWO: init
I/MAIN: ready
msh />
```

See [boot log](REFERENCE.md#boot-log) for expected output without debugger, RTT and SWO started up at boot.

If the target is not yet powered at probe boot, `E/STARTUP: swd scan failed` is printed instead of `I/STARTUP: attached`, followed by a retry. Up to five retries are attempted before giving up.

| Symptom | Cause | Solution |
|---|---|---|
| Probe console shows `swd scan failed`, no retry | Target not powered or wiring fault | Verify VIO (ARM pin 1), SWDIO, SWCLK, GND |
| Probe console shows `attach retry 5/5`, no `attached` | Target unresponsive | Check target power, reset target, verify SWD wiring |

### Common Symptoms

| Symptom | Cause | Solution |
|---|---|---|
| `Target voltage: 0.000V` | VIO not connected | Check ARM pin 1 to target 3.3V |
| SWD scan finds no target | Wiring or power | Verify GND, SWCLK, SWDIO connections |
| SWO shows garbled output | Baud rate mismatch | Ensure `SWOStream swo(1000000)` matches `serial2 speed` |
| No CAN logs | Missing termination | Add 120 Ω resistor across CAN_HIGH/CAN_LOW |
| Watchpoint shows nothing | Wrong address | Re-run `p &count` after firmware changes |
| SD card not mounted | Format issue | Use FAT32 or exFAT, not  NTFS |
| Log file empty | Logging not enabled | Verify `Startup → logging` is On |
| Device not found at `/dev/ttyBmp*` | udev rules not installed | Use `ls /dev/ttyACM*` to find port |

## Summary

Five simultaneous debug streams captured in a unified log:

| Stream | Transport |
|---|---|
| Serial console | Target UART |
| RTT | Segger Real-Time Transfer |
| SWO | ITM trace |
| CAN bus | Isolated CAN 2.0 frames |
| Variable watchpoint | Live memory monitoring |

## Next Steps

- **RTT channel filtering** — See [DEBUG.md](DEBUG.md)
- **SWO port filtering** — See [DEBUG.md](DEBUG.md)
- **CAN ID filtering** — See [CANBUS.md](CANBUS.md)
- **Multiple watchpoints and format specifiers** — See [DEBUG.md](DEBUG.md)
- **Watchpoint timestamps** — See [DEBUG.md](DEBUG.md)
- **Lua scripting for standalone automation** — See [SCRIPT.md](SCRIPT.md)
- **Log file formats and retrieval** — See [LOGGING.md](LOGGING.md)
- **Additional startup services** (SWO decode, Lua autoexec, watchdog, trigger) — See [OPERATION.md](OPERATION.md)

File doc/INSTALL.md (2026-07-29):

# ARM CAN TOOL — Firmware Installation

## Memory Map

| Memory | Capacity | Contents | Installed |
|---|---|---|---|
| Processor ROM | Factory | DFU bootloader | Factory — read-only |
| Internal flash | 256 kB | UF2 bootloader | Once, using dfu-util |
| QSPI flash | 16 MB | Application firmware | First use and every update |

Board received from PCB assembly has no UF2 bootloader and no application firmware installed.
Complete both steps before first use.

Download from [Releases](https://github.com/koendv/arm_can_tool/releases):

| File | Purpose |
|---|---|
| `cherryuf2_arm_can_tool.bin` | UF2 bootloader |
| `rtthread.uf2` | Application firmware |

---

## Step 1 — Install UF2 Bootloader

Perform this step once. UF2 bootloader installs to internal flash via the factory DFU bootloader.

### Prerequisites

- `dfu-util` installed.
  - Linux: `sudo apt install dfu-util`
  - Windows: [dfu-util](https://dfu-util.sourceforge.net/)
- USB data cable connected to board.
- Windows only: WinUSB driver installed via Zadig for the Artery DFU device.

### Linux — USB Access Without sudo

Install udev rule:

```
$ echo 'SUBSYSTEMS=="usb", ATTRS{idVendor}=="2e3c", ATTRS{idProduct}=="df11", TAG+="uaccess", MODE="0664", GROUP="plugdev"' \
  | sudo tee /etc/udev/rules.d/99-at32.rules
$ sudo udevadm control -R
```

### Enter DFU Mode

DFU button sequence

Figure 1 — BOOT0 and RESET button locations.

1. Press and hold BOOT0 and RESET simultaneously.
2. Release RESET after about 1 second.
3. Release BOOT0 after about 1 further second.

Verification: Board enumerates as Artery DFU device.

```
$ lsusb | grep Artery
Bus 003 Device 012: ID 2e3c:df11 Artery-Tech DFU in FS Mode
```

If device does not appear:

- Check cable is a data cable, not a charging-only cable.
- Repeat the button sequence.

### Write UF2 Bootloader

```
$ sudo dfu-util -a 0 -d 2e3c:df11 --dfuse-address 0x08000000 -D cherryuf2_arm_can_tool.bin
```

Expected output:

```
Erase   [=========================] 100%        23692 bytes
Erase done.
Download [=========================] 100%        23692 bytes
Download done.
File downloaded successfully
```

Verification: Output shows `File downloaded successfully`.

On normal boot, UF2 bootloader starts application automatically.

---

## Step 2 — Install Application Firmware

UF2 bootloader exposes QSPI flash as USB mass storage. No additional tools required.

### Enter UF2 Bootloader Mode

UF2 bootloader button sequence

Figure 2 — Multi-direction switch and RESET button locations.

1. Press and hold the multi-direction switch and RESET simultaneously.
2. Release RESET after about 1 second.
3. Release multi-direction switch after about 1 further second.

Green LED illuminates. USB mass storage device named CherryUF2 appears on host PC.

Verification (Linux):

```
$ ls /media/$USER/CherryUF2/
CURRENT.UF2
```

### Copy Firmware

**Linux:**

```
$ cp rtthread.uf2 /media/$USER/CherryUF2/CURRENT.UF2
```

**Windows — Command Prompt:**

```
COPY rtthread.uf2 D:\CURRENT.UF2 /Y
```

Replace `D:` with the drive letter assigned to CherryUF2.

LED blinks during programming. Programming completes, board resets, and boots into application.

Verification: OLED displays main menu after reset.
OLED: About shows new compilation date.

---

## Updating Firmware

Repeat Step 2. UF2 bootloader does not require reinstallation.

---

## Linux — Persistent Device Names

By default, Linux assigns CDC serial ports as `/dev/ttyACM0`, `/dev/ttyACM1`, etc.
Assigned number depends on connection order and may change between sessions.

Install udev rules file from repository to create persistent symlinks:

```
$ sudo cp tools/udev/99-arm-can-tool.rules /etc/udev/rules.d/
$ sudo udevadm control -R
$ sudo udevadm trigger
```

Add user account to plugdev group:

```
$ sudo usermod -a -G plugdev $USER
```

Log out and back in for group change to take effect.

Verification: Depending upon _arm can tool_ mode, one or more symlinks listed below appear in `/dev/`.

**Table 2 — Persistent Device Symlinks**

| Symlink | Interface | Mode |
|---|---|---|
| `/dev/ttyBmpGdb` | GDB server | GDB Server |
| `/dev/ttyBmpTarg` | Target console (log output) | GDB Server, CMSIS-DAP |
| `/dev/ttyBmpSlcan` | SLCAN | CMSIS-DAP |
| `/dev/ttyBmpLua` | Lua script console | Lua Script |
| `/dev/ttyBmpUser` | Lua script user I/O | Lua Script |

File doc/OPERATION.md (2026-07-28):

# ARM CAN TOOL — Operation

## Navigate Menus

Multi-direction switch and OLED display

The OLED display and multi-direction switch form the menu system.

Multi-direction switch inputs:

- **Rotate Up** — Moves cursor to previous item. Wraps to last item if at top.
- **Rotate Down** — Moves cursor to next item. Wraps to first item if at bottom.
- **Press** — Confirms highlighted selection. Enters submenu, executes function, toggles setting, or confirms value change.

### Navigate a Menu

1. Rotate to move the highlight.
2. Press to enter submenu or activate setting.

### Adjust a Value

1. Rotate to change value.
2. Press to confirm. Device returns to parent menu.

### Return to Parent Menu

Every menu contains one or two items at the bottom:

- **Back** — Returns to previous menu. No settings changed. No action performed.
- **OK** — Applies settings or executes action. Device returns to previous menu.

Rotate to highlight Back or OK. Press to select.

### Wake from Sleep Mode

The screen turns off after a period of inactivity. This is sleep mode.

When display is sleeping:

- First rotation or press wakes the device only. Selection and values do not change.
- Second input navigates or confirms.

---

## Configure Display Settings

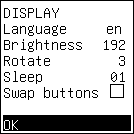
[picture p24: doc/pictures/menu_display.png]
Display menu


Display menu settings:

| Setting | Values |
|---|---|
| language | English, Chinese |
| brightness | 0–255 |
| rotate | 0–3 (0 = no rotation, 1 = 90°, 2 = 180°, 3 = 270°) |
| sleep | Inactivity in minutes before screen turns off |
| swap buttons | Swaps up and down rotation of multi-direction switch |

Brightness change applies immediately. All other settings require reboot.

Rotation and swap buttons are useful for left-handed use.

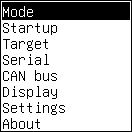
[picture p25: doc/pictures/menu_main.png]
Main menu — English
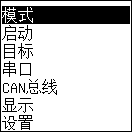
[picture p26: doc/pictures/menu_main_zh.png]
Main menu — Chinese
 

1. Navigate to Display.
2. Adjust settings.
3. Rotate to highlight OK. Press to confirm.

Device saves all settings to EEPROM and reboots.

Verification: Device boots with updated display settings.

---

## Save and Restore Settings

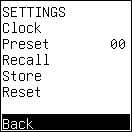
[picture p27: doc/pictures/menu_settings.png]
Settings menu


Settings changed through the menu are held in volatile memory until saved.

| Action | Behavior |
|---|---|
| Settings → Store | Saves all current settings to EEPROM. No reboot |
| Settings → Recall | Restores settings from EEPROM. Discards unsaved changes. No reboot |
| Changing Mode | Saves all settings to EEPROM. Reboots immediately |
| Confirming Display settings | Saves all settings to EEPROM. Reboots immediately |

Settings are restored from EEPROM at each boot.

The device stores up to 16 presets, numbered 0–15. Device always boots from preset 0.

### Store Settings

1. Navigate to Settings → Preset.
2. Set Preset to target slot number (0–15).
3. Navigate to Settings → Store.

Verification: Settings retained in selected preset slot after reboot.

If Preset is set to 0: settings take effect at next boot.

### Recall Settings

1. Navigate to Settings → Preset.
2. Set Preset to target slot number (0–15).
3. Navigate to Settings → Recall.

Verification: Settings loaded from selected preset slot.

---

## Reset to Factory Defaults

1. Navigate to Settings → Reset. Settings reset to default in volatile memory.
2. Navigate to Settings → Store. Default settings overwrite saved settings in EEPROM.
3. Press RESET or disconnect USB to reboot.
4. After reboot, navigate to Settings.

Verification: All values are at default.

---

## Boot with Default Settings (Recovery)

Recovery button sequence

Use this when:

- Lua autoexec script is hanging or looping.
- Display language is set to an unknown language.
- Settings struct has changed after firmware update and device behaves unexpectedly.

Booting with default settings does not overwrite saved settings. Saved settings are preserved.

Booting with default settings does not reset system clock time.

1. Rotate multi-direction switch clockwise.
2. Press RESET. Hold RESET.
3. Wait approximately 1 second. Release RESET.
4. Wait approximately 1 second. Release multi-direction switch.

Device boots with default settings.

Verification: Device operates normally. Saved settings remain unchanged on next normal boot.

---

## Set System Clock

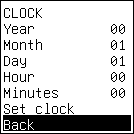
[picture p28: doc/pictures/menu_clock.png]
Clock menu


1. Navigate to Settings → Clock.
2. Set system time.

The system clock requires a CR1220 battery to persist when not connected to USB.

Verification: Clock retains correct time after power cycling.

---

## Change Operating Mode

The device operates in one of four modes. Each mode presents a different set of USB interfaces. Mode is stored in EEPROM and restored at each boot. Changing mode reboots immediately.

Navigate to Mode to view and change current mode.

| Mode | Debug Interface | CAN Interface | USB Interfaces |
|---|---|---|---|
| GDB Server | Black Magic Debug | GS-USB / SocketCAN | GS-USB bulk, CDC serial (log), CDC serial (GDB) |
| CMSIS-DAP | CMSIS-DAP v2 | SLCAN | CMSIS-DAP bulk, CDC serial (log), CDC serial (SLCAN) |
| Mass Storage | — | — | USB mass storage (SD card), CDC serial (rt-thread shell) |
| Lua Script | Lua | Lua | CDC serial (Lua shell), CDC serial (user I/O) |

Changing mode saves all settings to EEPROM and reboots immediately.

### Mass Storage Mode

Mass Storage Mode is a maintenance mode. In Mass Storage Mode, no debugging takes place, and no data is written to the SD card. Instead, Mass Storage Mode exports the SD card as a USB mass storage device, and exports the rt-thread shell as a USB CDC serial device.

Connect a terminal emulator to the CDC serial. The rt-thread `msh` shell prompt appears.

```
$ minicom -D /dev/ttyBmpCon
...
msh />ldf
Filesystem   1K-blocks      Used Available Use% Mounted on
devfs            65536         0     65536   0% /dev
part0            16384         8     16376   0% /flash
```

The `/sdcard` filesystem is not available in Mass Storage Mode, because the SD card is exported over USB.
The serial console is not available when the console is switched to USB serial.
rt-thread has only one active console device at a time.

---

## About

Navigate to About to see compilation date and free RAM.

---

## Connectors

All connectors are JST GH1.25 6-pin. Use silicone JST GH1.25 to DuPont 2.54 cables.

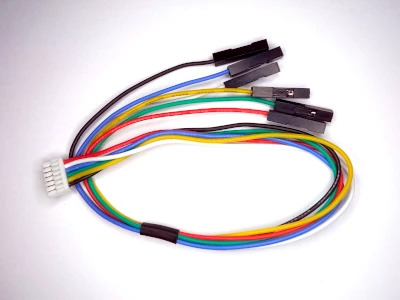
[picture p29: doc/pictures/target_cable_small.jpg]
Target cable


### ARM Connector

ARM connector connects to target SWD and target serial console.

Connect GND to target ground. Connect VIO to target logic voltage.

SWD use:

- SWCLK / SWDIO → target SWD
- TXD0 / RXD0 → target console

Set TXD0/RXD0 speed: Serial → Serial0.

To swap TXD0 and RXD0 without changing cables: Serial → Serial Enable → swap txd rxd.

JTAG use:

- TXD0 / RXD0 → TDI / TDO
- TXD1 / RXD1 → serial1 (always available)

⚠️ **Warning — serial0 in JTAG mode:** In JTAG mode, pins TXD0 and RXD0 carry TDI and TDO. Enabling serial0 in JTAG mode causes driver conflict. Do not enable serial0 in JTAG mode: Serial → Serial Enable → serial0 → Off.

### AUX Connector

AUX connector contains:

- serial1: TXD1, RXD1
- serial2: RXD2 (receive only)
- target reset: NRST (resets target)

Serial2 is receive only. Use for SWO or as serial port logger.

### SWO Decode

1. Connect target SWO pin to AUX connector pin 4.
2. Set speed: Serial → serial2 speed.
3. Enable serial2: Serial → Serial Enable → serial2 → On.
4. Connect terminal emulator to `/dev/ttyBmpTarg` (CDC serial 0).

Verification: With target running, decoded SWO output appears in terminal emulator.

### SWD Connector

SWD connector is used to debug the debugger. Connect another debugger to the AT32F405 processor via this port.

rt-thread console is on TXD/RXD pins. Baud rate: 115200 bit/s.

### CAN Connector

CAN connector is electrically isolated from the rest of the device.

Connect ISO GND to CANBUS ground, even when CANBUS ground is target ground.

The device has no internal 120 Ω terminating resistors. If used as end node: add a 120 Ω resistor between HIGH and LOW using a JST GH1.25 to DuPont 2.54 cable.

### I2C Connector

I2C connector operates in two configurations:

- Two independent I2C buses: I2C1 and I2C3
- One I2C bus (I2C1) and two GPIO pins (e.g., ALERT and I2C_RST)

Bus I2C1 contains two devices:

- Settings EEPROM: address 0x50
- RTC: address 0x68

Bus I2C3 is free.

### External Trigger Input

External trigger halts the target when pin PC1 is pulled low. With external trigger enabled and target running, pulling pin PC1 low is the same as typing Ctrl-C at the GDB prompt.

PC1 is I2C3_SDA on the I2C connector.

⚠️ **Note — I2C3 unavailable:** When external trigger is enabled, I2C3 is not available.

Enable external trigger:

1. Navigate to Startup → trigger → On.
2. Navigate to Settings → Store.
3. Reboot.

Verification: External trigger halts target when PC1 is pulled low.

---

## Breakpoint On Overcurrent

Target current measurement

Use [INA228 I2C Power Monitor](https://learn.adafruit.com/adafruit-ina228-i2c-power-monitor/) to measure target current. Connect INA228 ALERT output to external trigger input. Use external trigger to trigger breakpoint when target current exceeds preset value.

## USB Serial Data

### Output: Tool to PC (CDC0 and CDC1)

In GDB Server mode:

| Port | Data |
|---|---|
| CDC0 | serial0–2, RTT, SWO, memwatch, CAN bus logging |
| CDC1 | GDB server |

CDC0 is tuned for output with more transmit buffers than CDC1.

### Input: PC to Tool

Characters typed in a terminal emulator connected to CDC0 (`ttyBmpTarg`) are sent to the device selected in Serial → usb out.

Options for Serial → usb out:

- serial0
- serial1
- rtt

---

## Enable Target Power

⚠️ **Warning — power contention:** Enabling 3.3 V Power when target has an independent supply causes both sources to contend on VIO. Will cause damage to target or device. Enable 3.3 V Power only when target has no independent supply on VIO.

### Enable via Menu

1. Navigate to Target → 3.3V Power → On.
2. Navigate to Settings → Store.

Verification: 3.3 V present on VIO pin when target is connected.

### Enable via GDB

```
(gdb) monitor tpwr enable
```

### Disable via GDB

```
(gdb) monitor tpwr disable
```

If target is powered externally: VIO is used to configure logic translators only.

---

## Enable Watchdog

Watchdog reboots the device if system becomes unresponsive. Timeout: 20 seconds.

1. Navigate to Startup → Watchdog → On.
2. Navigate to Settings → Store.
3. Reboot.

Verification: Watchdog shown as enabled in Startup menu after reboot.

---

## Configure Startup Services

Startup services initialize automatically at boot when enabled.

| Service | Description |
|---|---|
| CAN bus | Enables CAN bus interface at boot. Otherwise, CAN bus is enabled when the host opens gs_usb or SLCAN. |
| debugger | Connects to processor on SWD bus. Same as `monitor swd_scan` then `attach 1` |
| memwatch | Enables variable watchpoints as configured using `mon memwatch` |
| lua autoexec | Executes Lua autoexec script from internal flash at boot |
| logging | Enables SD card logging of all active output channels |
| rtt | Activates RTT output. Same as `monitor rtt` |
| swo | Activates SWO decode. Same as enabling SWO decode in the Debug menu |
| watchdog | Enables 20-second watchdog timer |
| trigger | Enables external trigger on I2C connector pin I2C3_SDA |

1. Navigate to Startup.
2. Enable or disable required services.
3. Navigate to Settings → Store.
4. Reboot.

Verification: Enabled services are active after reboot.

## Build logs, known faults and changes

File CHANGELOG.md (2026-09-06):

# Changelog

## V1.4 - 2026-09-06

- New: lua timer
- sfud: wait for WEL
- jtag: off-by-one

## V1.3 - 2026-08-30

- New: Black Magic Debug updated to v2.1.0
- New: GDB NoAckMode advertised by default
- Changed: Docker build runs as non-root user

## V1.2 - 2026-08-26

- New: ARM MTB (Micro Trace Buffer) instruction trace (`mon mtb`, `tools/mtb/mtb.py`)

## V1.1 - 2026-08-08

- New: ARM DWT program counter and exception trace (`swo top` / `swo graph`)
- Fix: AT32 SPI driver busy-waited on DMA transfer completion

## V1.0 - 2026-07-17

Initial release.

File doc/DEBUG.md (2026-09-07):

# ARM CAN TOOL — Debug Guide

Debug workflows, memwatch, RTT, SWO for ARM and CAN bus targets.

For initial setup (firmware verification, factory reset, display orientation, target power): See [OPERATION](OPERATION.md).

For a complete first-session walkthrough: See [TUTORIAL](TUTORIAL.md).

---

## Choosing a Mode

- Mode → GDB Server runs Black Magic Debug directly on the probe.
- Mode → CMSIS-DAP hands off to an intermediary — OpenOCD, BMDA, or pyOCD — running on the PC.

Switching between Black Magic Debug and OpenOCD is a menu setting, not a wiring change — both modes use the same SWD/JTAG connection to the target.

---

## GDB Server Mode — Black Magic Debug

In GDB Server mode, the probe runs Black Magic Debug firmware and exposes a GDB server as a USB serial port. `arm-none-eabi-gdb` connects directly to the probe. No intermediary software runs on the PC.

The probe also exposes the CAN bus as GS-USB / SocketCAN.

1. Navigate to Mode → GDB Server. Device reboots.

2. Start GDB and connect to the probe:

```
$ arm-none-eabi-gdb
(gdb) target extended-remote /dev/ttyBmpGdb
```

Device path `/dev/ttyBmpGdb` requires udev rules (See INSTALL.md). Without udev rules: `/dev/ttyACMx`

| OS | Device path |
|---|---|
| Linux | `/dev/ttyACMx` — the second of the two ttyACMx ports ARM CAN Tool exposes |
| Windows | COM port assigned to GDB server interface |
| macOS | `/dev/cu.usbmodemXXXX` |

3. Scan for targets:

```
(gdb) monitor swd_scan
```

Expected output:

```
Target voltage: 3.325V
Available Targets:
No. Att Driver
 1      STM32F1  L/M density M3
```

If `Target voltage: 0.000V`:

- Target is not powered
- If target is powered: VIO is not connected.
- If probe supplies target power: Target → 3.3V Power is not set.

4. Attach, load firmware, and run:

```
(gdb) attach 1
(gdb) file firmware.elf
(gdb) load
(gdb) run
```

**Verification:** GDB reports `Attaching to Remote target`. Target executes loaded firmware.

The `monitor` prefix sends commands to Black Magic Debug firmware on the probe.

---

## CMSIS-DAP Mode — Intermediary Required

In CMSIS-DAP mode, the probe exposes a CMSIS-DAP interface. `arm-none-eabi-gdb` does not connect directly to the probe — an intermediary program runs on the PC between GDB and the probe:

```
arm-none-eabi-gdb → intermediary (PC) → ARM CAN Tool (CMSIS-DAP)
```

The probe also exposes the CAN bus as SLCAN.

Three intermediaries are supported:

### OpenOCD

1. Navigate to Mode → CMSIS-DAP. Device reboots.

2. In a first terminal, start OpenOCD:

```
$ openocd -f interface/cmsis-dap.cfg -f target/stm32f1x.cfg
```

3. In a second terminal, start GDB and connect to OpenOCD:

```
$ arm-none-eabi-gdb
(gdb) target extended-remote :3333
(gdb) file ~/firmware/build/firmware.elf
(gdb) load
(gdb) run
```

**Verification:** OpenOCD reports `Listening on port 3333 for gdb connections`. GDB connects and target executes loaded firmware.

Prebuilt OpenOCD binaries: [xPack project](https://xpack-dev-tools.github.io/openocd-xpack/).

### Black Magic Debug App (BMDA)

BMDA is the hosted (PC-side) version of Black Magic Debug. See [codeberg.org/blackmagic-debug/blackmagic](https://codeberg.org/blackmagic-debug/blackmagic).

1. Navigate to Mode → CMSIS-DAP. Device reboots.

2. In a first terminal, start BMDA:

```
$ blackmagic
Listening on TCP port: 2000
```

Use `-v 3` to confirm ARM CAN Tool is detected:

```
$ blackmagic -v 3
Black Magic Debug App v2.0.0-rc1-4-gab6d92e8
 for Black Magic Probe, ST-Link v2 and v3, CMSIS-DAP, J-Link and FTDI (MPSSE)
Using 1209:8816 338472C52178 open hardware
 arm can tool (CMSIS-DAP/slcan) ---
Using bulk transfer
CMSIS-DAP v2.0.0, Capabilities: 03 (JTAG/SWD)
Adaptor supports DAP SWD sequences
Setting V6ONLY to off for dual stack listening.
Listening on TCP port: 2000
```

`1209:8816` is the VID:PID of ARM CAN Tool. `arm can tool (CMSIS-DAP/slcan)` confirms the probe is detected.

3. In a second terminal, start GDB and connect to BMDA:

```
$ arm-none-eabi-gdb
(gdb) target extended-remote :2000
(gdb) file ~/firmware/build/firmware.elf
(gdb) load
(gdb) run
```

**Verification:** BMDA reports `Listening on TCP port: 2000`. GDB connects and target executes loaded firmware.

### pyOCD

See [pyocd.io](https://pyocd.io).

1. Navigate to Mode → CMSIS-DAP. Device reboots.

2. In a first terminal, start pyOCD gdbserver:

```
$ pyocd gdbserver
```

3. In a second terminal, start GDB and connect to pyOCD:

```
$ arm-none-eabi-gdb
(gdb) target extended-remote localhost:3333
(gdb) file ~/firmware/build/firmware.elf
(gdb) load
(gdb) run
```

**Verification:** pyOCD reports GDB server listening on port 3333. GDB connects and target executes loaded firmware.

---

## Target Reset

AUX connector pin 5 (NRST) provides target reset.

Some processors require reset asserted during SWD or JTAG connection.

Manual reset: Press target reset button briefly while initiating debugger connection.

Automated reset via NRST: Connect AUX connector pin 5 to target reset line, then configure debugger.

For Black Magic Debug (GDB Server mode) and BMDA (CMSIS-DAP mode):

```
(gdb) monitor connect_rst enable
```

For OpenOCD:

```
reset_config srst_only srst_push_pull connect_assert_srst
```

---

## Memwatch — Live Memory Monitoring

Memwatch reads target memory while target is running, without halting execution. Available in GDB Server mode only, on ARM Cortex-M targets.

Up to 8 addresses monitored simultaneously. Output appears on CDC serial 0.

Useful for observing variables in hard real-time systems where halting alters behaviour.

### Command Syntax

```
(gdb) mon memwatch [/t] [[NAME] [/d|/u|/f[N]|/x] ADDRESS]...
(gdb) mon memwatch status
(gdb) mon memwatch
```

| Argument | Description |
|---|---|
| NAME | Optional label printed on each output line. Must begin with a letter |
| /d | Signed 32-bit integer |
| /u | Unsigned 32-bit integer |
| /f | IEEE 754 32-bit float, 6 decimal places |
| /fN | IEEE 754 32-bit float, N decimal places |
| /x | Hexadecimal 32-bit integer (default) |
| /t | Prefix each line with timestamp in milliseconds |
| status | Display current watchpoint configuration |
| (no arguments) | Disable all watchpoints |

### Single Variable

```
(gdb) p &counter
$1 = (<data variable, no debug info> *) 0x20000224 <counter>
(gdb) mon memwatch counter /d 0x20000224
(gdb) run
```

Output on CDC serial 0:

```
counter 0
counter 1
counter 2
```

### Multiple Variables with Timestamp

```
(gdb) mon memwatch /t counter /d 0x20000224 root /f4 0x20000248
```

Output:

```
20601 counter 0
20601 root 0.0000
20613 counter 1
20613 root 1.0000
21613 counter 2
21613 root 1.4142
```

---

## RTT

Real-Time Transfer (RTT) reads debug output from target RTT control block in memory while target is running.

RTT output destination depends on mode:

| Mode | RTT output |
|---|---|
| GDB Server | CDC serial 0 |
| Lua Script | CDC serial 0 |
| CMSIS-DAP / BMDA | BMDA stdout |

Enable RTT:

```
(gdb) monitor rtt enable
```

**Verification:**

```
(gdb) mon rtt stat
rtt: on found: yes ident: off halt: off channels: auto
max poll ms: 256 min poll ms: 8 max errs: 10
```

### Halt Control

On most targets, RTT control block is read without halting target. On some targets this is not possible.

| Command | Behaviour |
|---|---|
| `mon rtt halt enable` | Always halt target during RTT reads |
| `mon rtt halt disable` | Never halt target during RTT reads |
| `mon rtt halt auto` | Default. Halt only where required |

Many RTT connection problems are caused by CPU cache configuration, not by halt setting.

### Slow RTT Connection

If RTT is slow to connect, specify RTT control block address explicitly using GDB scripts. These scripts require `arm-none-eabi-gdb-py3`:

- `tools/rtt/rtt.bmd` — Black Magic Debug
- `tools/rtt/rtt.openocd` — OpenOCD

---

## SWO

SWO (Serial Wire Output) data arrives on serial2 via AUX connector pin 4. Receive only.

SWO is a direct hardware connection from target SWO pin to probe RXD2. It operates independently of the debug interface mode (GDB Server or CMSIS-DAP).

SWO requires Arm ITM. ITM is present on Cortex-M3, M4, M33, and others. ITM is not present on Cortex-M0.

1. Connect target SWO pin to AUX connector pin 4.
2. Set speed: Serial → serial2 speed.
3. Enable SWO decode: Startup → swo decode → On.
4. Enable serial2: Serial → Serial Enable → serial2 → On.
5. Connect terminal emulator to `/dev/ttyBmpTarg` (CDC serial 0).

**Verification:** Decoded SWO output appears in terminal emulator.

Arm ITM uses 32 software channels (0-31) for application debug output, selected with `decode`.

In gdb server:
To switch swo on, serial port speed 1000000, swo channels 1 and 3:

```
(gdb) mon swo enable 1000000 decode 1 3
Channel mask: 00000000000000000000000000001010
```

to switch swo off:

```
(gdb) mon swo disable
Trace disabled
```

---

## DWT

DWT (Data Watchpoint and Trace) prints

- PC (program counter) samples
- exceptions
- data watchpoints
- timestamps

of a running target.

DWT trace and ITM printing use the same SWO output pin.
Because the SWO clock is slower than the MCU clock, it is not possible to send the program counter of every instruction.
Instead, the program counter is sampled. Use the program counter samples for statistical analysis, to see where the MCU spends most of its time.

DWT hardware trace packets (PC samples, exceptions, data watchpoints, timestamps) are separate from ITM packets. DWT trace packets are decoded, regardless of which channels `mon swo decode` selects.

DWT packets are sent over the same output pin as SWO.
Therefore, SWO must be enabled before you can see any DWT output.
First set up SWO, then set up DWT.

- `mon swo` to set up how ARM Can Tool prints.
- `mon dwt` to set up what the target sends.

### monitor swo

`mon swo` configures ARM CAN Tool how to print.

```
(gdb) mon swo [enable [BAUDRATE] [decode [CHANNEL_NR ...]]|disable|log|[top|graph] <low_addr> <high_addr> <bucket_bits> <interval_seconds>|selftest]
```

| Option | Meaning |
| --- | --- |
| enable | switch ITM decoding on |
| disable | switch ITM decoding off |
| BAUDRATE | speed of the serial port |
| decode [CHANNEL_NR ...] | ITM channels to show |
| log | log individual PC trace packets (default)|
| top <low\_addr> <high\_addr> <bucket\_bits> <interval\_seconds> | PC trace histogram, text format |
| graph <low\_addr> <high\_addr> <bucket\_bits> <interval\_seconds> | PC trace histogram, ANSI terminal |
| selftest | test SWO with known good packets |

The SWO speed is a few megabit/s, and depends on the length of the wire.

| Speed | Comment |
| --- | --- |
| 1 Mbit/s | safe |
| 2 to 2.5 Mbit/s | typical |
| 6.75 Mbit/s | ARM CAN Tool maximum |

When printing over SWO, a channel number has to be specified. Using different channel numbers for different subsystems allows separate logs for separate subsystems without recompiling.

For `top` and `graph`, the command shows

- the 25 most used PC addresses
- between `low_addr` and `high_addr`
- in groups of 2**`bucket_bits`
- every `interval_seconds`.

`top` outputs for logfiles, `graph` outputs for ansi terminal.

Example: 32 kbyte of code, beginning at 0x08000000, in blocks of 512 bytes (9 bit), displaying statistics every every 5 seconds:

```
(gdb) mon swo top 0x08000000 0x08008000 9 5
```

### monitor dwt

`mon dwt` configures the target what to send.

```
(gdb) mon dwt [enable|disable|status|clear|0..31|exception|lts <0..3>|gts <0..3>|timestamp]...
```

| Option | Meaning |
| --- | --- |
| enable | switch DWT trace on |
| disable | switch DWT trace off |
| status | show target DWT registers |
| clear | switch PC, exception, timestamp trace off |
| 0..31 | switch PC trace on, 0 = slowest, 31 = fastest |
| exception | switch exception trace on |
| lts 0..3 | local timestamp clock |
| gts 0..3 | global timestamp source |
| timestamp | switch timestamp trace on |

The slowest PC trace is 1 sample every 16384 cycles, the fastest 1 sample every 64 cycles.
If the number of samples is too high for the SWO speed, some packets will be dropped, and the log shows overflow ("OVF").
For a typical Cortex-M4, `mon dwt enable <rate>` where rate >= 15 requests PC samples faster than the link can carry, and samples are dropped.

### Example

```
$ arm-none-eabi-gdb
(gdb) target extended /dev/ttyBmpGdb
(gdb) monitor swd_scan
Target voltage: 3.326V
Available Targets:
No. Att Driver
 1      STM32F412 M4
```

**Verification:** gdb lists target

```
(gdb) attach 1
(gdb) file ~/Arduino/FiveWay/build/FiveWay.ino.elf
Reading symbols from ~/Arduino/FiveWay/build/FiveWay.ino.elf...
(gdb) load
(gdb) compare-sections
```

**Verification:** gdb outputs: "Section ... matched", firmware flashed ok.

```
(gdb) monitor swo enable 1000000 decode
Channel mask: 11111111111111111111111111111111
(gdb) monitor swo log
(gdb) break main
```

**Verification:** gdb outputs: "Breakpoint ... at ..."

The `mon dwt` command is only available if the processor is Cortex-M, and after `attach`.

```
(gdb) run
Breakpoint 1, main () at ...
(gdb) mon dwt enable 0
(gdb) mon dwt status
DWT_CTRL: 0x400013ff
PC sampling on
ITM_TCR: 0x00000019
trace forwarding to SWO: on

```

**Verification:** gdb outputs include the lines "PC sampling on" and "trace forwarding to SWO: on".

Open a terminal window on /dev/ttyBmpTarg:

```
minicom -D /dev/ttyBmpTarg
```

Continue the target program:

```
(gdb) continue
Continuing.
```

**Verification:** /dev/ttyBmpTarg outputs swo text and program counter trace:

```
serial: 1
swo: 1
PC:0x080054CA
PC:0x08001798
PC:0x080054BC
PC:0x080054BC
PC:0x08003AD6
PC:0x08003AD6
...
```

The output is suitable for saving and postprocessing on pc. Example of postprocessing: Look up function at address.

```
$  arm-none-eabi-addr2line -sfe ~/Arduino/FiveWay/build/FiveWay.ino.elf 0x080054BC 0x08003AD6
delay
wiring_time.c:43 (discriminator 1)
getCurrentMillis
clock.c:52
```
Interrupt the program with ctrl-c, and change DWT output format:

```
Program received signal SIGINT, Interrupt.
(gdb) mon swo top 0x08000000 0x08008000 9 5
(gdb) continue
Continuing.
```

/dev/ttyBmpTarg now outputs PC addresses from 0x08000000 to 0x08008000 only, sorted in blocks of 512byte (9 bit), every 5 seconds:

```
serial: 5
swo: 5
serial: 6
swo: 6
12375 0x08005400
11345 0x08003A00
 6168 0x08001600
    1 0x08000000
```

The output is suitable for logging to SD card.

Each line represents a PC address range of 512 bytes. E.g. 0x08000000 represents addresses from 0x08000000 to 0x080001ff. To set up smaller ranges, e.g. 256 bytes:

```
(gdb) mon swo top 0x08000000 0x08008000 8 5
```

The total number of ranges is limited to 4096: `(high_addr - low_addr)/2**bucket_bits <= 4096`.

Stop target program, and choose output format for ansi terminal:

```
ctrl-c
Program received signal SIGINT, Interrupt.
(gdb) mon swo graph 0x08000000 0x08008000 9 5
(gdb) continue
Continuing.
```

**Verification:** Graph of PC samples

```
   12348   0x08005400                                    █
   11344   0x08003A00                        █
    6191   0x08001600       █
       1   0x08003200                    █
       1   0x08000000   █
serial: 57
swo: 57
serial: 58
swo: 58
...
```

In this graph, the vertical axis is increasing number of samples, the horizontal axis is program counter.

The output is suitable for seeing target status at a glance.

Stop target program, and add tracing exceptions:

```
^C
Program received signal SIGINT, Interrupt.
(gdb) mon dwt enable 0 exception
(gdb) continue
Continuing.
```

The terminal now shows:

```
12309 0x08005400                                        █
11299 0x08003A00                            █
 6171 0x08001600           █
   80 0x08002000               █
 5096 SysTick
   30 IRQ 37
OVERFLOW
serial: 29
swo: 29
serial: 30
swo: 30
serial: 31
swo: 31
```

This display contains:

- PC activity
- exceptions (here: SysTick and interrupt 37)
- OVERFLOW: some packets have been dropped because SWO was too slow.
- console output (serial: ) and SWO output (swo: )

The `mon dwt` command is convenient, but not necessary: a target can also set it's own DWT register from code.

`Settings->Save` also saves SWO settings.
If `Startup->swo` is configured, the SWO settings are restored at startup.
Decoding SWO does not require an SWD connection.

---

## MTB

Micro Trace Buffer (MTB) is a branch/exception trace, not a program counter trace. When program execution is not sequential, two addresses are logged to a circular buffer in ram: the address the program jumped from and the address the program jumped to. Program execution between two log entries is linear.

The `mon mtb` command is available in gdb server mode, and only when attached to Cortex-M target.

Unlike DWT/SWO, MTB needs no SWO wire. MTB only uses the SWD/JTAG debug connection.

MTB is an optional component for Cortex-M0+, Cortex-M23, Cortex-M33 and STAR-MC1.

`mon mtb` does not switch MTB on. The target program allocates a trace buffer in ram and switches MTB on.

### Target Program

Before writing the target program, attach with `arm-none-eabi-gdb` and type `mon mtb status`. If a target has no MTB, `mon mtb status` prints `no mtb`. Type `mon mtb size` to show maximum buffer size.

Example: SAMD21.

```
(gdb) mon mtb status
trace: off halt request: off wrapped: no autostop: off autohalt: off
buffer: 0x20007c00 - 0x20007fff (1024 bytes) watermark: 0x20007fc8
mtb base: 0x41006000 sram base: 0x20000000
mtb master: 0x00000006 position: 0x00007f90 flow: 0x00007fc8
(gdb) mon mtb size
max buffer size: 32768 bytes
```

Output shows:

- target has MTB
- MTB registers are at `mtb base: 0x41006000`
- MTB trace buffer is at or after `sram base: 0x20000000`
- maximum MTB trace buffer is 32 kbyte.

These data are necessary and sufficient to configure MTB. The target program then:

1. Reserves a buffer of 2^n bytes, aligned to its own size, at or after `sram base`. Typical size: from 512 bytes to 2k.
2. Writes buffer address minus "sram base" to register MTB POSITION.
3. Writes buffer size and enable bit to register MTB MASTER.

Use the pattern in target program [MTB.ino](../tools/Arduino/MTB/MTB.ino).

### monitor mtb

```
(gdb) mon mtb [status|dump|size]
```

| Option | Meaning |
| --- | --- |
| status | print MTB registers, buffer address and size |
| dump | print trace buffer in hex, oldest jump first |
| size | print the largest buffer MTB can address |

`mon mtb status` and `mon mtb dump` are read-only.

`mon mtb size` writes MTB registers, then restores the registers to the original value. Maximum size printed is maximum size MTB can address, not ram size.

`mon mtb dump` prints the trace buffer, one line per jump.
First hex number is the address the program jumped from. Second hex number is the address the program jumped to.
Example:

```
- 0x00000122 - 0x00000108
```

| Flag | Meaning |
| --- | --- |
| `-` | none |
| `A` | first address is an exception return address |
| `S` | trace started or restarted at second address |

If autostop is set, tracing stops when the trace buffer reaches the watermark.
If autohalt is set, target enters a breakpoint when the trace buffer reaches the watermark.
If autostop is not set and autohalt is not set, watermark is stored but unused, and the buffer wraps normally.

### gdb mtb.py script

The gdb script `tools/mtb/mtb.py` adds an `mtb` command to gdb.
Where `mon mtb dump` prints addresses in hex, `mtb` prints function name, file and line number. Repeated jumps are printed once, with a count. Script `mtb.py` requires gdb with python3 support `arm-none-eabi-gdb-py3`.

```
(gdb) set pagination off
(gdb) source tools/mtb/mtb.py
(gdb) mtb
```

### Example

Target program `tools/Arduino/MTB` switches MTB on and solves Towers of Hanoi. Moves are printed on Serial1.

Compile for SAMD21:

```
$ arduino-cli compile --fqbn arduino:samd:arduino_zero_native \
    --build-property "build.ldscript=linker_scripts/gcc/flash_without_bootloader.ld" \
    --export-binaries tools/Arduino/MTB
```

Flash:

```
$ arm-none-eabi-gdb-py3
(gdb) target extended-remote /dev/ttyBmpGdb
Remote debugging using /dev/ttyBmpGdb
(gdb) mon swd_scan
Target voltage: 3.336V
Available Targets:
No. Att Driver
 1      Atmel SAMD21G18A (rev D) M0+
(gdb) attach 1
(gdb) file tools/Arduino/MTB/build/arduino.samd.arduino_zero_native/MTB.ino.elf
Reading symbols from tools/Arduino/MTB/build/arduino.samd.arduino_zero_native/MTB.ino.elf...
(gdb) load
(gdb) compare-sections
Section .text, range 0x0 -- 0x2ec4: matched.
Section .data, range 0x2ec4 -- 0x2f54: matched.
```

**Verification:** gdb outputs: "Section ... matched", firmware flashed ok.

Breakpoint at the deepest level of the recursion:

```
(gdb) break hanoi if n == 0
Breakpoint 1 at 0x108: file tools/Arduino/MTB/MTB.ino, line 90.
(gdb) run
Breakpoint 1, hanoi (n=n@entry=0, from=from@entry=1, to=to@entry=3, via=via@entry=2)
    at tools/Arduino/MTB/MTB.ino:90
90	void hanoi(int n, int from, int to, int via) {
(gdb) mon mtb status
trace: on halt request: off wrapped: no autostop: off autohalt: off
buffer: 0x20000800 - 0x20000bff (1024 bytes) watermark: 0x20000000
mtb base: 0x41006000 sram base: 0x20000000
mtb master: 0x80000006 position: 0x00000838 flow: 0x00000000
```

**Verification:** gdb stops in `hanoi` with `n=0`. `mon mtb status` outputs "trace: on". "mtb base:" is the address of the MTB registers, `MTB_SFR_BASE` in `MTB.ino`.

Print the trace:

```
(gdb) mon mtb dump
- 0x000001cc S 0x00000bc2
- 0x00000bc2 - 0x0000017c
- 0x00000186 - 0x00000108
- 0x00000122 - 0x00000108
- 0x00000122 - 0x00000108
- 0x00000122 - 0x00000108
- 0x00000122 - 0x00000108
```

Print the trace with symbols:

```
(gdb) set pagination off
(gdb) source tools/mtb/mtb.py
(gdb) mtb
- 0x000001cc setup() at MTB.ino:105                   -> S 0x00000bc2 main() at main.cpp:53
- 0x00000bc2 main() at main.cpp:53                    -> - 0x0000017c loop() at MTB.ino:107
- 0x00000186 loop() at MTB.ino:108                    -> - 0x00000108 hanoi(int, int, int, int) at MTB.ino:90
- 0x00000122 hanoi(int, int, int, int) at MTB.ino:92  -> - 0x00000108 hanoi(int, int, int, int) at MTB.ino:90  (4 times)
```

This trace contains:

- `S`: trace started when `setup()` switched MTB on. First jump recorded is `setup()` returning to `main()`.
- `main()` calling `loop()`
- `loop()` calling `hanoi()`.
- `hanoi()` calling itself 4 times, down to `n=0`.

Addresses without symbols print as `??`: exception return values (0xFFFFFFF1 - 0xFFFFFFFD), and code compiled without debug information.

Note the target program switches MTB off in the fault handler `HardFault_Handler()`, else the trace buffer fills up with `while (true) {}`.

---

## Semihosting

Using semihosting a target program can write to stdout, read from stdin, and do basic file input/output.

To enable semihosting, compile the target with a library that implements semihosting:

```
arm-none-eabi-gcc ... --specs=rdimon.specs -lrdimon
```

For each semihosting system call, the target halts, the debugger completes the semihosting system call, and the target continues program execution.

⚠️ **Warning — always run a semihosting program with a debugger:** Without debugger, the target waits forever.

Where semihosting calls are serviced depends upon arm can tool mode:

| Semihosting | GDB Server mode | CMSIS-DAP mode |
| --- | --- | --- |
| runs on | arm can tool | pc |
| file read/write | sdcard or flash | pc filesystem |
| stdout, stderr  | usb serial and sdcard log | pc terminal |
| stdin | always EOF | pc terminal |
| time() | arm can tool RTC | pc clock |
| system() | rt-thread msh shell | pc shell command |
| runs without pc | yes | no |

⚠️ **Warning — security:** In GDB Server mode, a semihosting program can read or overwrite files on the SD card or in SPI flash, execute rt-thread console commands, and modify arm can tool settings. In CMSIS-DAP mode, a semihosting program can read or overwrite any file, and execute any program, on the PC.

### CMSIS-DAP Mode

Using arm can tool in CMSIS-DAP mode, together with [OpenOCD](https://xpack-dev-tools.github.io/openocd-xpack/docs/user/#using-openocd-in-testing) on PC. Files are created on the PC where OpenOCD runs. stdin, stdout and stderr connect to the OpenOCD console. `time()` returns pc time. `system()` runs a shell command on the pc. See OpenOCD [arm semihosting](https://openocd.org/doc/html/Architecture-and-Core-Commands.html) commands.

**Example:**

Set arm can tool in CMSIS-DAP mode. Start openocd.

```
./bin/openocd -f openocd/scripts/interface/cmsis-dap.cfg -f openocd/scripts/target/stm32f4x.cfg  -c "init" -c "arm semihosting enable"
...
Info : [stm32f4x.cpu] Cortex-M4 r0p1 processor detected
Info : Listening on port 3333 for gdb connections
semihosting is enabled
```

Using arduino, compile and run `tools/Arduino/Hello`. Open a gdb session in another window:

```
$ arm-none-eabi-gdb
(gdb) tar ext :3333
Remote debugging using :3333
(gdb) file ~/Arduino/Hello/build/STMicroelectronics.stm32.GenF4/Hello.ino.elf
(gdb) lo
(gdb) compare-sections
(gdb) r
Starting program:
```

**Verification:** `Hello from ARM CAN Tool!` appears in the window where openocd runs.

⚠️ **Warning — security:** Only enable semihosting for trusted programs. When enabled, a target program can open any file and execute any program on the PC.

### GDB Server Mode

In gdb server mode, arm can tool executes semihosting calls.

Always enabled are terminal output (writec, write0) and time (clock, time, elapsed). stdout and stderr are written to usb serial cdc0 `/dev/ttyBmpTarg`, and to sd card if `Startup->logging` is enabled. stdin always returns EOF.

File input/output is disabled by default. To enable, switch on `Target -> file i/o`. Filesystems are `/sdcard` for sdcard, `/flash` for 16 Mbyte SPI flash. Working directory is sdcard.

|filename|file system|
|---|---|
|/sdcard/output.csv|sdcard |
|/flash/output.csv|SPI flash |
|output.csv|sdcard (same as /sdcard/output.csv)|

⚠️ **Warning — security:** Only enable file i/o for trusted programs. File paths are not confined to a working directory. When enabled, a target program can open any file on the arm can tool.

System commands are disabled by default. To enable, switch on `Target -> shell command`. Commands are executed using rt-thread msh. Example: system("sync").

⚠️ **Warning — security:** Only enable shell command for trusted programs. When enabled, a target program can execute any rt-thread console command.

**Example:**

Set arm can tool in gdb server mode. Connect a terminal emulator to `/dev/ttyBmpTarg`.

Using arduino, compile and run `tools/Arduino/Hello`:

```
 $ arm-none-eabi-gdb
(gdb) tar ext /dev/ttyBmpGdb
Remote debugging using /dev/ttyBmpGdb
(gdb) mon swd
Target voltage: 3.336V
Available Targets:
No. Att Driver
 1      STM32F412 M4
(gdb) at 1
(gdb) file ~/Arduino/Hello/build/STMicroelectronics.stm32.GenF4/Hello.ino.elf
(gdb) lo
(gdb) compare-sections
(gdb) r
Starting program:
```

**Verification:** `Hello from ARM CAN Tool!` appears on `/dev/ttyBmpTarg`.

---

## Online Book

A practical guide to Black Magic Debug:
[Black Magic Debug Book](https://github.com/compuphase/Black-Magic-Probe-Book/releases)

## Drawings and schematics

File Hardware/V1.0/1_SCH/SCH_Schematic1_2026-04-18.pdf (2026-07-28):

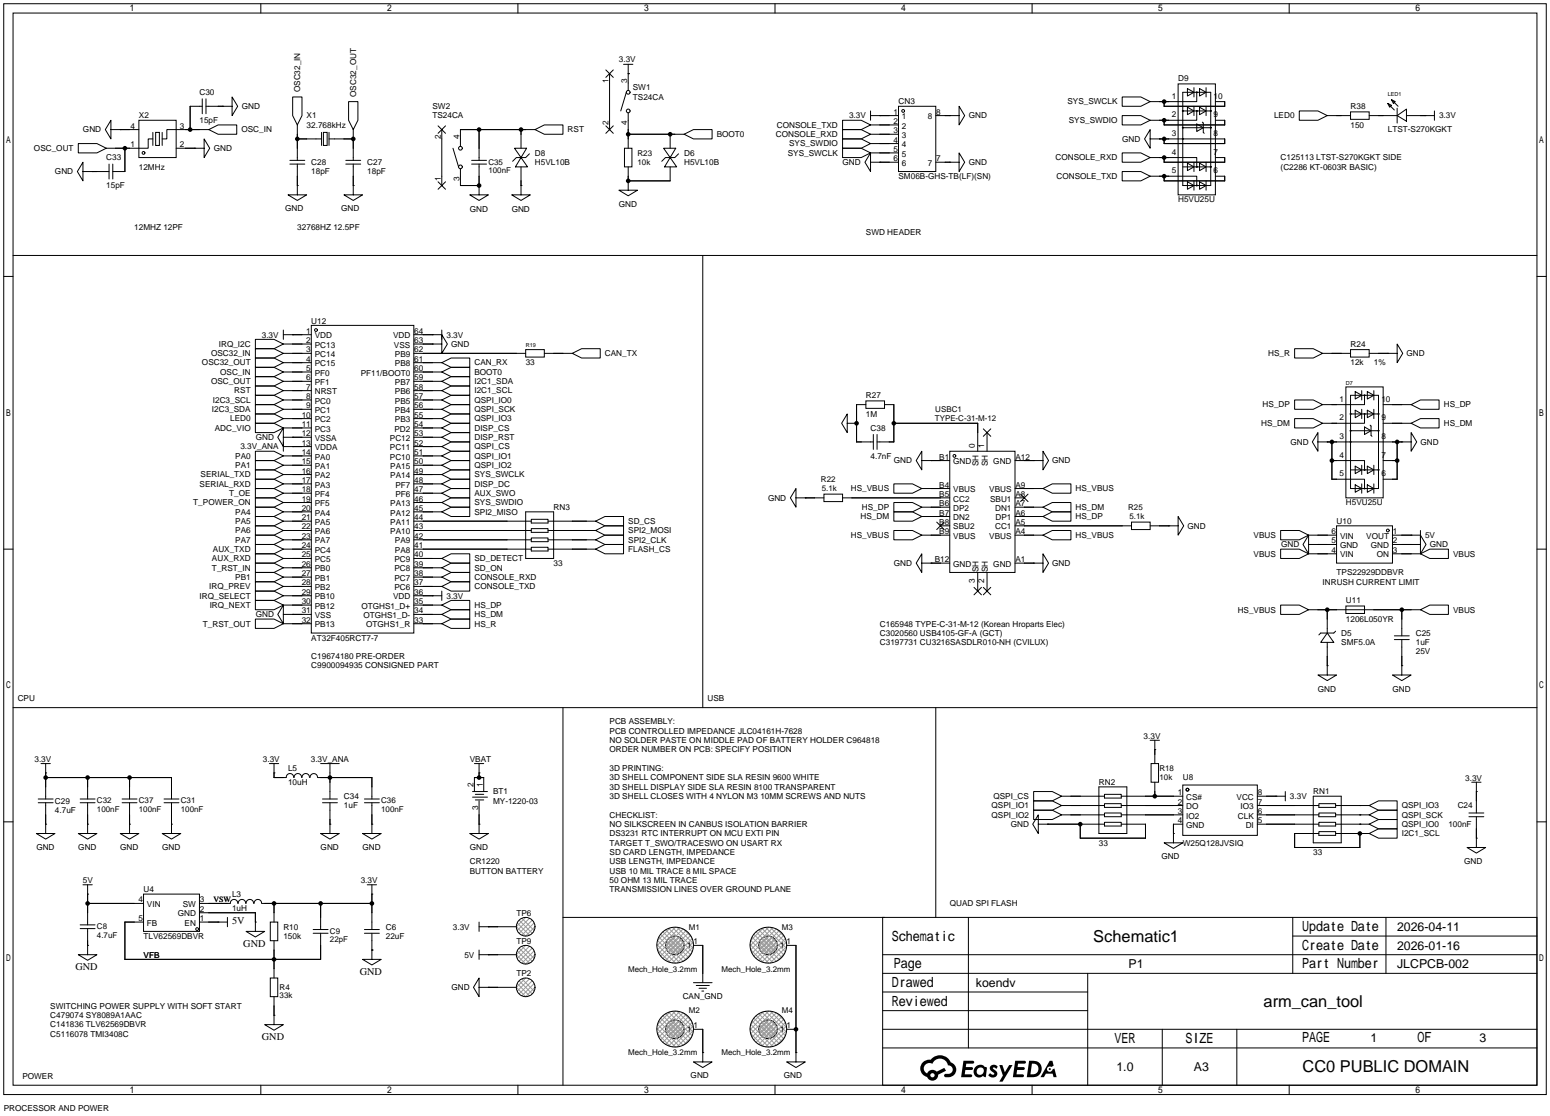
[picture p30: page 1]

SM06B-GHS-TB(LF)(SN)

C165948 TYPE-C-31-M-12 (Korean Hroparts Elec)
C3020560 USB4105-GF-A (GCT)
C3197731 CU3216SASDLR010-NH (CVILUX)

PCB ASSEMBLY:
PCB CONTROLLED IMPEDANCE JLC04161H-7628
NO SOLDER PASTE ON MIDDLE PAD OF BATTERY HOLDER C964818
ORDER NUMBER ON PCB: SPECIFY POSITION
3D PRINTING:
3D SHELL COMPONENT SIDE SLA RESIN 9600 WHITE
3D SHELL DISPLAY SIDE SLA RESIN 8100 TRANSPARENT
3D SHELL CLOSES WITH 4 NYLON M3 10MM SCREWS AND NUTS
CHECKLIST:
NO SILKSCREEN IN CANBUS ISOLATION BARRIER
DS3231 RTC INTERRUPT ON MCU EXTI PIN
TARGET T_SWO/TRACESWO ON USART RX

SD CARD LENGTH, IMPEDANCE
USB LENGTH, IMPEDANCE
USB 10 MIL TRACE 8 MIL SPACE
50 OHM 13 MIL TRACE
TRANSMISSION LINES OVER GROUND PLANE

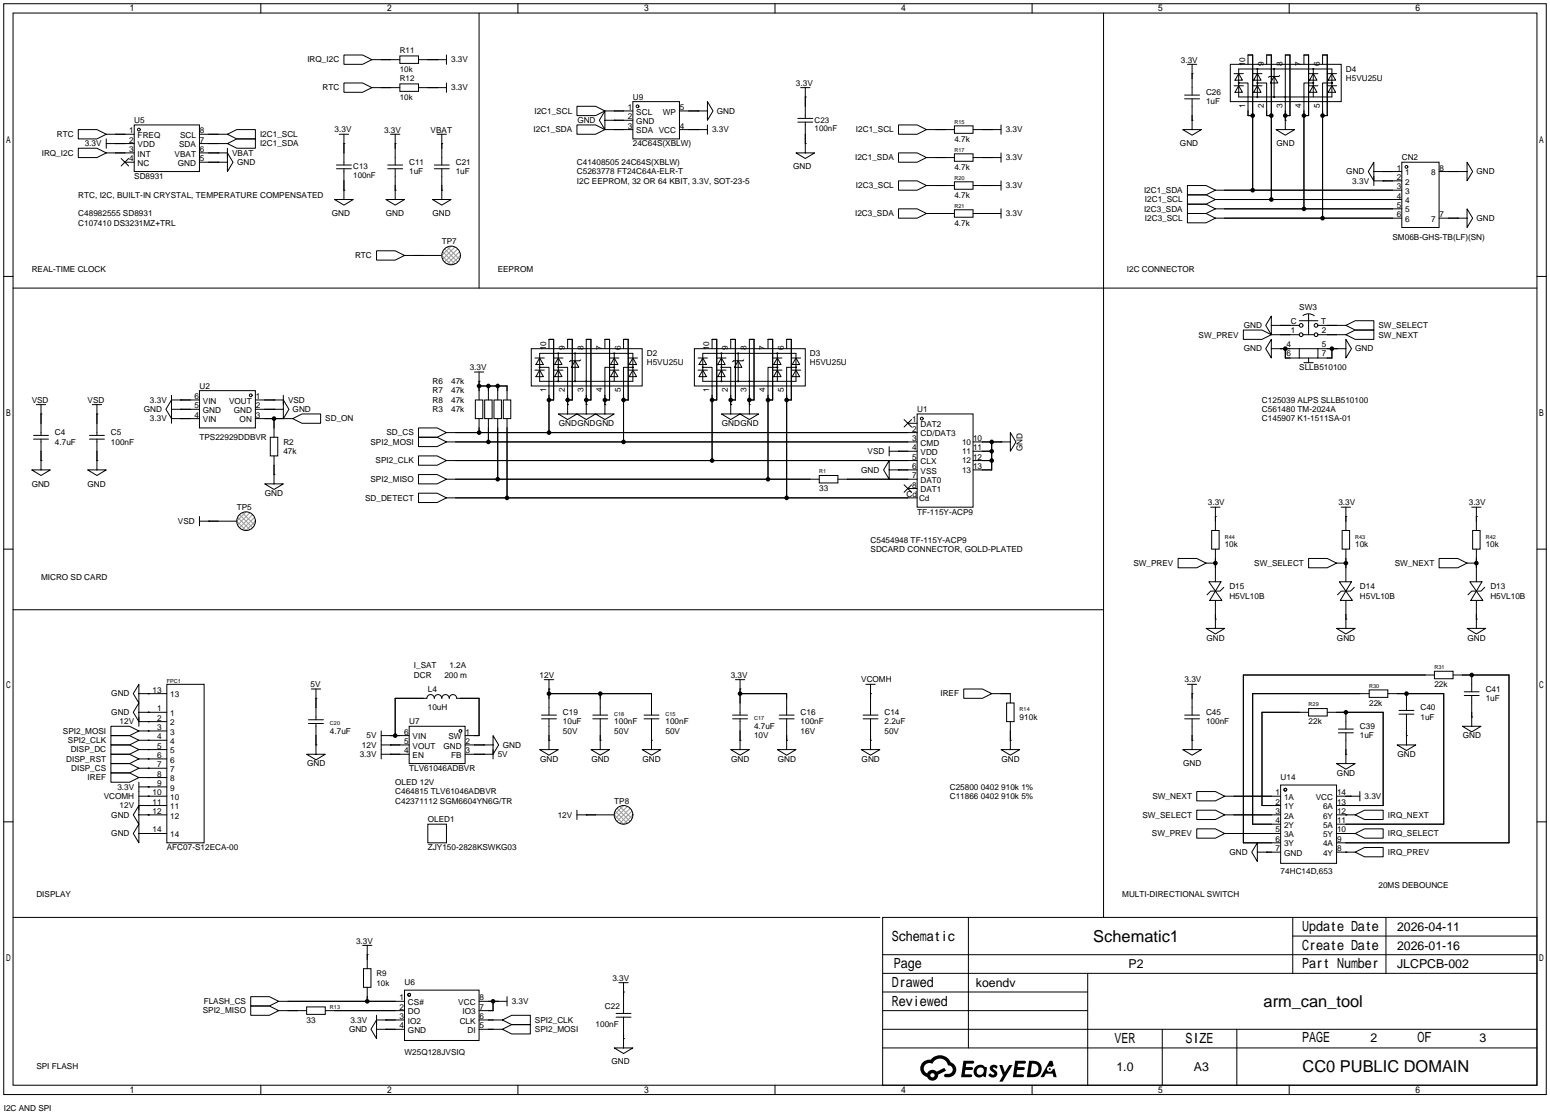
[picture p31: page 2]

C41408505 24C64S(XBLW)
C5263778 FT24C64A-ELR-T
I2C EEPROM, 32 OR 64 KBIT, 3.3V, SOT-23-5

RTC, I2C, BUILT-IN CRYSTAL, TEMPERATURE COMPENSATED
C107410 DS3231MZ+TRL

C5454948 TF-115Y-ACP9
SDCARD CONNECTOR, GOLD-PLATED

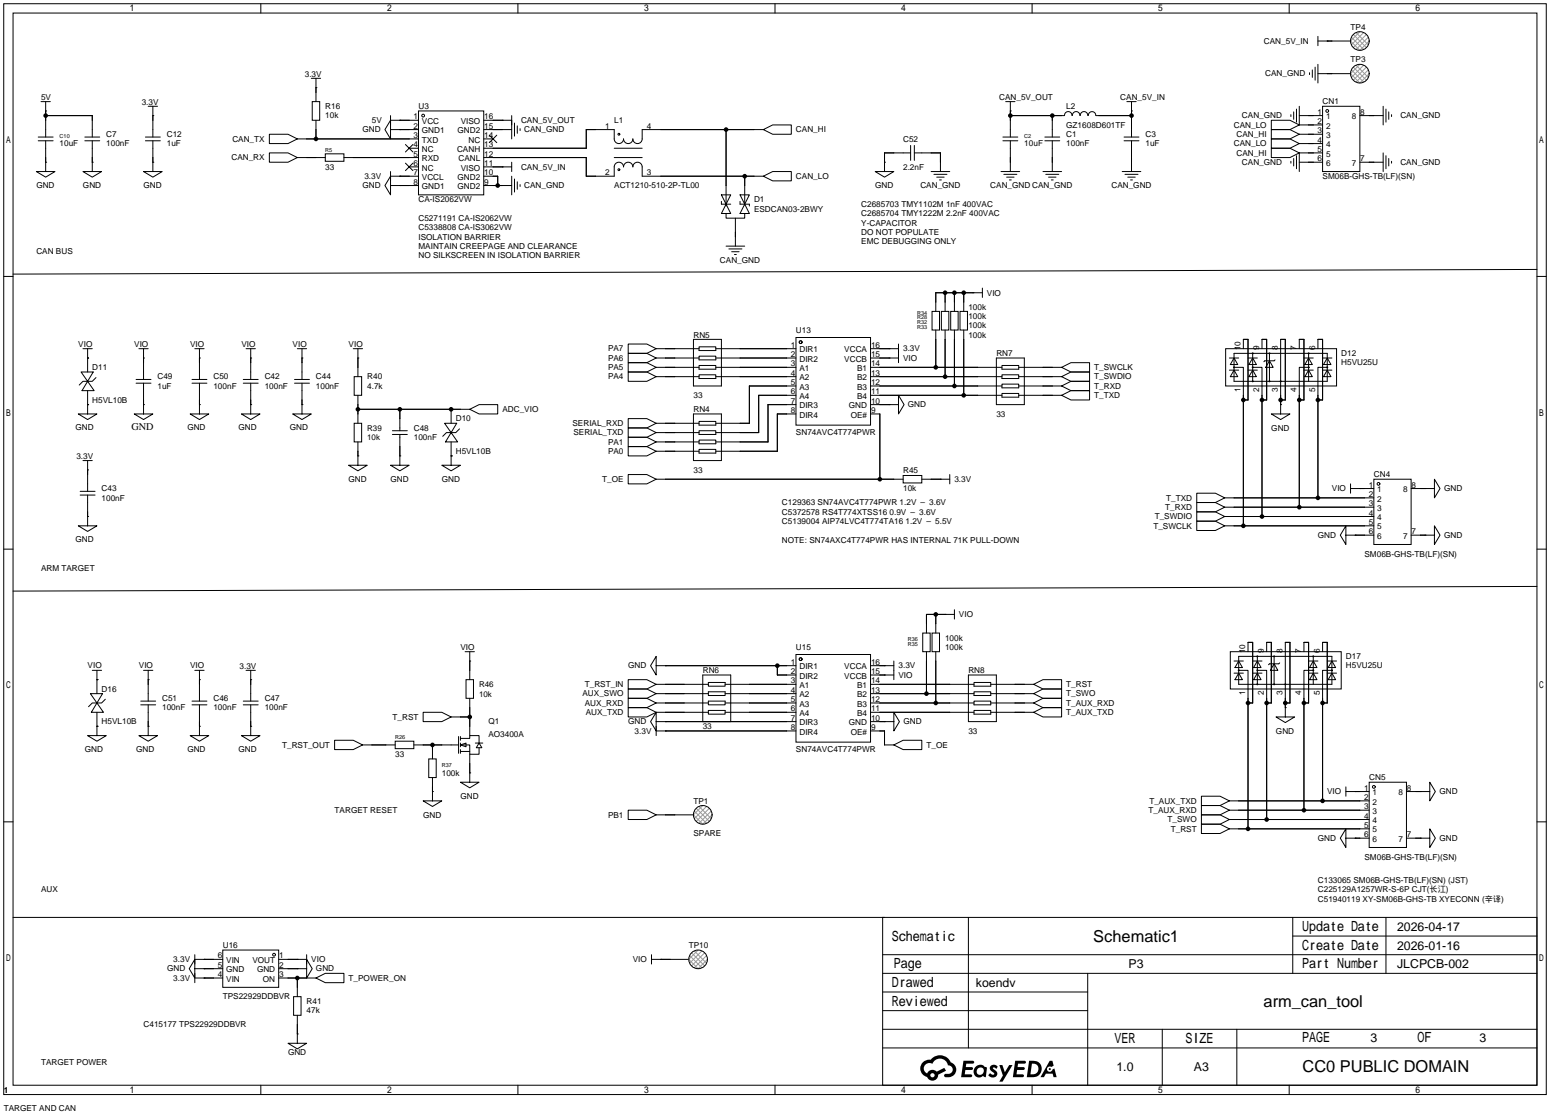
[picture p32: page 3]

ISOLATION BARRIER
MAINTAIN CREEPAGE AND CLEARANCE
NO SILKSCREEN IN ISOLATION BARRIER

C133065 SM06B-GHS-TB(LF)(SN) (JST)
C225129A1257WR-S-6P CJT(长江)
C51940119 XY-SM06B-GHS-TB XYECONN (辛译)
Update Date
Create Date
Part Number
arm_can_tool

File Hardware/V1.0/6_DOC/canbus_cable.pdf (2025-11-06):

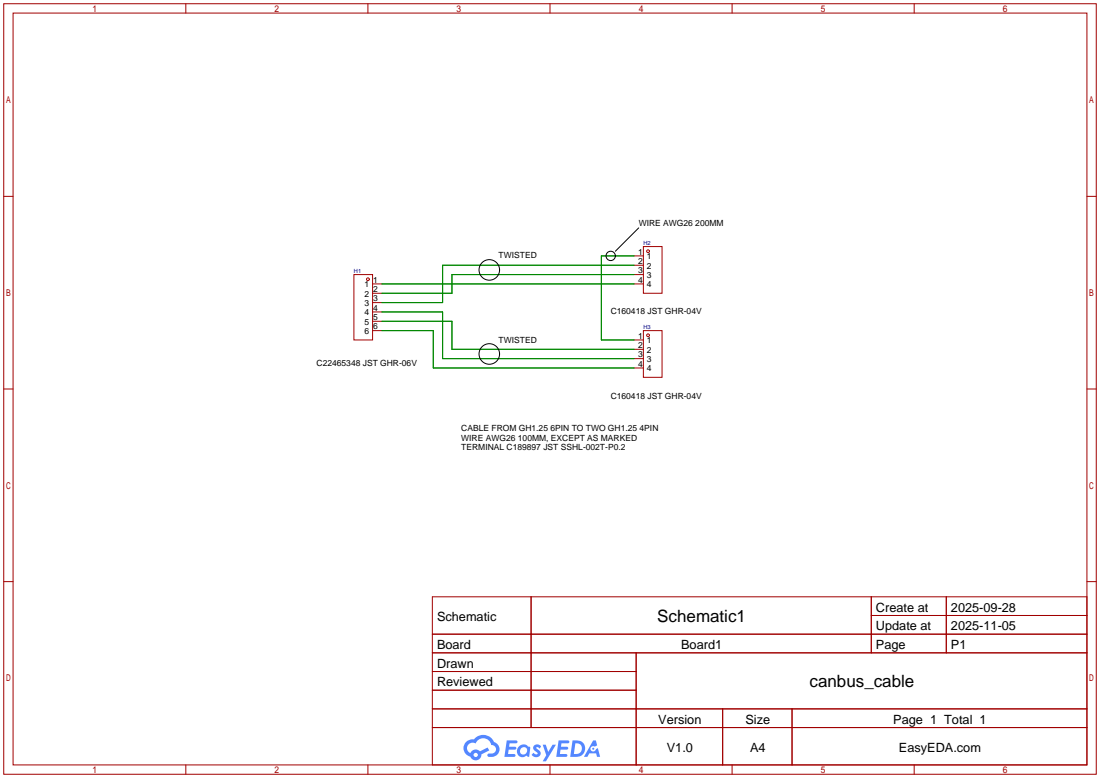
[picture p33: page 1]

CABLE FROM GH1.25 6PIN TO TWO GH1.25 4PIN
WIRE AWG26 100MM, EXCEPT AS MARKED
TERMINAL C189897 JST SSHL-002T-P0.2

Schematic | Schematic1 | Create at | 2025-09-28

Update at | 2025-11-05

Board | Board1 | Page | P1
Drawn | | canbus_cable
Reviewed

Version | Size | Page 1 Total 1
V1.0 | A4 | EasyEDA.com

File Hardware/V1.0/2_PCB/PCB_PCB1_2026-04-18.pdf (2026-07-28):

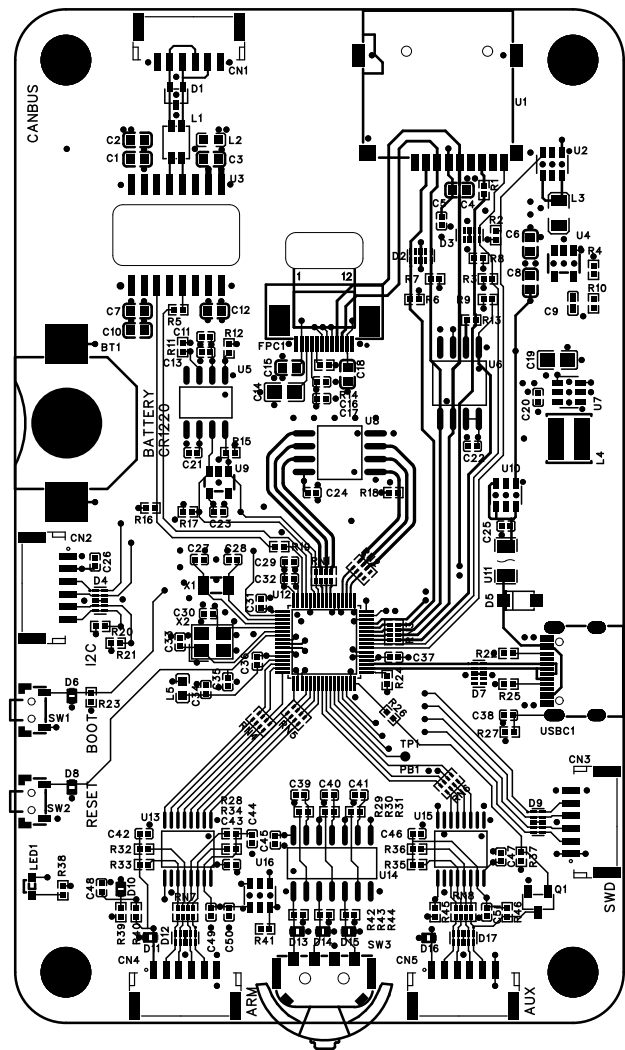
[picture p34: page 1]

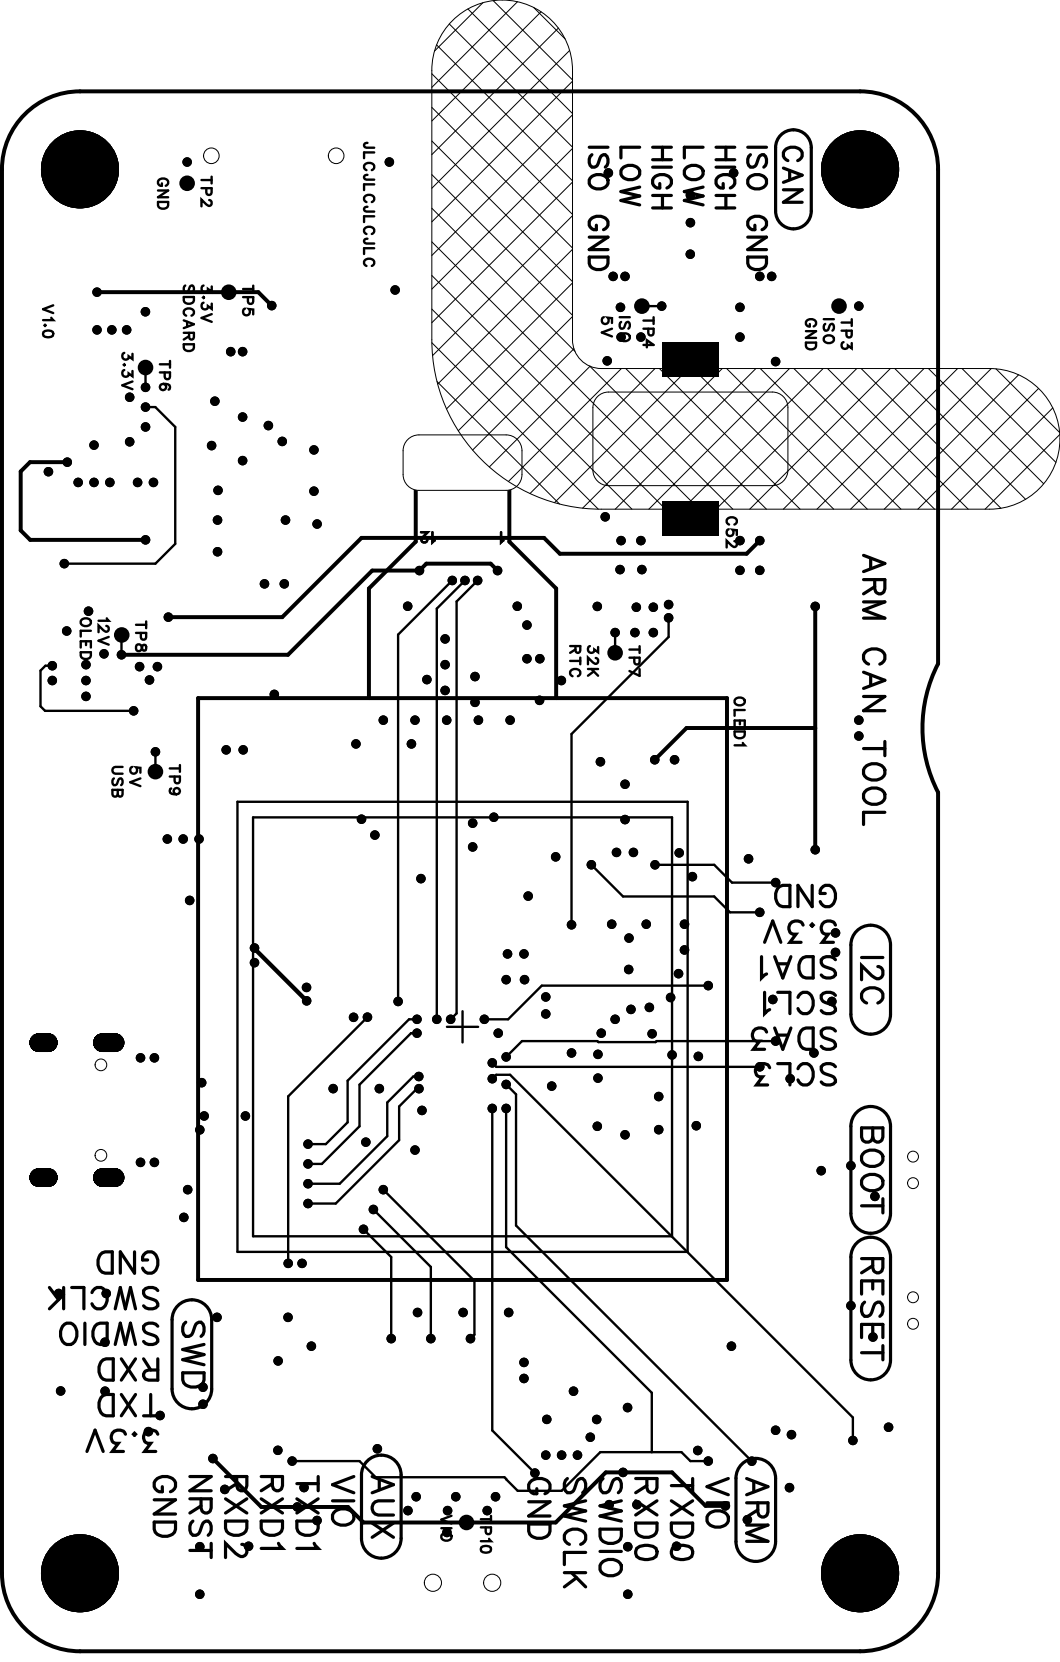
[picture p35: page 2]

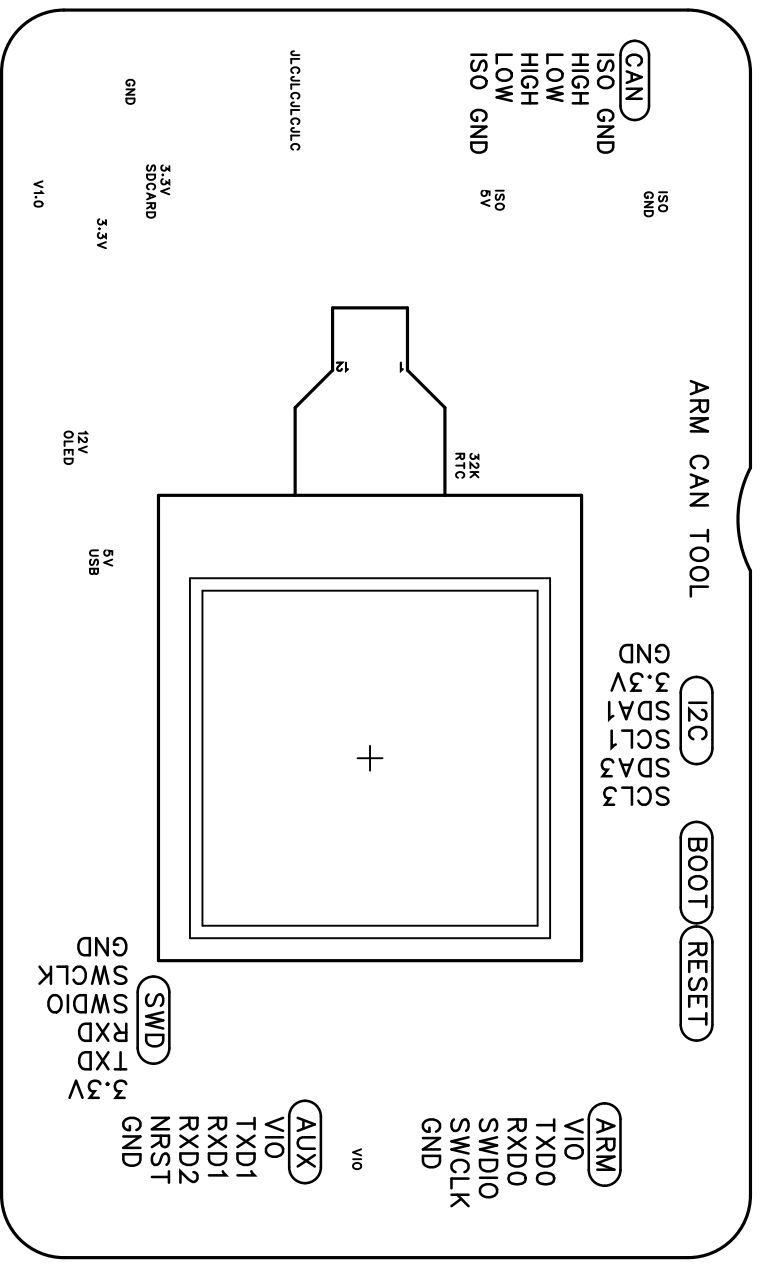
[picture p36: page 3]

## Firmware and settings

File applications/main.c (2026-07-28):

/*
 * Copyright (c) 2006-2021, RT-Thread Development Team
 *
 * SPDX-License-Identifier: Apache-2.0
 *
 * Change Logs:
 * Date           Author       Notes
 * 2023-10-18     shelton      first version
 */

#include <rtthread.h>
#include <rtdevice.h>
#define DBG_TAG "MAIN"
#define DBG_LVL DBG_INFO
#include <rtdbg.h>

#include <drv_common.h>
#include <drv_gpio.h>
#include "ds3231_util.h"
#include "watchdog.h"
#include "settings.h"
#include "logger.h"
#include "pins.h"

int main(void)
{
    crm_periph_clock_enable(CRM_GPIOA_PERIPH_CLOCK, TRUE);
    crm_periph_clock_enable(CRM_GPIOB_PERIPH_CLOCK, TRUE);
    crm_periph_clock_enable(CRM_GPIOC_PERIPH_CLOCK, TRUE);
    crm_periph_clock_enable(CRM_GPIOD_PERIPH_CLOCK, TRUE);
    crm_periph_clock_enable(CRM_GPIOF_PERIPH_CLOCK, TRUE);
    LOG_I("ready");

    ds3231_sync();
    logger("\r\nboot\r\n", 8);

    while (1)
    {
        rt_thread_mdelay(5000);
        feed_watchdog();
    }
}

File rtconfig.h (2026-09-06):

#ifndef RT_CONFIG_H__
#define RT_CONFIG_H__

/* RT-Thread Kernel */

/* klibc options */

/* rt_vsnprintf options */

/* end of rt_vsnprintf options */

/* rt_vsscanf options */

/* end of rt_vsscanf options */

/* rt_memset options */

/* end of rt_memset options */

/* rt_memcpy options */

/* end of rt_memcpy options */

/* rt_memmove options */

/* end of rt_memmove options */

/* rt_memcmp options */

/* end of rt_memcmp options */

/* rt_strstr options */

/* end of rt_strstr options */

/* rt_strcasecmp options */

/* end of rt_strcasecmp options */

/* rt_strncpy options */

/* end of rt_strncpy options */

/* rt_strcpy options */

/* end of rt_strcpy options */

/* rt_strncmp options */

/* end of rt_strncmp options */

/* rt_strcmp options */

/* end of rt_strcmp options */

/* rt_strlen options */

/* end of rt_strlen options */

/* rt_strnlen options */

/* end of rt_strnlen options */
/* end of klibc options */
#define RT_NAME_MAX 16
#define RT_CPUS_NR 1
#define RT_ALIGN_SIZE 8
#define RT_THREAD_PRIORITY_32
#define RT_THREAD_PRIORITY_MAX 32
#define RT_TICK_PER_SECOND 1000
#define RT_USING_OVERFLOW_CHECK
#define RT_USING_HOOK
#define RT_HOOK_USING_FUNC_PTR
#define RT_USING_IDLE_HOOK
#define RT_IDLE_HOOK_LIST_SIZE 4
#define IDLE_THREAD_STACK_SIZE 512
#define RT_USING_TIMER_SOFT
#define RT_TIMER_THREAD_PRIO 4
#define RT_TIMER_THREAD_STACK_SIZE 512

/* kservice options */

/* end of kservice options */
#define RT_USING_DEBUG
#define RT_DEBUGING_ASSERT
#define RT_DEBUGING_COLOR
#define RT_DEBUGING_CONTEXT

/* Inter-Thread communication */

#define RT_USING_SEMAPHORE
#define RT_USING_MUTEX
#define RT_USING_EVENT
#define RT_USING_MAILBOX
#define RT_USING_MESSAGEQUEUE
/* end of Inter-Thread communication */

/* Memory Management */

#define RT_USING_MEMPOOL
#define RT_USING_SMALL_MEM
#define RT_USING_MEMHEAP
#define RT_MEMHEAP_FAST_MODE
#define RT_USING_SMALL_MEM_AS_HEAP
#define RT_USING_HEAP
/* end of Memory Management */
#define RT_USING_DEVICE
#define RT_USING_CONSOLE
#define RT_CONSOLEBUF_SIZE 128
#define RT_CONSOLE_DEVICE_NAME "uart6"
#define RT_USING_CONSOLE_OUTPUT_CTL
#define RT_VER_NUM 0x50300
#define RT_BACKTRACE_LEVEL_MAX_NR 32
/* end of RT-Thread Kernel */
#define RT_USING_HW_ATOMIC
#define ARCH_USING_HW_ATOMIC_8
#define ARCH_USING_HW_ATOMIC_16
#define RT_USING_CPU_FFS
#define ARCH_ARM
#define ARCH_ARM_CORTEX_M
#define ARCH_ARM_CORTEX_M4

/* RT-Thread Components */

#define RT_USING_COMPONENTS_INIT
#define RT_USING_USER_MAIN
#define RT_MAIN_THREAD_STACK_SIZE 2560
#define RT_MAIN_THREAD_PRIORITY 10
#define RT_USING_MSH
#define RT_USING_FINSH
#define FINSH_USING_MSH
#define FINSH_THREAD_NAME "tshell"
#define FINSH_THREAD_PRIORITY 20
#define FINSH_THREAD_STACK_SIZE 2048
#define FINSH_USING_HISTORY
#define FINSH_HISTORY_LINES 5
#define FINSH_USING_SYMTAB
#define FINSH_CMD_SIZE 80
#define MSH_USING_BUILT_IN_COMMANDS
#define FINSH_USING_DESCRIPTION
#define FINSH_ARG_MAX 10
#define FINSH_USING_OPTION_COMPLETION

/* DFS: device virtual file system */

#define RT_USING_DFS
#define DFS_USING_POSIX
#define DFS_USING_WORKDIR
#define DFS_FD_MAX 16
#define RT_USING_DFS_V1
#define DFS_FILESYSTEMS_MAX 4
#define DFS_FILESYSTEM_TYPES_MAX 4
#define RT_USING_DFS_ELMFAT

/* elm-chan's FatFs, Generic FAT Filesystem Module */

#define RT_DFS_ELM_CODE_PAGE 437
#define RT_DFS_ELM_WORD_ACCESS
#define RT_DFS_ELM_USE_LFN_3
#define RT_DFS_ELM_USE_LFN 3
#define RT_DFS_ELM_LFN_UNICODE_0
#define RT_DFS_ELM_LFN_UNICODE 0
#define RT_DFS_ELM_MAX_LFN 255
#define RT_DFS_ELM_DRIVES 2
#define RT_DFS_ELM_MAX_SECTOR_SIZE 512
#define RT_DFS_ELM_USE_ERASE
#define RT_DFS_ELM_REENTRANT
#define RT_DFS_ELM_MUTEX_TIMEOUT 3000
#define RT_DFS_ELM_USE_EXFAT
/* end of elm-chan's FatFs, Generic FAT Filesystem Module */
#define RT_USING_DFS_DEVFS
#define RT_USING_DFS_ROMFS
/* end of DFS: device virtual file system */
#define RT_USING_FAL
#define FAL_PART_HAS_TABLE_CFG
#define FAL_USING_SFUD_PORT
#define FAL_USING_NOR_FLASH_DEV_NAME "norflash0"
#define FAL_DEV_NAME_MAX 24
#define FAL_DEV_BLK_MAX 6

/* Device Drivers */
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

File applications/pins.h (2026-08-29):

#ifndef PINS_H
#define PINS_H

#include <rtthread.h>
#include <drv_gpio.h>

#define DISP_CS_PIN          GET_PIN(D, 2)
#define DISP_DC_PIN          GET_PIN(F, 7)
#define DISP_RST_PIN         GET_PIN(C, 12)
#define LED0_PIN             GET_PIN(C, 2)
#define SD_CS_PIN            GET_PIN(A, 11)
#define SD_DETECT_PIN        GET_PIN(C, 9)
#define SD_ON_PIN            GET_PIN(C, 8)
#define SW_NEXT_PIN          GET_PIN(B, 12)
#define SW_PREV_PIN          GET_PIN(B, 2)
#define SW_SELECT_PIN        GET_PIN(B, 10)
#define TARGET_RST_IN_PIN    GET_PIN(B, 0)
#define TARGET_RST_OUT_PIN   GET_PIN(B, 13)
#define TARGET_SWCLK_DIR_PIN GET_PIN(A, 7)
#define TARGET_SWCLK_PIN     GET_PIN(A, 5)
#define TARGET_SWDIO_DIR_PIN GET_PIN(A, 6)
#define TARGET_SWDIO_PIN     GET_PIN(A, 4)
#define TARGET_TDI_DIR_PIN   GET_PIN(A, 0)
#define TARGET_TDI_PIN       GET_PIN(A, 2)
#define TARGET_TDO_DIR_PIN   GET_PIN(A, 1)
#define TARGET_TDO_PIN       GET_PIN(A, 3)
#define TARGET_OE_PIN        GET_PIN(F, 4)
#define TARGET_POWER_PIN     GET_PIN(F, 5)
#define TARGET_TXD_DIR_PIN   TARGET_TDI_DIR_PIN
#define TARGET_RXD_DIR_PIN   TARGET_TDO_DIR_PIN

#endif

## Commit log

2026-07-28 first release
    [3DShell_3DShell_PCB1_B.stl, 3DShell_3DShell_PCB1_T.stl, BOM_Board1_PCB1_2026-04-18.xlsx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]
2026-08-06 dma: no busy wait
2026-08-09 Arm DWT tracing
2026-08-26 arm mtb trace
2026-08-26 semihosting port glue
2026-08-26 pin blackmagic to v2.0.0
2026-08-30 docs: canbus hook
2026-08-31 lower spi flash speed
2026-09-03 at32 workbench: sync
    [arm_can_tool_WorkBench.xlsx]
2026-09-05 lua: timer
